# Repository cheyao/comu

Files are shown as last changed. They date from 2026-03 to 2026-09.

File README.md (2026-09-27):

# Comu

A bite-sized CH32V203 board that fits inside your USB port.

Intrested? Sign up to the [newsletter](https://cyao.dev/subscribe.html) for info! I might do a Crowd Supply campaign if there's intrest. (No spam and very infrequent emails I promise)

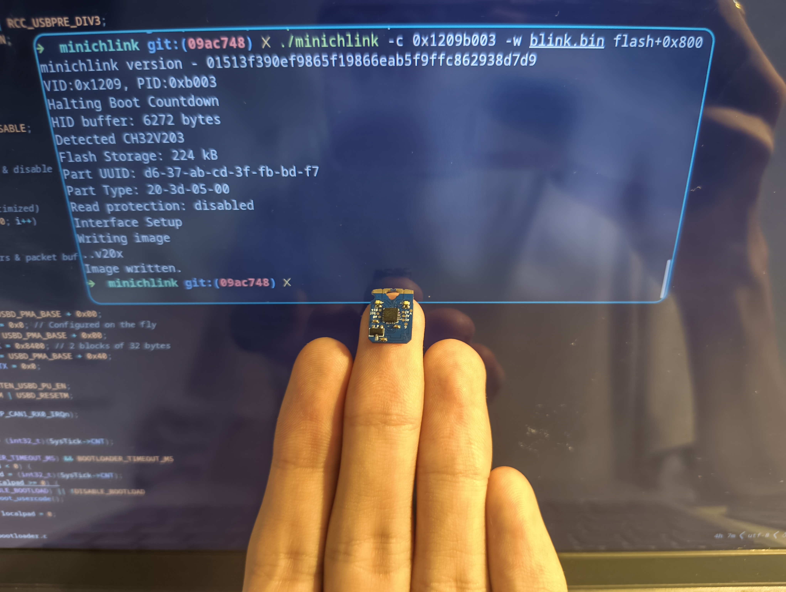
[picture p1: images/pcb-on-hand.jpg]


Comu is a tiny CH32V203 RISC-V computer that fits inside a USB port. It is user programmable, fitted with a custom bootloader, has four captive touch buttons and two LEDs. The board is supported by [ch32fun](https://github.com/cnlohr/ch32fun), allowing easy and lightweight RISC-V bare-metal development.

The CH32V203 is equipped with 248KB of Flash and 20KB of SRAM, more than enough for most embedded applications. The chip also has a wide array of peripherals, including DMA and a 12bit ADC, allowing for a wide variety of uses. The board also exposes 6 GPIO pins via testpoints, allowing it to be embedded on custom boards for further use.

It can also easily act as a **USB HID device**, allowing portable key injections to avoid repetitive typing. With it 4 captive buttons, you can make it into a sliding volume adjuster, computer sleep trigger, screen capture device and more!

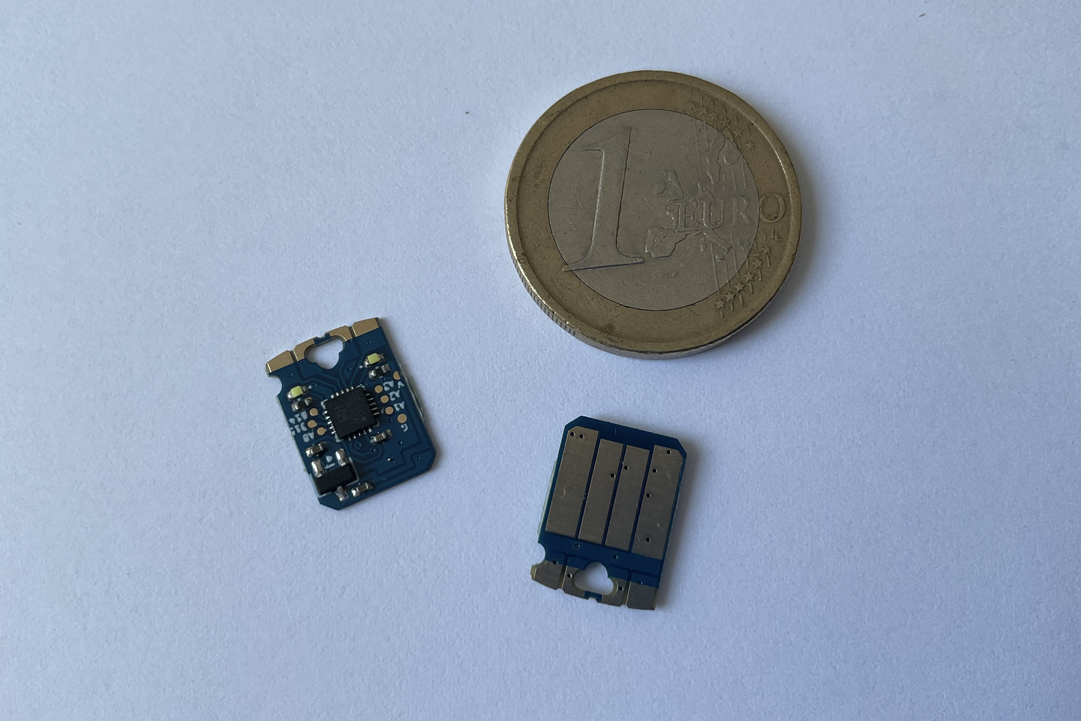
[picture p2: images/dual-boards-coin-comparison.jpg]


### No bloat, no weight

Using bare-metal programming in C/C++, the RISC-V program created for this chip contains 0 bloat. The minimal size of a blinky is only **40 bytes**, compared to 324KB on Arduino Pico or 12KB with Pico SDK. The [CH32V203 RM](https://www.wch-ic.com/downloads/CH32FV2x_V3xRM_PDF.html) contains all information needed to use the MCU, from register descriptions to memory layout.

The board is also very lightweight, weighing merely **0.4g** (0.2g without case). Measuring a mere 13x9.4mm, it occupies nearly no space.

Even in such constrained space, the board still boasts rich peripherals. You can directly access 2 white LEDs and 4 captive buttons. The captive buttons are double-sided edge-plated, ensuring accurate touch sensing. It is also easy to use thanks to the CH32V203's touchkey peripheral, directly handling all the troublesome parts of touch sensing. (Example in `examples/touch` folder).

### USB explorer

The CH32V203 is perfect for USB packet exploring. Its bare and well-documented USBD peripheral allows you to manipulate raw packets, while taking care of troublesome parts such as transaction handling. You can directly pair this with [usbmon](https://docs.kernel.org/usb/usbmon.html) on Wireshark to explore how USB transactions work.

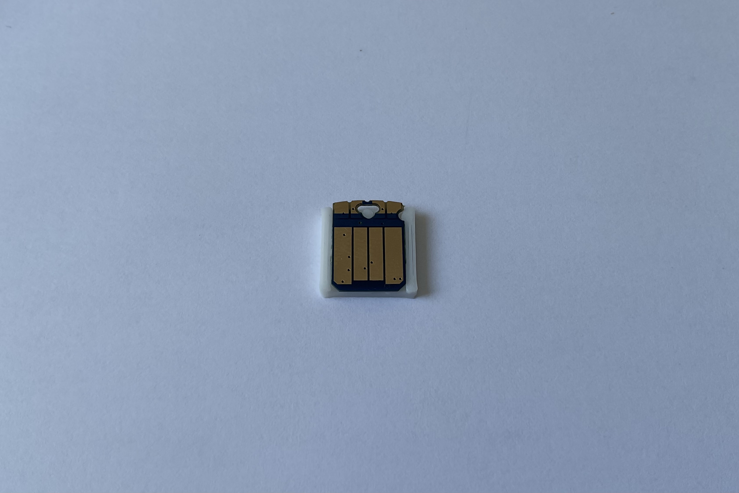
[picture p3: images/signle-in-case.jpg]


### Custom bootloader

The board comes pre-programmed with a sleek custom USB bootloader to compensate for the lack of a BOOT0 button and the large size of the official bootloader. The custom bootloader is only **2KiB** in size, freeing up the 28KiB of boot flash for user use.

The bootloader is also completely open source; check out its source code in the `bootloader` folder. The only quirk is that the programs must be linked to `0x800` and flashed to 0x800, but that is taken care by the provided Makefile in the examples folder.

### Bare metal isn't your thing?

No worries! The CH32V203 is also supported by a wide array of tools: Rust via [ch32-hal](https://github.com/ch32-rs/ch32-hal), Arduino via [arduino_core_ch32](https://github.com/openwch/arduino_core_ch32), or normal WCH-HAL via [Mounriver Studio II](https://mounriver.com/download).

USB communication can be completely handled by libraries such as [tinyusb](https://docs.tinyusb.org/en/latest/index.html) or [ch32fun's usbd lib](https://github.com/cnlohr/ch32fun/blob/master/extralibs/usbd.c). All raw peripherals can also be hidden by Mounriver's HAL.

### Tons of examples

There are tons of examples in the `examples` folder on this repo, and also compatible with the examples in [ch32fun](https://github.com/cnlohr/ch32fun).

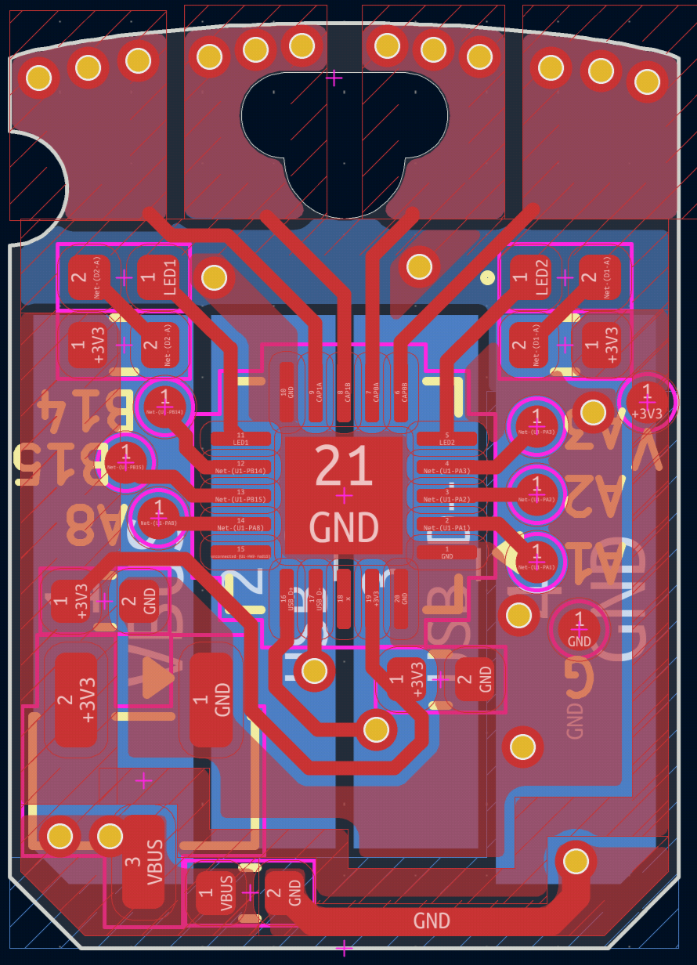
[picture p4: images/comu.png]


### Features

- [CH32V203](https://wch-ic.com/products/CH32V203.html) 32bit RISC-V MCU
    - 224KB Flash, 24KB Boot Flash, 20KB SRAM (64KB 0-wait Flash and 160KB Normal Flash)
    - 144MHz with internal oscillator
    - 12bit ADC
    - 49.3 μA/MHz @ run and 19.4 μA/MHz @ sleep
    - USB full speed peripheral
- 4x Captive touch buttons w/ castellated edges
- 2x LEDs
- 6x GPIOs broken out via testpads
- Fits in a USB-A connector

### Pins

- LED1: PB11
- LED2: PA4
- Captive touch:
    - A5 (PA5)
    - A7 (PA7)
    - A8 (PB0)
    - A9 (PB1)
- GPIOs: PB14, PB15, PA1, PA2, PA3, PA8

### Usage

Dependencies: Make, riscv64-gcc, libusb (Checkout dependency list [here](https://github.com/cnlohr/ch32fun/wiki/Installation))

Clone this respository and pull the submodules:

```
$ git clone https://github.com/cheyao/comu
$ cd comu
$ git submodule update --init --recursive
```

Go into the examples folder and build an example:

```
$ cd examples/blink
$ make
```

Now, the example should be built. When you insert your Comu into your USB port, it should stay in the bootloader for the first 5 seconds. You can then re-run `make flash` to flash the binary onto the chip!

Now you can make your applications! I recommend starting off by copying an example, as you need to flash to address `flash+0x800` to avoid overwriting the custom bootloader.

If the flashing isn't working, please read through this [wiki](https://github.com/cnlohr/ch32fun/wiki/Installation) for operating system setup, and try re-building minichnlink. (I've submitted a few new patches for the ch32v203 flashing a week ago)

### Can I get one?

### Attributions

Form factor credit goes to tomu.

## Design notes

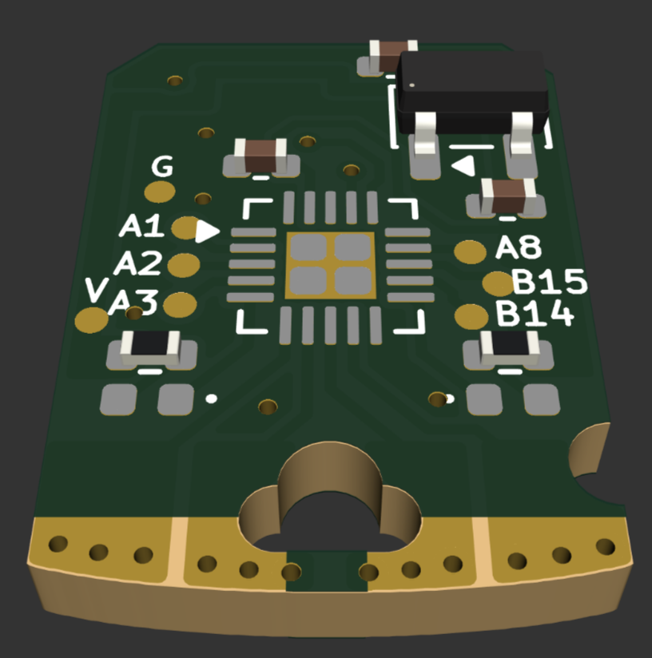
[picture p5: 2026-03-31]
images/3d.png

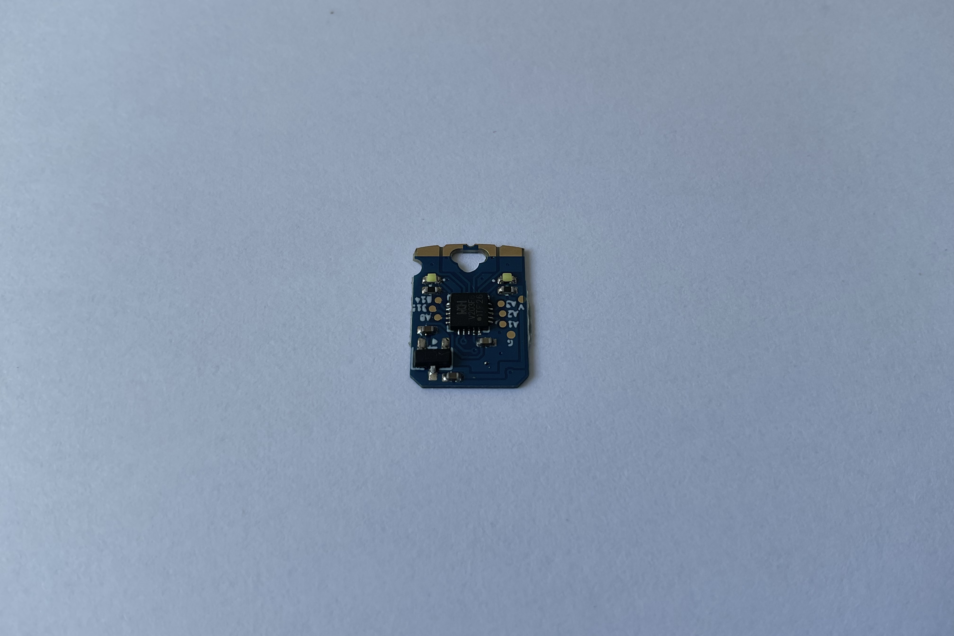
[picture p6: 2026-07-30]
images/single-top.jpg

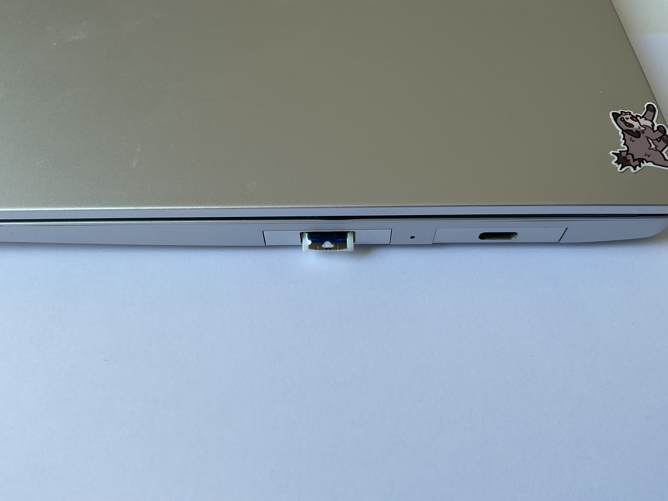
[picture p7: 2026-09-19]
images/laptop-inserted.jpg

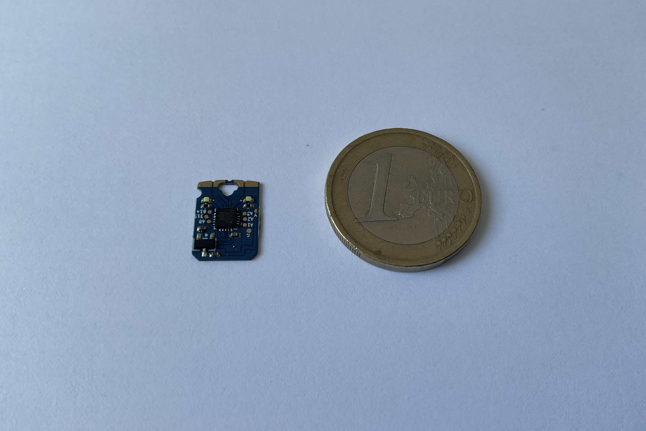
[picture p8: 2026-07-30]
images/single-coin-comparison.jpg

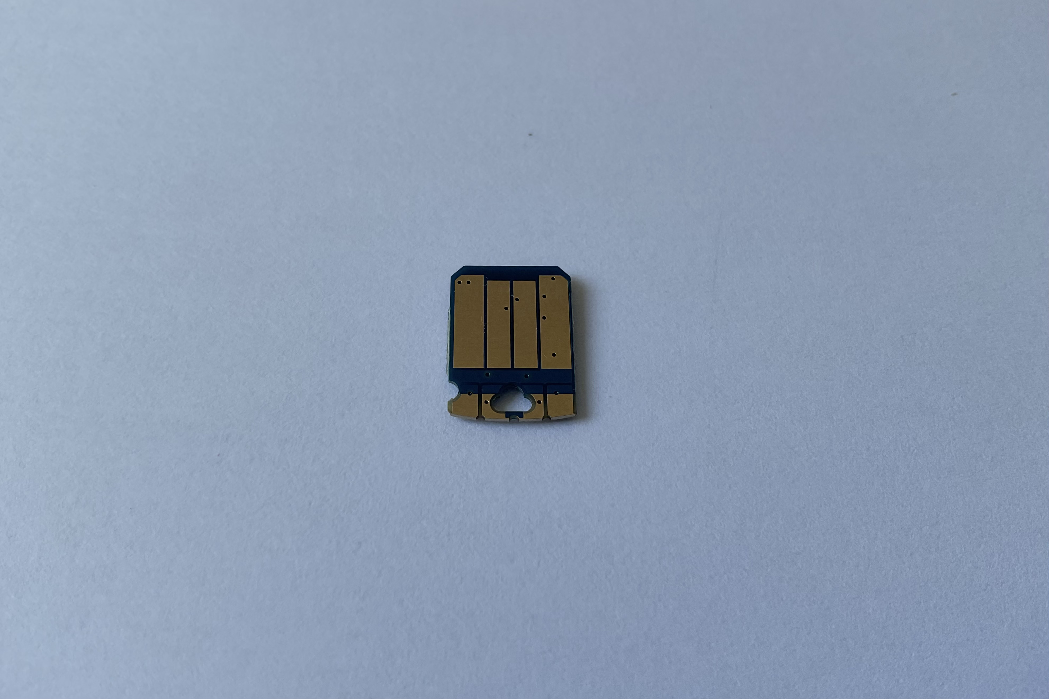
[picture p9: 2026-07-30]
images/single-bottom.jpg

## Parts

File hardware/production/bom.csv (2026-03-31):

Designator | Footprint | Quantity | Value | LCSC Part #
C1_56, C1_55, C1_54, C1_53, C1_52, C1_51, C1_50, C1_49, C1_48, C1_47, C1_46, C1_45, C1_44, C1_43, C1_42, C1_41, C1_40, C1_39, C1_38, C1_37, C1_36, C1_35, C1_34, C1_33, C1_32, C1_31, C1_30, C1_29, C1_28, C1_27, C1_26, C1_25, C1_24, C1_23, C1_22, C1_21, C1_20, C1_19, C1_18, C1_17, C1_16, C1_15, C1_14, C1_13, C1_12, C1_11, C1_10, C1_9, C1_8, C1_7, C1_6, C1_5, C1_4, C1_3, C1_2, C1, C2_56, C2_55, C2_54, C2_53, C2_52, C2_51, C2_50, C2_49, C2_48, C2_47, C2_46, C2_45, C2_44, C2_43, C2_42, C2_41, C2_40, C2_39, C2_38, C2_37, C2_36, C2_35, C2_34, C2_33, C2_32, C2_31, C2_30, C2_29, C2_28, C2_27, C2_26, C2_25, C2_24, C2_23, C2_22, C2_21, C2_20, C2_19, C2_18, C2_17, C2_16, C2_15, C2_14, C2_13, C2_12, C2_11, C2_10, C2_9, C2_8, C2_7, C2_6, C2_5, C2_4, C2_3, C2_2, C2 | 0402 | 112 | 1uF | C52923
C3_56, C3_55, C3_54, C3_53, C3_52, C3_51, C3_50, C3_49, C3_48, C3_47, C3_46, C3_45, C3_44, C3_43, C3_42, C3_41, C3_40, C3_39, C3_38, C3_37, C3_36, C3_35, C3_34, C3_33, C3_32, C3_31, C3_30, C3_29, C3_28, C3_27, C3_26, C3_25, C3_24, C3_23, C3_22, C3_21, C3_20, C3_19, C3_18, C3_17, C3_16, C3_15, C3_14, C3_13, C3_12, C3_11, C3_10, C3_9, C3_8, C3_7, C3_6, C3_5, C3_4, C3_3, C3_2, C3 | 0402 | 56 | 100nF | C1525
D1_56, D1_55, D1_54, D1_53, D1_52, D1_51, D1_50, D1_49, D1_48, D1_47, D1_46, D1_45, D1_44, D1_43, D1_42, D1_41, D1_40, D1_39, D1_38, D1_37, D1_36, D1_35, D1_34, D1_33, D1_32, D1_31, D1_30, D1_29, D1_28, D1_27, D1_26, D1_25, D1_24, D1_23, D1_22, D1_21, D1_20, D1_19, D1_18, D1_17, D1_16, D1_15, D1_14, D1_13, D1_12, D1_11, D1_10, D1_9, D1_8, D1_7, D1_6, D1_5, D1_4, D1_3, D1_2, D1, D2_56, D2_55, D2_54, D2_53, D2_52, D2_51, D2_50, D2_49, D2_48, D2_47, D2_46, D2_45, D2_44, D2_43, D2_42, D2_41, D2_40, D2_39, D2_38, D2_37, D2_36, D2_35, D2_34, D2_33, D2_32, D2_31, D2_30, D2_29, D2_28, D2_27, D2_26, D2_25, D2_24, D2_23, D2_22, D2_21, D2_20, D2_19, D2_18, D2_17, D2_16, D2_15, D2_14, D2_13, D2_12, D2_11, D2_10, D2_9, D2_8, D2_7, D2_6, D2_5, D2_4, D2_3, D2_2, D2 | 0402 | 112 | LED | C22355736
R1_56, R1_55, R1_54, R1_53, R1_52, R1_51, R1_50, R1_49, R1_48, R1_47, R1_46, R1_45, R1_44, R1_43, R1_42, R1_41, R1_40, R1_39, R1_38, R1_37, R1_36, R1_35, R1_34, R1_33, R1_32, R1_31, R1_30, R1_29, R1_28, R1_27, R1_26, R1_25, R1_24, R1_23, R1_22, R1_21, R1_20, R1_19, R1_18, R1_17, R1_16, R1_15, R1_14, R1_13, R1_12, R1_11, R1_10, R1_9, R1_8, R1_7, R1_6, R1_5, R1_4, R1_3, R1_2, R1, R2_56, R2_55, R2_54, R2_53, R2_52, R2_51, R2_50, R2_49, R2_48, R2_47, R2_46, R2_45, R2_44, R2_43, R2_42, R2_41, R2_40, R2_39, R2_38, R2_37, R2_36, R2_35, R2_34, R2_33, R2_32, R2_31, R2_30, R2_29, R2_28, R2_27, R2_26, R2_25, R2_24, R2_23, R2_22, R2_21, R2_20, R2_19, R2_18, R2_17, R2_16, R2_15, R2_14, R2_13, R2_12, R2_11, R2_10, R2_9, R2_8, R2_7, R2_6, R2_5, R2_4, R2_3, R2_2, R2 | 0402 | 112 | 1k | C11702
U1_56, U1_55, U1_54, U1_53, U1_52, U1_51, U1_50, U1_49, U1_48, U1_47, U1_46, U1_45, U1_44, U1_43, U1_42, U1_41, U1_40, U1_39, U1_38, U1_37, U1_36, U1_35, U1_34, U1_33, U1_32, U1_31, U1_30, U1_29, U1_28, U1_27, U1_26, U1_25, U1_24, U1_23, U1_22, U1_21, U1_20, U1_19, U1_18, U1_17, U1_16, U1_15, U1_14, U1_13, U1_12, U1_11, U1_10, U1_9, U1_8, U1_7, U1_6, U1_5, U1_4, U1_3, U1_2, U1 | QFN-20-1EP_3x3mm_P0.4mm_EP1.65x1.65mm | 56 | CH32V203F8U6 | C7570477
U2_56, U2_55, U2_54, U2_53, U2_52, U2_51, U2_50, U2_49, U2_48, U2_47, U2_46, U2_45, U2_44, U2_43, U2_42, U2_41, U2_40, U2_39, U2_38, U2_37, U2_36, U2_35, U2_34, U2_33, U2_32, U2_31, U2_30, U2_29, U2_28, U2_27, U2_26, U2_25, U2_24, U2_23, U2_22, U2_21, U2_20, U2_19, U2_18, U2_17, U2_16, U2_15, U2_14, U2_13, U2_12, U2_11, U2_10, U2_9, U2_8, U2_7, U2_6, U2_5, U2_4, U2_3, U2_2, U2 | SOT-23-3 | 56 | XC6206PxxxMR | C5446

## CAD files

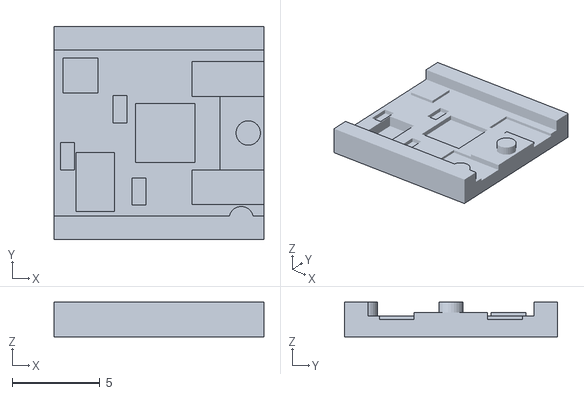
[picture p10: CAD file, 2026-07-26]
case/case-v3.stl
12.0 x 12.2 x 2.00

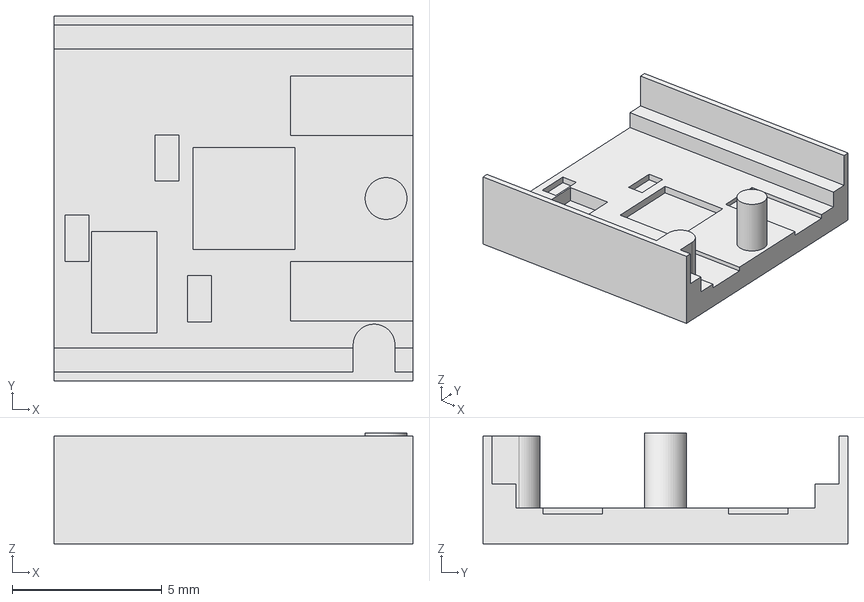
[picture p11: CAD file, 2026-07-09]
case/case-v1.step
12.0 x 12.2 x 3.70 mm

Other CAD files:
case/case.FCStd
case/case-v2.stl

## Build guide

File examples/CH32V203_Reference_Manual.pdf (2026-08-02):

# CH32F/V20x_V30x_V31x Reference Manual

V2.5
https://wch-ic.com

## Overview

CH32F20x is a general-purpose microcontroller based on the ARM○R CortexTM-M3 core, and is compatible with most ARM tools and software. It provides rich communication interfaces and control units, which are suitable for most embedded fields such as control, connection, synthesis, etc.
CH32V20x, CH32V30x and CH32V31x series are industrial-grade general-purpose microcontrollers based on 32-bit RISC-V instruction set and architecture. Different core models are matched according to the differences in product performance and resources. CH32V203 uses QingKe V4B core to support hardware interrupt stack to improve interrupt response efficiency; CH32V208 uses QingKe V4C core to further accelerate the speed of hardware division and increases memory protection; CH32V303/305/307/317 uses QingKe V4F core to further support hardware floating-point operations. This series of products are loaded with a wealth of peripheral interfaces and functional modules. Its internal organizational structure meets the low-cost and low-power embedded application scenarios.
For users' application development, this manual provides detailed use information of CH32F20x series, CH32V20x series, CH32V30x series and CH32V31x series products. It is suitable for different memory capacity, functional resources and packaged products in the series. If there are any differences, special instructions will be made in the corresponding functional chapter.
Note: (1) CH32F20x includes: CH32F203, CH32F205, CH32F207, CH32F208;
(2) CH32V20x includes:CH32V203, CH32V208;
(3) CH32V30x includes:CH32V303, CH32V305, CH32V307;
(4) CH32V31x includes:CH32V317.

Please refer to the following datasheet for the device characteristics of this series. CH32F20x_D6: CH32F203DS0
CH32F20x_D8, CH32F20x_D8C:CH32F207DS0.
CH32F20x_D8W: CH32F208DS0.
CH32V20x_D6, CH32V20x_D8: CH32V203DS0. CH32V20x_D8W:CH32V208DS0.
CH32V30x_D8, CH32V30x_D8C, CH32V31x_D8C: CH32V307DS0.

For information about the ARM○R CortexTM-M3 core, please refer to the ARM○R Cortex○R -M3 Processor Technical Reference Manual Revision r2p1, which can be downloaded from the ARM website.
For information about the RISC-V core, please refer to QingKeV4_Processor_Manual.

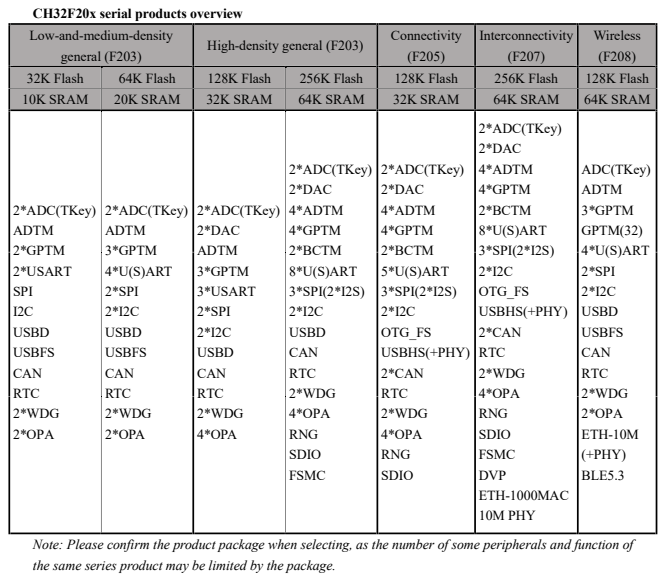
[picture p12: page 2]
Connectivity (F205); Interconnectivity (F207); Wireless (F208); 32K Flash; 64K Flash; 128K Flash; 256K Flash; 10K SRAM; 20K SRAM; 32K SRAM; 64K SRAM; 2*ADC(TKey) ADTM 2*GPTM 2*USART SPI I2C USBD USBFS CAN RTC 2*WDG 2*OPA; 2*ADC(TKey) ADTM 3*GPTM 4*U(S)ART 2*SPI 2*I2C USBD USBFS CAN RTC 2*WDG 2*OPA; 2*ADC(TKey) 2*DAC ADTM 3*GPTM 3*USART 2*SPI 2*I2C USBD CAN RTC 2*WDG 4*OPA; 2*ADC(TKey) 2*DAC 4*ADTM 4*GPTM 2*BCTM 8*U(S)ART 3*SPI(2*I2S) 2*I2C USBD CAN RTC 2*WDG 4*OPA RNG SDIO FSMC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

CH32F20x serial products overview
Low-and-medium-density
general (F203)

High-density general (F203)

Note: Please confirm the product package when selecting, as the number of some peripherals and function of
the same series product may be limited by the package.

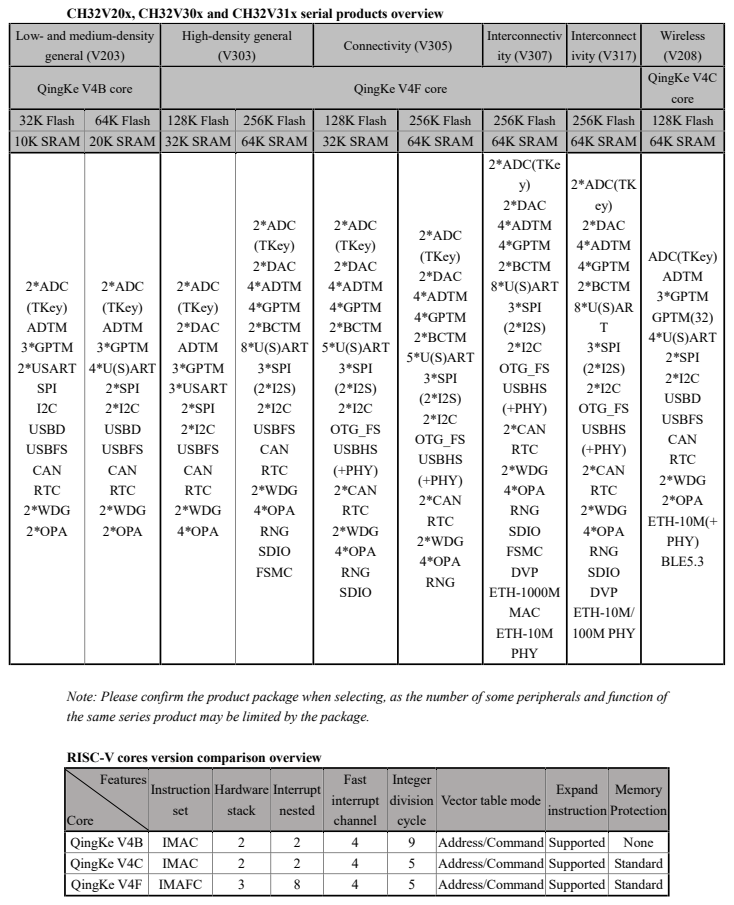
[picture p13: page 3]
Connectivity (V305); Interconnectiv ity (V307); Interconnect ivity (V317); Wireless (V208); QingKe V4B core; QingKe V4F core; QingKe V4C core; 32K Flash; 64K Flash 128K Flash 256K Flash; 128K Flash; 256K Flash; 256K Flash 256K Flash 128K Flash; 10K SRAM 20K SRAM 32K SRAM 64K SRAM 32K SRAM; 64K SRAM 64K SRAM 64K SRAM 64K SRAM; 2*ADC (TKey) ADTM 3*GPTM 2*USART SPI I2C USBD USBFS CAN RTC 2*WDG 2*OPA; 2*ADC (TKey) ADTM 3*GPTM 4*U(S)ART 2*SPI 2*I2C USBD USBFS CAN RTC 2*WDG 2*OPA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

CH32V20x, CH32V30x and CH32V31x serial products overview

Low- and medium-density
general (V203)

High-density general

Note: Please confirm the product package when selecting, as the number of some peripherals and function of
the same series product may be limited by the package.

RISC-V cores version comparison overview
Features

Vector table mode

Abbreviated description of the bit attribute in the register:
Register bit properties | Property Description
RF | Read-only property, reads a fixed value.
RO | Read-only property, changed by hardware.
RZ | Read-only property, auto bit clear 0 after read operation.
WO | Write only property (not readable, read value uncertain)
WA | Write only property, writable in safe mode.
WZ | Write only property, auto bit clear 0 after write operation
RW | Readable and writable.
RWA | Read only property, writable in safe mode.
RW1 | Readable, write 1 is valid, write 0 is invalid.
RW0 | Readable, write 0 is valid, write 1 is invalid.
RW1T | Readable, write 0 invalid, write 1 flipped.
RW1Z | Readable, write 1 to clear this bit, write 0 is invalid.
SC | Auto cleared.

Classification description of CH32 MCUs:
Classification abbreviation | Size of FLASH | Product type
D6 | 32KB or 64KB | Low-and-medium-density general
D8 | 128KB or 256KB High-density general
D8C | 128KB or 256KB Connectivity or interconnectivity
D8W | 128KB or 256KB Wireless

Note: D (Density), 6 (2^6), 8 (2^8)
Specific classification abbreviations:
CH32F20x_D6: CH32F203K8, CH32F203C6 and CH32F203C8. CH32F20x_D8: CH32F203CB, CH32F203RC, CH32F203VC and CH32F203RB.
CH32F20x_D8C: CH32F205RB and CH32F207VC.
CH32F20x_D8W: CH32F208RB and CH32F208WB.
CH32V20x_D6: CH32V203F6, CH32V203G6, CH32V203F8, CH32V203G8, CH32V203K8, CH32V203C6 and CH32V203C8.
CH32V20x_D8: CH32V203RB.
CH32V20x_D8W: CH32V208GB, CH32V208CB, CH32V208RB and CH32V208WB.
CH32V30x_D8: CH32V303CB, CH32V303RB, CH32V303RC and CH32V303VC.
CH32V30x_D8C: CH32V305FB, CH32V305RB, CH32V305GB, CH32V305CC, CH32V307RC, CH32V307WC and CH32V307VC.
CH32V31x_D8C: CH32V317SC, CH32V317WC, CH32V317VC.

CH32FV2x_V3x Reference Manual | https://wch-ic.com

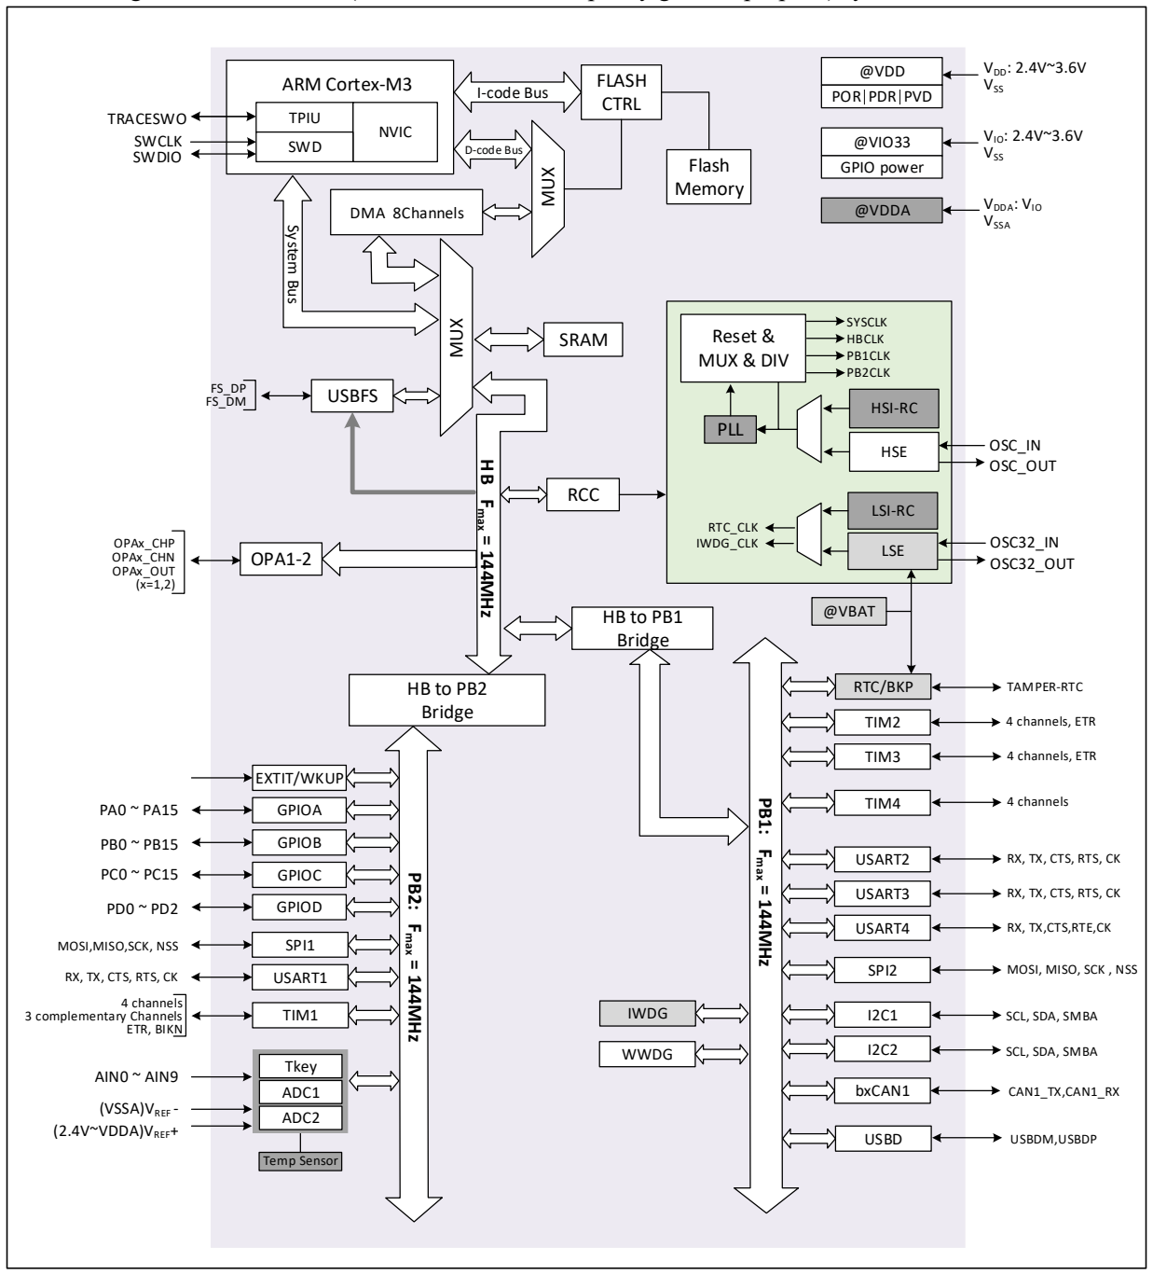
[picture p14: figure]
FLASH CTRL; Flash Memory; ARM Cortex-M3; TPIU; NVIC; SWD; SRAM; HB to PB2 Bridge; I-code Bus; D-code Bus; PB1: Fmax = 144MHz; MUX; SWCLK SWDIO; VDD: 2.4V~3.6V VSS; VDDA: VIO VSSA; TIM2; TIM3; TIM4; USART2; USART3; USART4; @VDDA; @VDD POR PDR PVD; @VIO33 GPIO power; RTC/BKP; 4 channels, ETR; 4 channels; RX, TX, CTS, RTS, CK; RX, TX,CTS,RTE,CK; VIO: 2.4V~3.6V VSS; TAMPER-RTC; System Bus; H B Fmax = 144MHz; USBFS FS_DP FS_DM; HB to PB1 Bridge; OPA1-2; OPAx_CHP OPAx_CHN OPAx_OUT (x=1,2); LSI-RC; LSE; RTC_CLK; IWDG_CLK; OSC32_IN; OSC32_OUT; @VBAT; RCC; EXTIT/WKUP; GPIOB; GPIOC; GPIOD; GPIOA; TIM1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

V2.5 | 1

## Chapter 1 Memory and Bus Architecture

## 1.1 Bus Architecture

The CH32F20x is a microcontroller designed based on the ARM○R CortexTM-M3 core. The core, arbitration unit, DMA module, and SRAM memory, etc. in the framework interact through multiple sets of buses.
The CH32V20x, CH32V30x and CH32V31x are general microcontrollers designed based on the RISC-V instruction set. The core, arbitration unit, DMA module and SRAM memory, etc. of the architecture interact through multiple sets of buses.

Figure 1-1 CH32F203 (Small-and-medium capacity general-purpose) system architecture

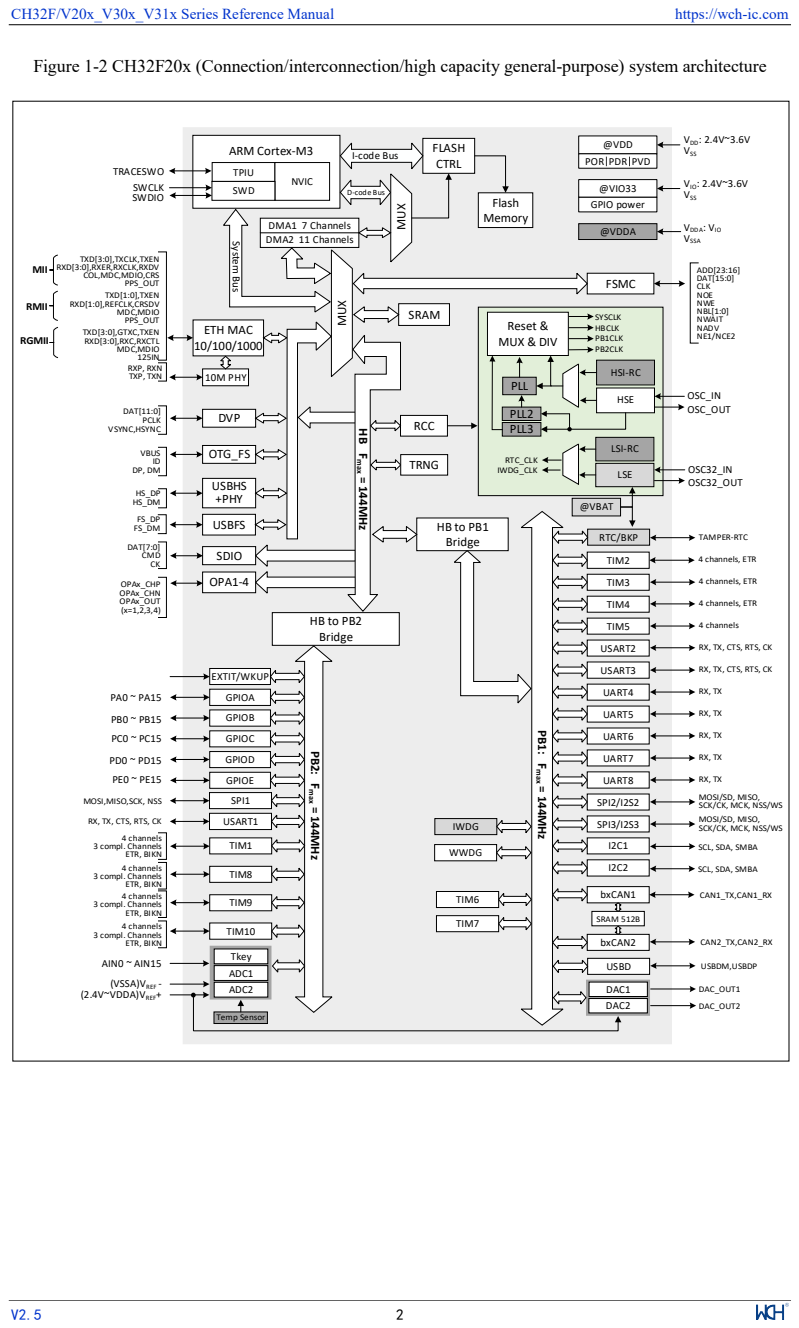
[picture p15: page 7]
CH32F/V20x_V30x_V31x Series Reference Manual; https://wch-ic.com; FLASH CTRL; Flash Memory; ARM Cortex-M3; TPIU; NVIC; SWD; SRAM; HB to PB2 Bridge; HB to PB1 Bridge; EXTIT/WKUP; GPIOB; GPIOC; GPIOD; I-code Bus; D-code Bus; PB2: Fmax = 144MHz; PB1: Fmax = 144MHz; MUX; AIN0 ~ AIN15; LSI-RC; LSE; HSE; HSI-RC; PLL; SYSCLK; Reset & MUX & DIV; HBCLK PB1CLK PB2CLK; RTC_CLK; IWDG_CLK; OSC32_IN; OSC32_OUT; OSC_IN OSC_OUT; TRACESWO SWCLK SWDIO; VDD: 2.4V~3.6V VSS; VDDA: VIO VSSA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

Figure 1-2 CH32F20x (Connection/interconnection/high capacity general-purpose) system architecture

@VDD
POR PDR PVD

TXD[3:0],TXCLK,TXEN
RXD[3:0],RXER,RXCLK,RXDV
MII

COL,MDC,MDIO,CRS
TXD[1:0],TXEN
MDC,MDIO
PPS_OUT

RXD[1:0],REFCLK,CRSDV

TXD[3:0],GTXC,TXEN
RXD[3:0],RXC,RXCTL
RXP, RXN
TXP, TXN

RX, TX, CTS, RTS, CK

MOSI/SD, MISO,
SCK/CK, MCK, NSS/WS
SCL, SDA, SMBA

MOSI,MISO,SCK, NSS

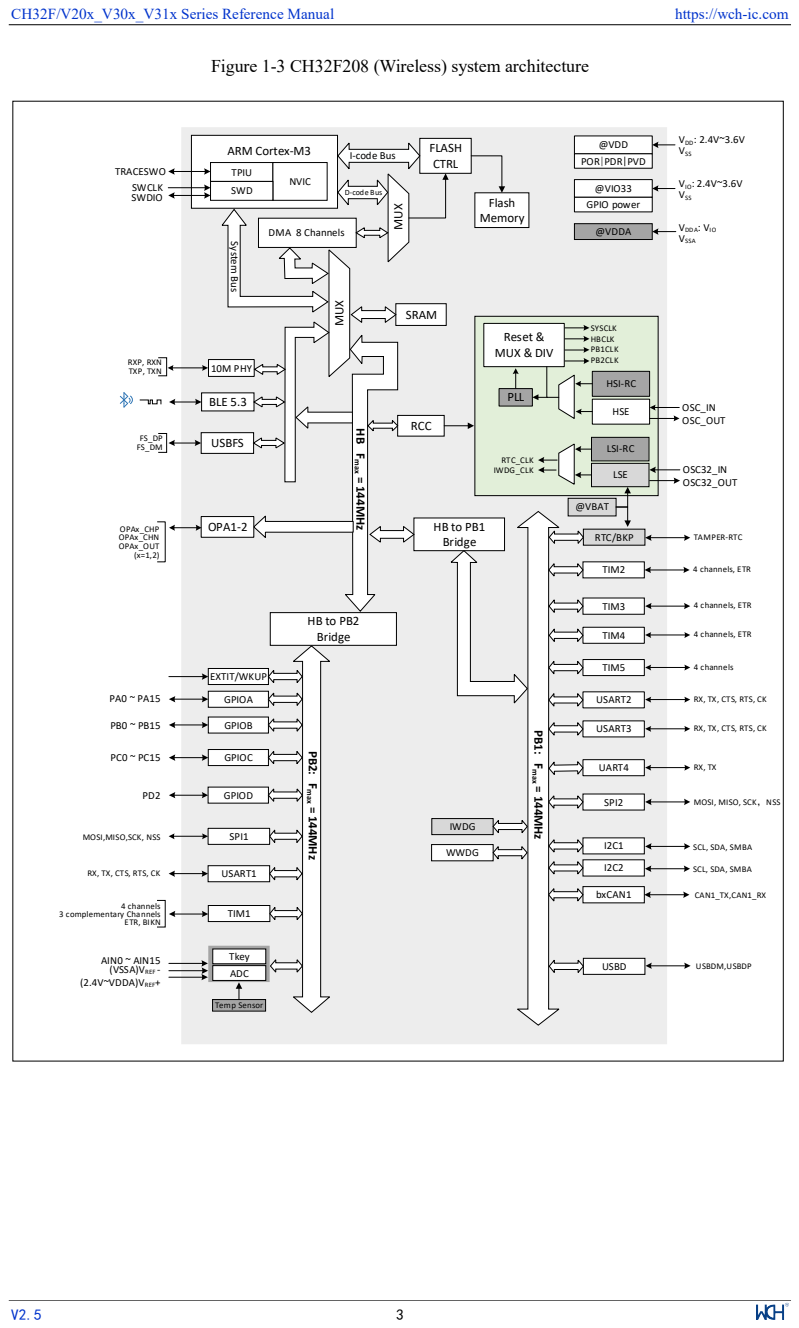
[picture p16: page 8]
FLASH CTRL; Flash Memory; ARM Cortex-M3; TPIU; NVIC; SWD; SRAM; HB to PB2 Bridge; HB to PB1 Bridge; EXTIT/WKUP; GPIOB; GPIOC; GPIOD; I-code Bus; D-code Bus; PB2: Fmax = 144MHz; PB1: Fmax = 144MHz; MUX; AIN0 ~ AIN15; LSI-RC; LSE; RTC_CLK; IWDG_CLK; OSC32_IN; OSC32_OUT; SWCLK SWDIO; VDD: 2.4V~3.6V VSS; VDDA: VIO VSSA; RCC; GPIOA; TIM1; USART1; IWDG; TIM2; TIM3; SPI2; bxCAN1; Temp Sensor; Tkey ADC; WWDG; @VDDA; RTC/BKP; @VBAT; (VSSA)VREF - (2.4V~VDDA)VREF+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

Figure 1-3 CH32F208 (Wireless) system architecture

@VDD
POR PDR PVD

MOSI, MISO, SCK，NSS

SCL, SDA, SMBA

RX, TX, CTS, RTS, CK

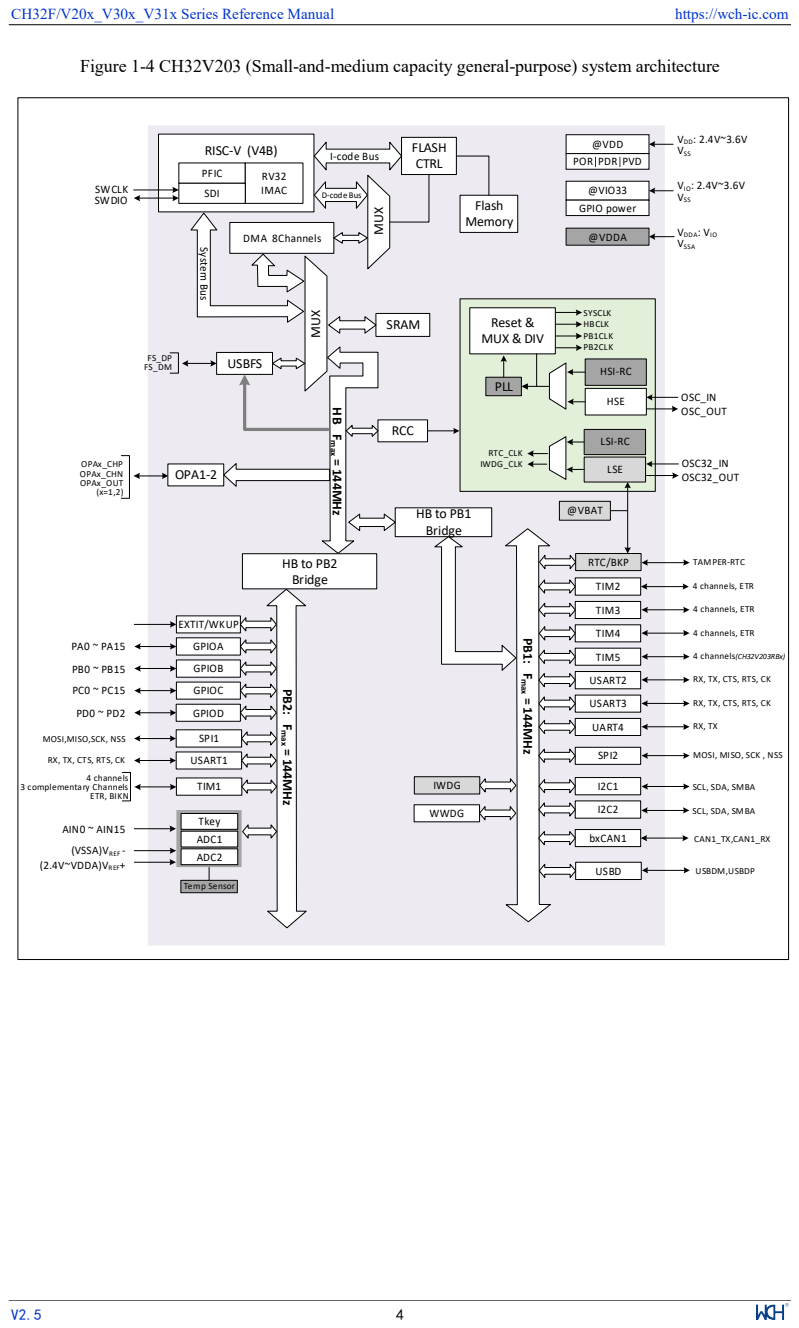
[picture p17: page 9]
FLASH CTRL; Flash Memory; RISC-V (V4B); PFIC; IMAC SDI; SRAM; HB to PB2 Bridge; I-code Bus; D-code Bus; PB1: Fmax = 144MHz; MUX; SWCLK SWDIO; VDD: 2.4V~3.6V VSS; VDDA: VIO VSSA; TIM2; TIM3; TIM4; TIM5; USART2; USART3; UART4; @VDDA; RTC/BKP; 4 channels, ETR; 4 channels(CH32V203RBx); VIO: 2.4V~3.6V VSS; TAMPER-RTC; System Bus; HB Fmax = 144MHz; USBFS FS_DP FS_DM; HB to PB1 Bridge; OPA1-2; OPAx_CHP OPAx_CHN OPAx_OUT (x=1,2); LSI-RC; LSE; RTC_CLK; IWDG_CLK; OSC32_IN; OSC32_OUT; @VBAT; RCC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

Figure 1-4 CH32V203 (Small-and-medium capacity general-purpose) system architecture

@VDD
POR PDR PVD

RX, TX, CTS, RTS, CK

MOSI,MISO,SCK, NSS

SCL, SDA, SMBA

Figure 1-5 CH32V208 (Wireless) system architecture

@VDD
POR PDR PVD

MOSI/SD, MISO,
SCK/CK, MCK, NSS/WS

SCL, SDA, SMBA

RX, TX, CTS, RTS, CK

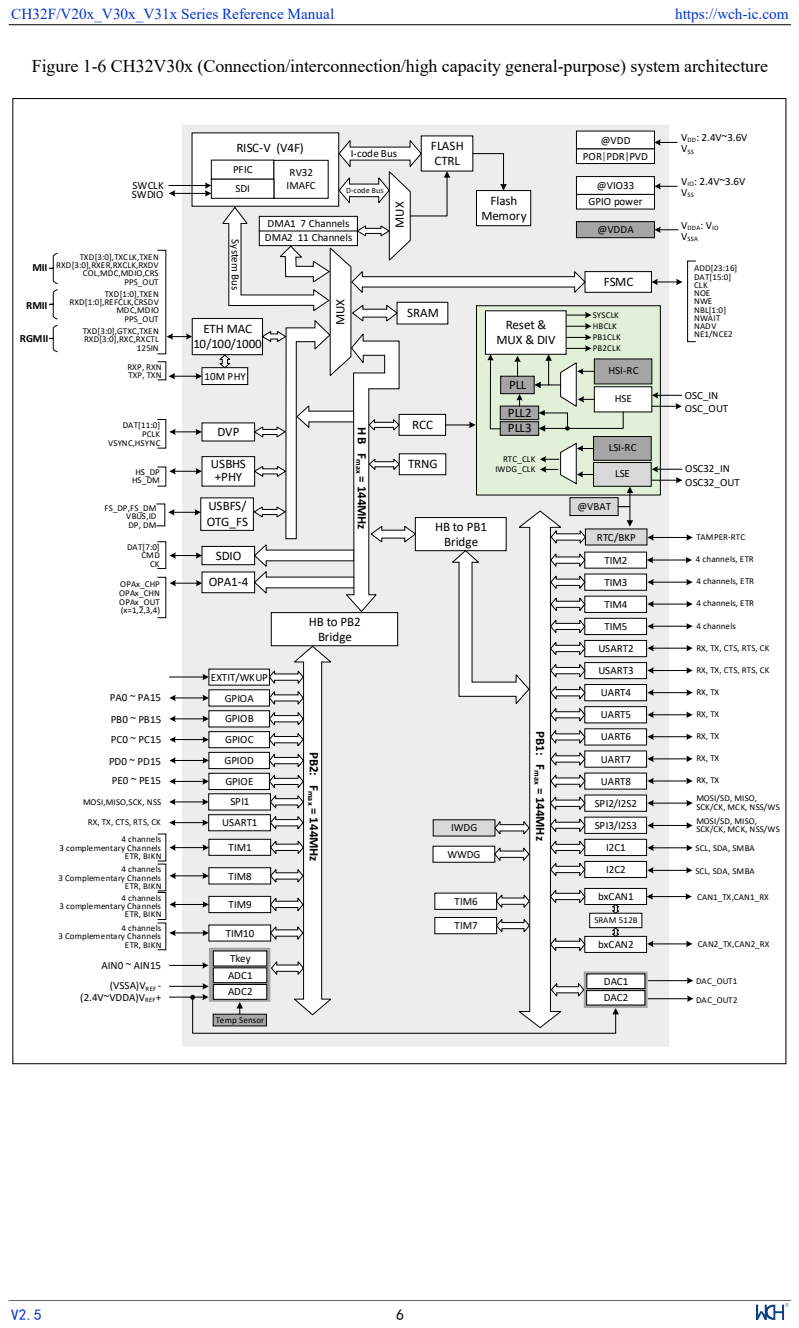
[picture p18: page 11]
FLASH CTRL; Flash Memory; RISC-V (V4F); PFIC; IMAFC SDI; SRAM; HB to PB2 Bridge; HB to PB1 Bridge; EXTIT/WKUP; GPIOB; GPIOC; GPIOD; I-code Bus; D-code Bus; PB2: Fmax = 144MHz; PB1: Fmax = 144MHz; MUX; AIN0 ~ AIN15; LSI-RC; LSE; HSE; HSI-RC; PLL; SYSCLK; Reset & MUX & DIV; HBCLK PB1CLK PB2CLK; RTC_CLK; IWDG_CLK; OSC32_IN; OSC32_OUT; OSC_IN OSC_OUT; SWCLK SWDIO; VDD: 2.4V~3.6V VSS; VDDA: VIO VSSA; DMA1 7 Channels DMA2 11 Channels; RCC; TRNG; GPIOE; GPIOA; TIM1; TIM8; TIM9; TIM10; SPI1; USART1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

Figure 1-6 CH32V30x (Connection/interconnection/high capacity general-purpose) system architecture

@VDD
POR PDR PVD

TXD[3:0],TXCLK,TXEN
RXD[3:0],RXER,RXCLK,RXDV
MII

COL,MDC,MDIO,CRS
TXD[1:0],TXEN
MDC,MDIO
PPS_OUT

RXD[1:0],REFCLK,CRSDV

TXD[3:0],GTXC,TXEN
RXD[3:0],RXC,RXCTL

RX, TX, CTS, RTS, CK

MOSI/SD, MISO,
SCK/CK, MCK, NSS/WS
SCL, SDA, SMBA

MOSI,MISO,SCK, NSS

V2.5 | 7

Figure 1-7 CH32V317 (Interconnection) system architecture

The system is equipped with: General DMA controller to reduce CPU burden and improve efficiency; clock tree hierarchical management to reduce the total operating power consumption of peripherals, while being also provided with actions such as data protection mechanism and clock security system protection mechanism to increase system stability.
- The command bus (I-Code) connects the core and the FLASH command interface, and the prefetch is completed on this bus.
- The data bus (D-Code) connects the core and the FLASH data interface for constant load and debug.

V2.5 | 8
- The system bus connects the core and the bus matrix for coordinating the access of the core, DMA, SRAM and peripherals.
- The DMA bus connects the DMA HB master control interface and the bus matrix, and the bus access objects include FLASH data, SRAM and peripherals.
- The bus matrix is used for the access coordination among the system bus, data bus, DMA bus, SRAM and HB/APB bridge.
- The HB/PB bridge provides a synchronous connection for the HB bus and 2 PB buses. Different peripherals are connected to different PB buses, and different bus clocks can be configured according to actual needs to optimize performance.

## 1.2 Memory Image

The CH32F20x, CH32V20x, CH32V30x and CH32V31x all have program memory, data memory, core register, peripheral register, etc., all of which are addressed in a 4GB linear space.
The system memory stores data in little-endian format, i.e., the low bytes are stored in the low address, and the high bytes are stored in the high address.

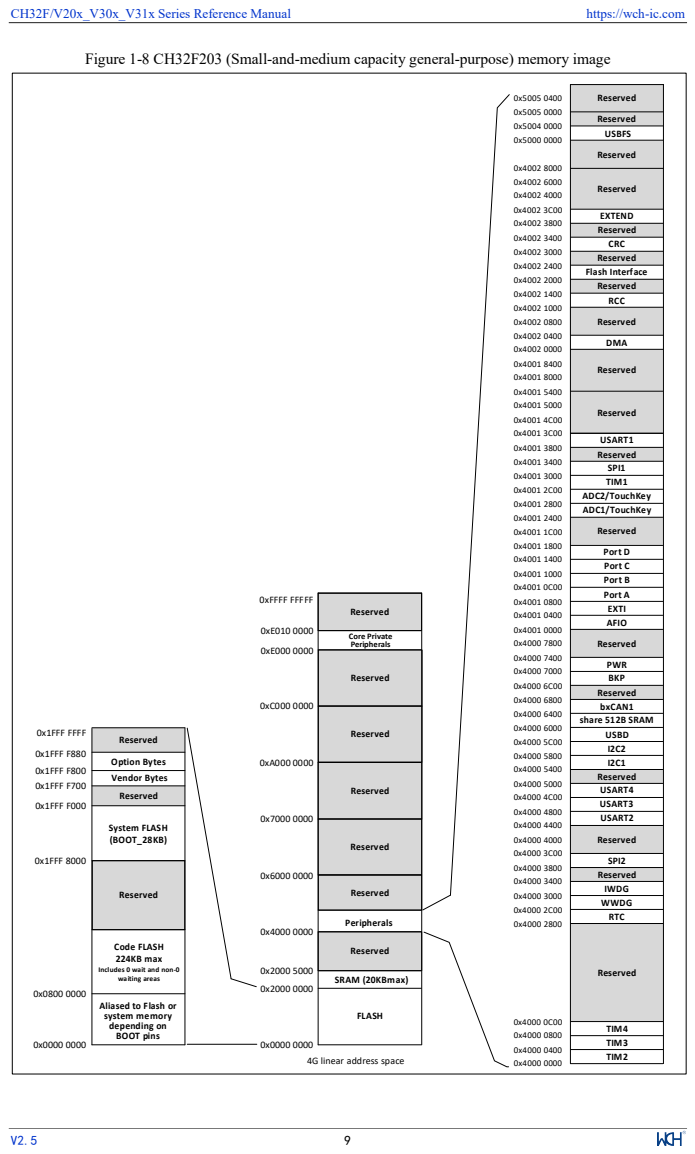
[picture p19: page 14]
Reserved; USBD; TIM3; TIM4; RTC; WWDG; IWDG; SPI2; share 512B SRAM; bxCAN1; BKP; PWR; AFIO; EXTI; Port A; Port B; Port C; Port D; ADC1/TouchKey; TIM1; SPI1; DMA; RCC; Flash Interface; CRC; EXTEND; USART2; USART3; USART4; ADC2/TouchKey; USART1; TIM2; Vendor Bytes; Option Bytes; Peripherals; SRAM (20KBmax); 0x1FFF 8000; 0xFFFF FFFFF; Core Private; FLASH; 0x1FFF F000; 0x1FFF F800; 0x1FFF FFFF; System FLASH (BOOT_28KB); 0x1FFF F880; BOOT pins; 0x1FFF F700; USBFS

Figure 1-8 CH32F203 (Small-and-medium capacity general-purpose) memory image

Code FLASH
224KB max
Includes 0 wait and non-0
waiting areas

Aliased to Flash or
system memory
depending on

4G linear address space

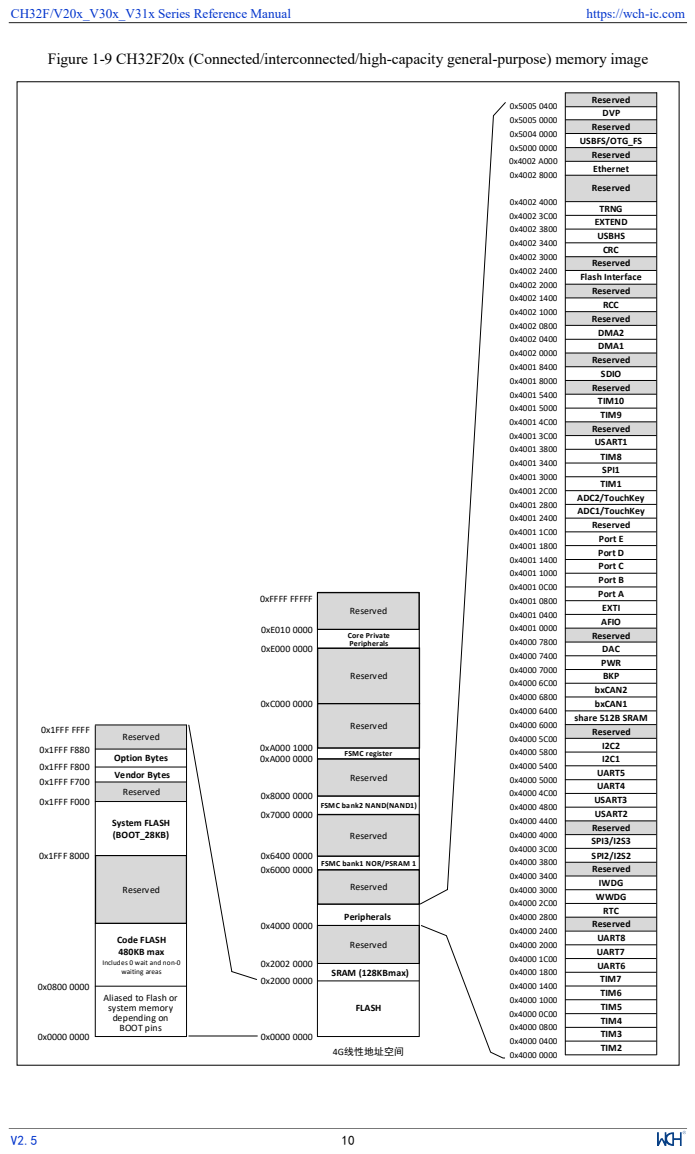
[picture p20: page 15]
Reserved; Reserved DVP Reserved; TIM3; TIM4; RTC; WWDG; IWDG; SPI2/I2S2; share 512B SRAM; bxCAN1; BKP; PWR; AFIO; EXTI; Port A; Port B; Port C; Port D; ADC1/TouchKey; TIM1; SPI1; TIM9; DMA1; RCC; Flash Interface; CRC; EXTEND; DAC; TIM5; TIM6; TIM7; UART6; UART7; UART8; SPI3/I2S3; USART2; USART3; UART4; UART5; Port E; ADC2/TouchKey; DMA2; USBHS; TIM8; USART1; TIM10; Reserved SDIO; TRNG; TIM2; Vendor Bytes; Option Bytes; 4G线性地址空间; Peripherals; SRAM (128KBmax); 0x1FFF 8000; 0xFFFF FFFFF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

Figure 1-9 CH32F20x (Connected/interconnected/high-capacity general-purpose) memory image

FSMC bank1 NOR/PSRAM 1

Code FLASH
480KB max
Includes 0 wait and non-0
waiting areas

Aliased to Flash or
system memory
depending on

Figure 1-10 CH32F208 (Wireless) memory image

Code FLASH
480KB max
Include s 0 wait and non-0
waiting areas

Aliased to Flash or
system memory
depending on

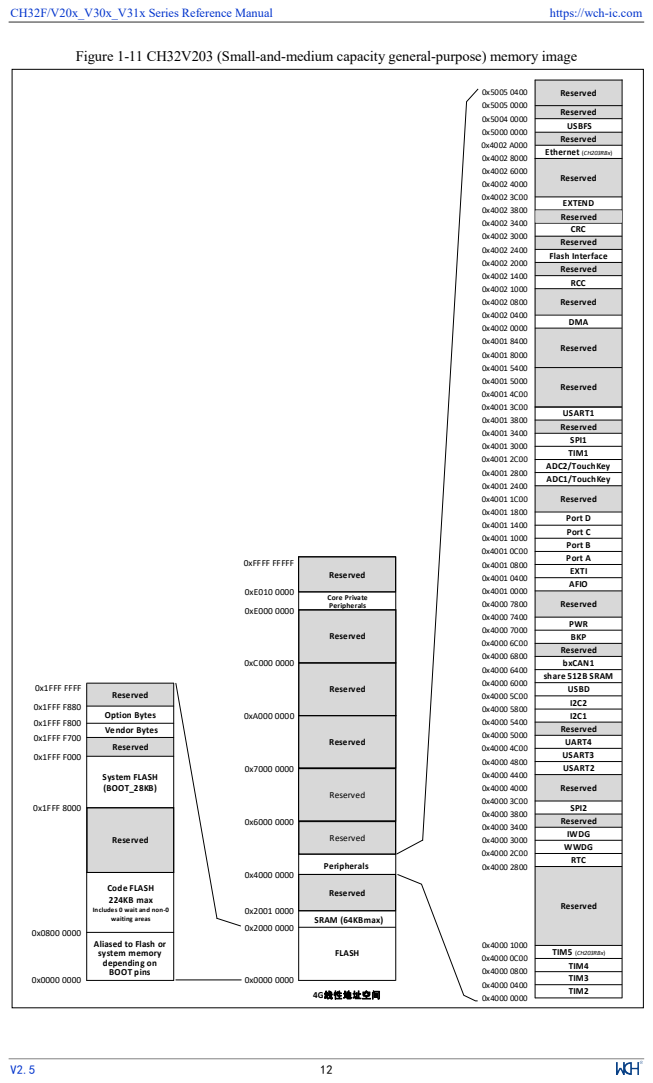
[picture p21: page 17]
Reserved; USBD; TIM3; TIM4; RTC; WWDG; IWDG; SPI2; share 512B SRAM; bxCAN1; BKP; PWR; AFIO; EXTI; Port A; Port B; Port C; Port D; ADC1/TouchKey; TIM1; SPI1; DMA; RCC; Flash Interface; CRC; EXTEND; TIM5 (CH203RBx); USART2; USART3; UART4; ADC2/TouchKey; USART1; TIM2; Vendor Bytes; Option Bytes; 4G线性地址空间; Peripherals; SRAM (64KBmax); 0x1FFF 8000; 0xFFFF FFFFF; Core Private; FLASH; 0x1FFF F000; 0x1FFF F800; 0x1FFF FFFF; System FLASH (BOOT_28KB); 0x1FFF F880; BOOT pins; 0x1FFF F700; USBFS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

Figure 1-11 CH32V203 (Small-and-medium capacity general-purpose) memory image

Code FLASH
224KB max
Include s 0 wait and non-0
waiting areas

Aliased to Flash or
system memory
depending on

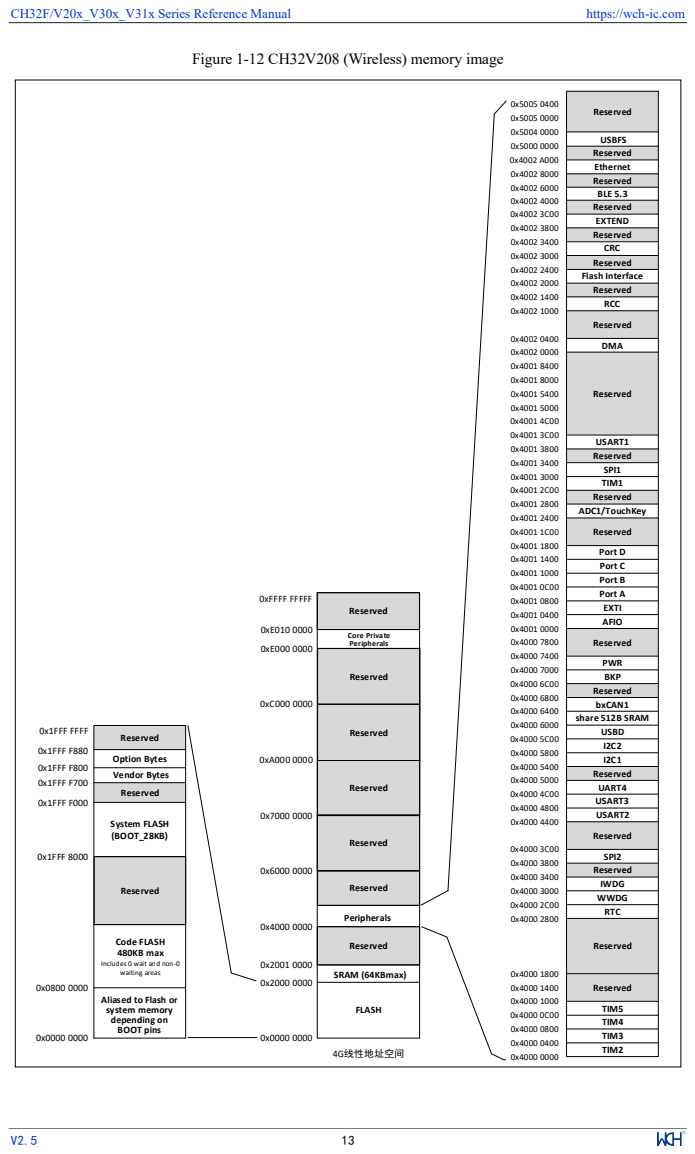
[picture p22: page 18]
Reserved; BLE 5.3; USBD; TIM3; TIM4; RTC; WWDG; IWDG; SPI2; share 512B SRAM; bxCAN1; BKP; PWR; AFIO; EXTI; Port A; Port B; Port C; Port D; ADC1/TouchKey; TIM1; SPI1; DMA; RCC; Flash Interface; CRC; EXTEND; TIM5; USART2; USART3; UART4; USART1; TIM2; Vendor Bytes; Option Bytes; 4G线性地址空间; Peripherals; SRAM (64KBmax); 0x1FFF 8000; 0xFFFF FFFFF; Core Private; FLASH; 0x1FFF F000; 0x1FFF F800; 0x1FFF FFFF; System FLASH (BOOT_28KB); 0x1FFF F880; BOOT pins; 0x1FFF F700; USBFS; Ethernet

Figure 1-12 CH32V208 (Wireless) memory image

Code FLASH
480KB max
Includes 0 wait and non-0
waiting areas

Aliased to Flash or
system memory
depending on

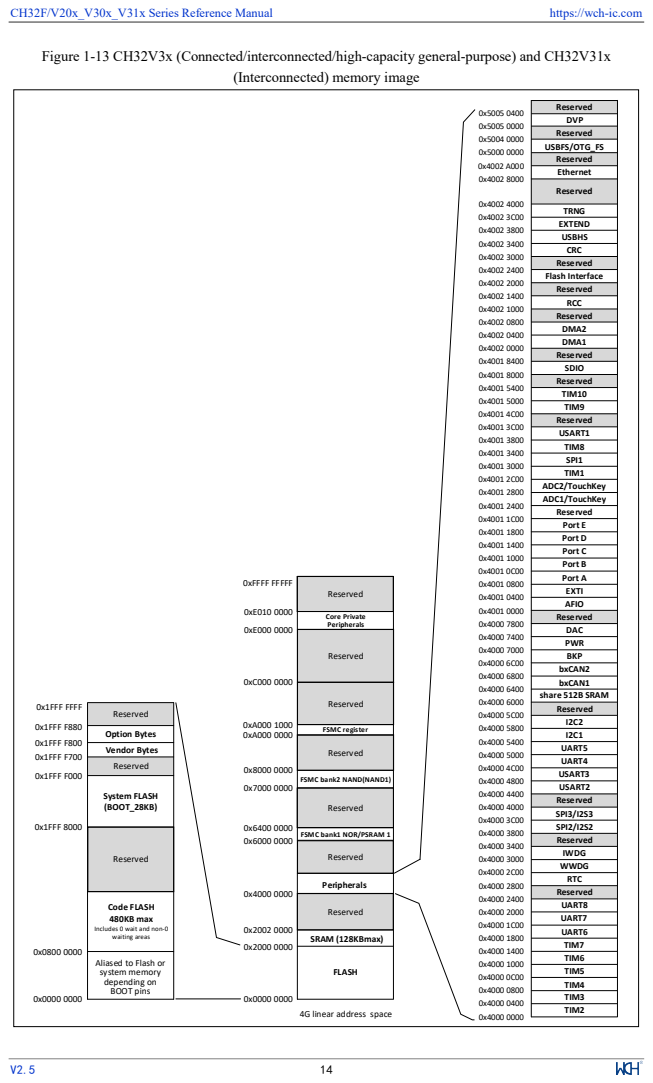
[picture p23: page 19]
Reserved; Reserved DVP Reserved; TIM3; TIM4; RTC; WWDG; IWDG; SPI2/I2S2; share 512B SRAM; bxCAN1; BKP; PWR; AFIO; EXTI; Port A; Port B; Port C; Port D; ADC1/TouchKey; TIM1; SPI1; TIM9; DMA1; RCC; Flash Interface; CRC; EXTEND; DAC; TIM5; TIM6; TIM7; UART6; UART7; UART8; SPI3/I2S3; USART2; USART3; UART4; UART5; Port E; ADC2/TouchKey; DMA2; USBHS; TIM8; USART1; TIM10; Reserved SDIO; TRNG; TIM2; Vendor Bytes; Option Bytes; Peripherals; SRAM (128KBmax); 0x1FFF 8000; 0xFFFF FFFFF; Core Private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

Figure 1-13 CH32V3x (Connected/interconnected/high-capacity general-purpose) and CH32V31x

(Interconnected) memory image

FSMC bank1 NOR/PSRAM 1
Reserved

Code FLASH
480KB max
Includes 0 wait and non-0
waiting areas

Aliased to Flash or
system memory
depending on

4G linear address space

V2.5 | 15

### 1.2.1 Bit Segment Access

Bit manipulation means the operation of reading/writing a bit independently. The CH32F20x provides bit operation read and write to the contents of peripheral register and SRAM area through the mapping processing method. Specific methods:
1) Read the 32-bit data in the mapped address area, the read value is 0 or non-zero, and the target bit value is 0 or 1;
2) Write the 32-bit data in the mapped address area, write 0 or 1, and modify the target bit value to 0 or 1.

Address mapping:
Target bit field: Base address (BEaddr) + offset address (Ofaddr) + bit number (BitN)
Mapping address: Mapaddr
Mapaddr = BEaddr +0x2000000 + (Ofaddr×32) + (BitN×4) Example 1: Operate the bit3 target bit field in the 0x20000100 address byte of the SRAM area:
Mapaddr= 0x20000000+0x2000000+(0x100*32)+(3*4)= 0x2200200C
Read the 4-byte data content of the 0x2200200C address to know whether bit3 in the 0x20000100 address byte is 0 or 1; write 0 or 1 to the 0x2200200C address, you can modify the bit3 in the 0x20000100 address byte to 0 or 1.

Example 2: Operate bit24 in the 0x40021000 address of the peripheral area:
Mapaddr = 0x40000000+0x2000000+(0x21000*32)+(24*4)= 0x42420060
Read the 4-byte data content of the 0x22420060 address to confirm whether the bit24 in the 0x40021000 peripheral address is 0 or 1; write 0 or 1 to the 0x22420060 address; you can modify the bit24 in the 0x40021000 peripheral address to 0 or 1.

Note: The CH32V20x, CH32V30x and CH32V31x do not support bit segment mapping access mode.

### 1.2.2 Memory Allocation

Built-in maximum 128 Kbytes of SRAM, start address 0x20000000, support byte, half word (2 bytes), full word (4 bytes) access.
Built-in maximum 480 Kbytes of Flash program memory, for storing user applications.
Built-in 28K bytes of system memory (Bootloader), is selected as the boot space (Manufacturer's solidified bootloading program).
Built-in 128-byte used to store the manufacturer’s configuration word, which is solidified before delivery out of the factory and cannot be modified by the user.
Built-in 128-byte space is used for user option byte storage.
Note: Memory allocation varies by model, refer to the corresponding datasheet of the chip for details.

## 1.3 Boot Configuration

The system can select 3 different boot modes through the BOOT0 and BOOT1 pins.

Table 1-1 Boot modes
BOOT0 | BOOT1 | Boot mode
0 | X | Boot from program flash memory
1 | 0 | Boot from system memory
1 | 1 | Boot from internal SRAM

The user selects the startup mode after reset by setting the status value of BOOT pins. After the system is

V2.5 | 16

reset or the power is reset, the value of the BOOT pin will be latched again.

The program flash memory, system memory and internal SRAM have different access methods in different startup modes:
- When it is started up from the program flash memory, the program flash memory address will be mapped to the 0x00000000 address area and can also be accessed in the start address area 0x08000000.
- When it is started up from the system memory, the system memory address will be mapped to the address area 0x00000000 and can also be accessed in the original address area 0x1FFF8000.
- When it is started up from the internal SRAM, it can be only accessed from 0x20000000 address area. When the CH32F20x is started up in this area, it is necessary to set the vector table offset register through the NVIC controller to remap the vector table to SRAM. For CH32V20x, CH32V30x and CH32V31x, such action is not required.

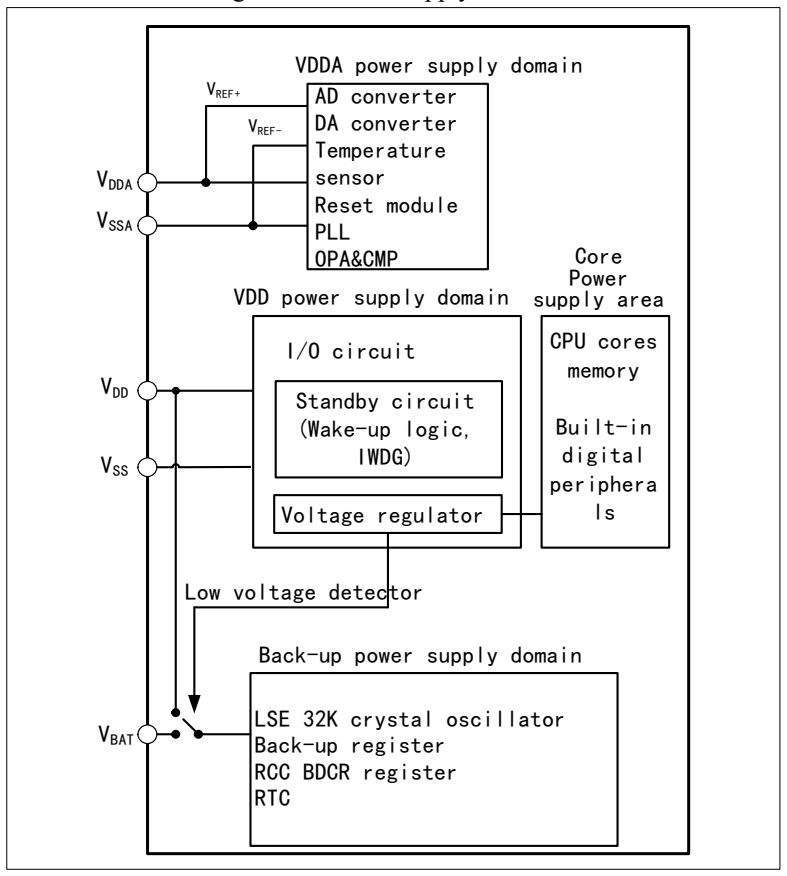
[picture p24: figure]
VDDA power supply domain AD converter DA converter Temperature sensor Reset module PLL OPA&CMP; VDD power supply domain; Core Power supply area; I/O circuit; Standby circuit (Wake-up logic, IWDG); CPU cores memory; Built-in digital periphera; Voltage regulator; Low voltage detector; Back-up power supply domain; LSE 32K crystal oscillator Back-up register RCC BDCR register RTC; VDDA; VSSA; VDD; VSS; VREF+; VREF-; VBAT

V2.5 | 17

## Chapter 2 Power Control (PWR)

This chapter applies to the whole family of CH32F20x, CH32V20x, CH32V30x and CH32V31x.

## 2.1 Overview

The CH32F20x, CH32V20x, and CH32V30x products have a system operating voltage VDD range of 2.4⁽¹⁾ to 3.6V, and the CH32V31x products have a system operating voltage VDD range of 2.4⁽¹⁾ to 3.6V, with a built-in voltage regulator to provide the operating power supply required by the core. When the main power (VDD) is off, backup power supply such as battery can supply power to the real-time clock (RTC) and backup registers through the VBAT pin. If the backup power supply is not required, it is recommended to connect VDD directly to the VBAT pin.
Note: (1) For chips with FEATURE_SIGN register VLEVEL bit 1, the system operating voltage VDD supports a minimum supply voltage of 2.4V; For chips with VLEVEL bit 0, the system operating voltage VDD supports a minimum supply voltage of 1.8V.
For CH32V31x products the following parameters are also included (refer to the CH32V307DS0 manual for specific data):
(1) VDD_ETH: Power supply for the built-in Ethernet 10/100M PHY.
(2) VDDK: Internal power LDO decoupling terminal, external decoupling capacitor is required.
The VDDA and VSSA pins are dedicated to supply power to the analog related circuits in the system, including ADC, DAC, temperature sensors, etc. As reference points of some analog circuits, VREF+ and VREF- are equal to VDDA and VSSA inside the chip.

Figure 2-1 Power supply overview

After the main power (VDD) is off, the analog switch will be turned to VBAT, and the backup area will be

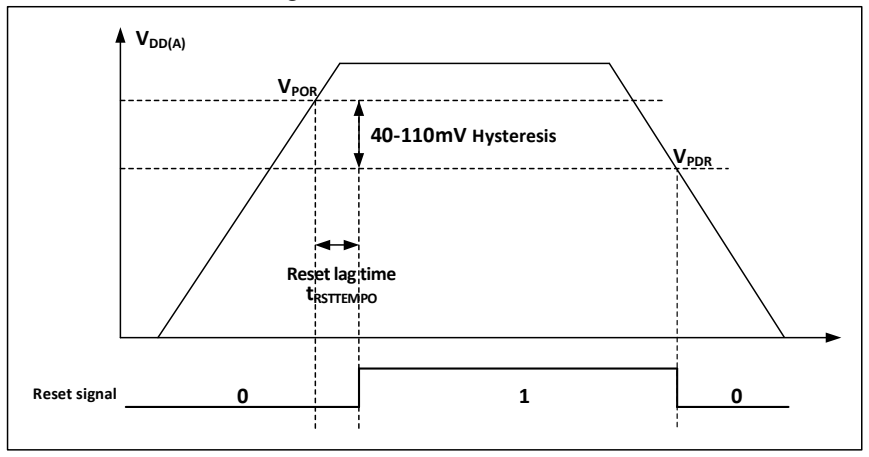
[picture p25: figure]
VDD(A); VPOR; VPDR; 40-110mV Hysteresis; Reset lag time tRSTTEMPO; Reset signal

V2.5 | 18

powered by the VBAT pin. At this time, the PC13 to PC15 IOs cannot be used as GPIOs, and only the following functions are available:
- PC13 can be used as TAMPER pin, RTC alarm or second output.
- PC14 and PC15 can be only used as LSE pins.
When the main power (VDD) is stable, the system will automatically switch the backup area powered by VDD, and the PC13 to PC15 IOs can be used as GPIOs.
When the PC13 to PC15 pins are used as GPIO output, the speed must be limited below 2MHz, the maximum load capacitance is 30pF, and it is forbidden to use it in the occasions of continuous output and draw current, such as LED drive.
Note: During the restoration of the main power supply (VDD), the internal VBAT power supply is still connected to the external backup power supply through the corresponding VBAT pin. If VDD is less than the reset delay time tRSTTEMPO, it will be stabilized and be higher than the value of VBAT by more than 0.6V, and the current may be injected into VBAT through the diode between VDD and VBAT in a very short moment. Then, the backup power supply such as the battery will be injected through the VBAT pin. If the backup power supply cannot withstand such instantaneously injected current, it is then recommended to add a positive on low-dropout diode between the backup power supply and VBAT pin.

## 2.2 Power Supply Management

### 2.2.1 Power-on Reset and Power-down Reset

The power-on reset (POR) and power-down reset (PDR) circuits are integrated inside the system. When VDD/VDDA is below the corresponding threshold, the system will be reset by the relevant circuits, without the need for an external reset circuit. Please refer to the corresponding data sheet for more details concerning the power-on threshold (VPOR) and the power-down threshold (VPDR).

Figure 2-2 POR/PDR waveform

### 2.2.2 Programmable Voltage Detector

The programmable voltage detector (PVD) is mainly used to monitor the main power of the system and compares it to the threshold selected by the PLS [2:0] bits in the power control register (PWR_CTLR). Coordinated with the external interrupt register (EXTI) setting, it can generate related interrupt to notify the system in time to perform operations before power failure such as data storage.
Configuration procedure:
1) Set the PLS [2:0] bits in the PWR_CTLR register and select the voltage threshold to be detected.
2) Optional interrupt processing. The PVD function is internally connected to the line16 of the EXTI module

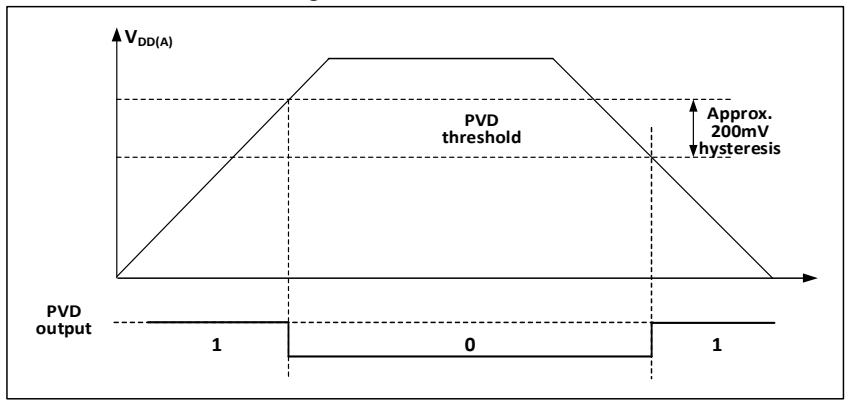
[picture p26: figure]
VDD(A); Approx. 200mV hysteresis; PVD threshold; PVD output

V2.5 | 19

to trigger the setting of rising/falling edges. Enable this interrupt (with EXTI configured). When VDD drops below the PVD threshold or rises above the PVD threshold, a PVD interrupt can be generated.
3) Set the PVDE bit in the PWR_CTLR register to enable PVD.
4) Read the PVDO bit in the PWR_CSR register to obtain the relationship between the main power supply of the current system and the threshold set by PLS [2:0] bits, and perform the corresponding soft processing. When the VDD voltage is higher than the threshold set by PLS[2:0], PVDO position 0; when the VDD voltage is lower than the threshold set by PLS[2:0], PVDO position 1.

Figure 2-3 PVD thresholds

## 2.3 Low-power Modes

After the system reset, the microcontroller is at a normal working status (Run mode). At this time, the system power can be saved by reducing the system clock frequency or disabling the peripheral clock or reducing the working peripheral clock. If the system does not need to work, the user can set the system to enter low-power mode, and let the system jump out of this status through specific events.
The microcontroller currently features 3 low-power modes, which are divided into the following modes according to the working differences of processors, peripherals and voltage regulators, etc.:
- Sleep mode: The core stops running, and all peripherals (Including the core private peripherals) are still running.
- Stop mode: Stop all clocks, and the system will continue to run after awakening.
- Standby mode: Stop all clocks, and reset the microcontroller after awakening (Power reset).

Table 2-1 List of low-power modes

Note: The SLEEPDEEP bit is the core private peripheral control bit. For CH32F20x, refer to the Cortex-M3 core manual. For CH32V20x, CH32V30x and CH32V31x, refer to the PFIC_SCTLR register.

V2.5 | 20

### 2.3.1 Low-power Configuration

- WFI and WFE
WFI: The microcontroller is woken up by an interrupt source that has an interrupt controller response. After the system wakes up, the interrupt service function is executed firstly (Except for the microcontroller reset). WFE: When a wake-up event triggers the microcontroller, it exits the low-power mode. Wake-up events include:
1) Configure an external or internal EXTI line as event mode. At this time, an interrupt controller does not need to be configured;
2) Or configure an interrupt source, which is equivalent to WFI wake-up, and the system will execute the interrupt service function first;
3) Or configure the SEVONPEND bit to enable the peripheral interrupt, but do not enable the interrupt in the interrupt controller, and the interrupt pending bit needs to be cleared after the system is wakened up.
- SLEEPONEXIT
Enable: After executing the WFI or WFE instructions, the microcontroller enters the low-power mode when it ensures that it exits all interrupt services to be processed.
Disable: After executing the WFI or WFE instructions, the microcontroller immediately enters the low-power mode.
- SEVONPEND
Enable: All interrupts or wake-up events can wake it up from the low power mode that is entered by executing WFE.
Disable: Only the interrupt or wake-up event enabled in the interrupt controller can wake it up from the low power mode that is entered by executing WFE.

### 2.3.2 Sleep Mode

In this mode, all I/O pins keep the same state as in the Run mode, and all peripheral clocks are normal, so disable useless peripheral clocks to reduce power consumption before entering sleep mode. This mode offers the lowest wake-up time.
Enter: Configure the core register control bit SLEEPDEEP=0, and power control register PDDS=0. LPDS determines the status of the internal voltage regulator. Execute WFI or WFE, and select SEVONPEND or SLEEPONEXIT.
Exit: Any interrupt or wakeup events.

### 2.3.3 Stop Mode

The stop mode is based on the core deep-sleep mode (SLEEPDEEP) combined with peripheral clock gating. The voltage regulator can be configured in a lower-power mode. In this mode, the high-frequency clocks (HSE/HSI/PLL) in the domain are stopped, SRAM and register contents are preserved, and the I/O pins keep the same state. The system can continue to run after being woken up from this mode, and HSI is the default system clock.
If Flash memory programming or an access to the PB domain is ongoing, the Stop mode entry is delayed until the memory or PB access has completed.
Modules that can work in stop mode: Independent watchdog (IWDG), real-time clock (RTC), low-frequency clock (LSI/LSE).
Enter: Configure the core register control bit SLEEPDEEP=1, and power control register PDDS=0. LPDS bit is optional. Execute WFI or WFE, and SEVONPEND and SLEEPONEXIT are optional.
Exit: Any external interrupt/event (Set in the external interrupt register).

V2.5 | 21

In stop mode, the LPDS bit can be configured. The voltage regulator works in normal mode when LPDS=0, and it is in low-power mode when LPDS=1. In low-power mode, configure RAMLV=1 in the PWR_CTRL register, to enable RAM low voltage mode and achieve the lowest power consumption.

### 2.3.4 Standby Mode

In standby mode, the voltage regulator is disabled, and all circuits except the wake-up circuit and backup domain circuit are powered down to achieve minimum power consumption. Upon exiting under specified wake-up conditions, the microcontroller is reset and undergoes a power-on reset.
Modules that can work in standby mode: Independent watchdog (IWDG), real-time clock (RTC), low-frequency clock (LSI/LSE).
Enter: Configure the core register control bit SLEEPDEEP=1, and power control register PDDS=1. Execute WFI or WFE, and SEVONPEND and SLEEPONEXIT are optional.
Exit: 1) Any events (Set in the external interrupt register), and the wake-up equivalent stop mode exits.
2) The rising edge of the WKUP pin, the rising edge of the RTC alarm event, the external reset and the IWDG reset on the NRST pin. After this wake-up, the microcontroller will perform a power reset. In standby mode: when it is supplied normally, configure R2KSTY=1 in the PWR_CTLR register, to keep the 2K-byte RAM on, and configure R30KSTY=1, to keep the 30K-byte RAM on. When it is supplied by VBAT, configure R2KVBAT=1 in the PWR_CTLR register, to keep the 2K-byte RAM on, and configure R32KVBAT=1 to keep the 30K-byte RAM on. On this basis, configure RAMLV=1 in the PWR_CTRL register, to enable RAM low-voltage mode and achieve the lowest power consumption.
Note: In debug mode, if the microprocessor enters the stop or standby mode, the debug connection is lost. R2KSTY=1: control 2-Kbyte RAM with addresses ranging from 0x20000000 to 0x20000000+2K. R30KSTY=1: control 30-Kbyte RAM with addresses ranging from 0x20000000+2K to 0x20000000+2K+30K.

### 2.3.5 RTC Auto-wakeup

RTC can be used to automatically wake up the MCU without depending on an external interrupt. By programming the time base, it can wake up from stop or standby mode at regular intervals.
An external low-power 32.768kHz crystal oscillator (LSE) can be selected as the RTC clock source, or an internal oscillator (LSI) can be selected as the RTC clock source. The accuracy and power consumption indicator of LSI are worse than those of LSE.
The RTC alarm event is able to wake up the MCU from the Shutdown mode, in order to realize this function, it is necessary to configure the external interrupt line 17 and set the RTC to generate alarm events. To wake up the MCU from Standby mode, only the RTC needs to be set to generate an alarm event.

## 2.4 Register Description

Table 2-2 PWR registers

V2.5 | 22

### 2.4.1 Power Control Register (PWR_CTLR)

Offset address: 0x00
31 | 30 | 29 | 28 | 27 | 26 | 25 | 24 | 23 22 21 | 20 | 19 | 18 | 17 | 16
Reserved | RAML
V

R30K
VBAT

R2KV
BAT

R30K
STY

R2KS
TY
15 | 14 | 13 | 12 | 11 | 10 | 9 | 8 | 7 | 6 | 5 | 4 | 3 | 2 | 1 | 0
Reserved | DBP | PLS[2:0] | PVDE CSBF CWUF PDD
| | | | | | | | | | | | | | S | LPDS
Bit | Name | Access | Description | Reset value
[31:21] Reserved | RO Reserved | 0
20 | RAMLV | RW | RAM low voltage mode enable (Lower power consumption):
0: Disable; | 1: Enable.
| | | Note: Valid when the LPDS bit of PWR_CTLR register is 1. | 0
19 | R30KVBAT | RW

30K RAM power enable in Standby mode when VBAT supplies power:
0: Power disabled; | 1: Power enabled.
Note: Applied for CH32F20x_D8, CH32F20x_D8C,
CH32V30x_D8, | CH32V30x_D8C, | CH32V31x_D8C,
CH32V20x_D8, CH32V20x_D8W and CH32F20x_D8.

0

18 | R2KVBAT | RW

When VBAT is powered, whether the 2K RAM is charged in Standby mode or not:
0: Not charged; | 1: Charged;
Note: Applicable to CH32F20x_D8, CH32F20x_D8C,
CH32V30x_D8, | CH32V30x_D8C, | CH32V31x_D8C,
CH32V20x_D8, CH32V20x_D8W, CH32F20x_D8.
When VBAT is powered, whether the 20K RAM in Standby mode is charged control bit:
0: Not charged; | 1: Charged;
Note: Suitable for CH32F20x_D6, CH32V20x_D6.

0

17 | R30KSTY | RW

30K RAM power enable in Standby mode:
0: Not charged; | 1: Charged;
Note: Applied for CH32F20x_D8, CH32F20x_D8C,
CH32V30x_D8, | CH32V30x_D8CV, | CH32V31x_D8C,
CH32V20x_D8, CH32V20x_D8W and CH32F20x_D8.

0

16 | R2KSTY | RW

Whether the 2K RAM is charged with control bits in Standby mode:
0: Not charged; | 1: Charged;
Note: Applicable to CH32F20x_D8, CH32F20x_D8C,
CH32V30x_D8, | CH32V30x_D8C, | CH32V31x_D8C,
CH32V20x_D8, CH32V20x_D8W, CH32F20x_D8. Whether the 20K RAM is charged with control bits in Standby mode:
0: Not charged; | 1: Charged;
Note: Suitable for CH32F20x_D6, CH32V20x_D6.

0

V2.5 | 23
[15:9] Reserved | RO Reserved | 0
8 | DBP | RW

Write enable for the backup area:
In the reset state, all registers in the backup area are protected against write access. This bit must be set to 1 to enable write access to these registers.
0: Disable access to registers in the backup area;
1: Enable access to registers in the backup area.

0

[7:5] | PLS[2:0] | RW

PVD level selection. For details, refer to the electrical characteristics of the manual.
Applicable to products with a VLEVEL bit of 1 (VDD voltage of 2.4V):
000: 2.37V at the rising edge/2.29V at the falling edge;
001: 2.55V at the rising edge /2.46V at the falling edge;
010: 2.63V at the rising edge /2.55V at the falling edge; 011: 2.76V at the rising edge /2.67V at the falling edge; 100: 2.87V at the rising edge /2.78V at the falling edge; 101: 3.03V at the rising edge /2.93V at the falling edge; 110: 3.18V at the rising edge /3.06V at the falling edge;
111: 3.29V at the rising edge /3.19V at the falling edge.

Applicable to products with a VLEVEL bit of 0 (VDD voltage of 1.8V):
000: 2.19V at the rising edge/2.13V at the falling edge;
001: 2.33V at the rising edge /2.25V at the falling edge;
010: 2.39V at the rising edge /2.32V at the falling edge; 011: 2.48V at the rising edge /2.42V at the falling edge; 100: 2.57V at the rising edge /2.51V at the falling edge; 101: 2.69V at the rising edge /2.61V at the falling edge; 110: 2.78V at the rising edge /2.69V at the falling edge; 111: 2.88V at the rising edge /2.79V at the falling edge.

0

4 | PVDE | RW

Power voltage detector enable bit
0: Power voltage detector disabled; 1: Power voltage detector enabled;

0

3 | CSBF | RW1

Clear standby flag bit. This bit is always read as 0. 0: No effect;
1: Clear the SBF Standby Flag bit;

0

2 | CWUF | RW1

Clear wakeup flag bit. This bit is always read as 0. 0: No effect;
1: Clear the WUF after 2 system clock cycles;

0

1 | PDDS | RW

Standby/stop mode selection bit when power-down and deepsleep.
0: Enter stop mode. The regulator status depends on the LPDS bit;
1: Enter standby mode.

0

0 | LPDS | RW

Voltage regulator working mode selection bit in stop mode. It works when PDDS=0.

0

V2.5 | 24

0: The voltage regulator works in the normal mode; 1: The voltage regulator works in low-power mode.

Note: This register BIT16~BIT20 can only be reset by backup, other BITs are reset when waking up from

### 2.4.2 Power Control/Status Register (PWR_CSR)

Offset address: 0x04
31 | 30 | 29 | 28 | 27 | 26 | 25 | 24 | 23 | 22 | 21 | 20 | 19 | 18 | 17 | 16
Reserved
15 | 14 | 13 | 12 | 11 | 10 | 9 | 8 | 7 | 6 | 5 | 4 | 3 | 2 | 1 | 0
Reserved | EWUP | Reserved | PVDO SBF WUF
Bit | Name | Access | Description

Reset
value
[31:9] Reserved | RO Reserved. | 0
8 | EWUP | RW

WKUP pin enable bit
0: WKUP pin is used for general purpose I/O, and it is not used to wake up the MCU from standby mode;
1: WKUP is forced in input pull-down configuration, used to wake up the MCU from standby mode.

0

[7:3] | Reserved | RO Reserved. | 0
2 | PVDO | RO

PVD output bit. It is valid only when PVD is enabled by the PVDE in the PWR_CTLR register.
0: VDD/VDDA is higher than the PVD threshold set by the PLS[2:0] bits;
1: VDD/VDDA is lower than the PVD threshold set by the PLS[2:0] bits;

0

1 | SBF | RO

Standby flag bit, cleared by setting the CSBF bit to 1. 0: MCU is not in standby mode;
1: MCU enters standby mode;

0

0 | WUF | RO

Wake-up flag bit, cleared by setting the CWUF bit to 1.
0: No wake-up event occurred;
1: A wake-up event or RTC alarm event is detected on the WKUP pin.

0

Note: This register remains unchanged after woken up from Standby mode.

V2.5 | 25

## Chapter 3 Reset and Clock Control (RCC)

This chapter applies to the whole family of CH32F20x, CH32V20x, CH32V30x and CH32V31x.

The controller provides different types of reset and a configurable clock tree structure according to the division of power regions and taking into account the peripheral power consumption management in the application. This chapter describes the action scope of each clock in the system.

## 3.1 Main Features

- Several types of reset
- Several clock sources, bus clock management
- Built-in external crystal oscillation monitor and clock security system
- Independent management of each peripheral clock: reset, enable, disable
- Internal clock output

## 3.2 Reset

There are 3 types of reset: Power Reset, System Reset and Backup Domain Reset.

### 3.2.1 Power Reset

When power reset occurs, all registers are reset except the Backup domain (Backup domain is powered by VBAT).

A power reset is generated when one of the following events occurs:
- Power-on/power-down reset (POR/PDR)
- Wake up from standby mode

### 3.2.2 System Reset

When a system reset occurs, all registers are reset except the reset flags and backup domain in the control/status register (RCC_RSTSCKR). Identify the source of the reset event by checking the reset status flag bit in the RCC_RSTSCKR register.

A system reset is generated when one of the following events occurs:
- Low level on NRST pin (External reset)
- Window watchdog end of count condition (WWDG reset)
- Independent watchdog end of count condition (IWDG reset)
- Software reset (SW reset)
- Low-power management reset

Window/independent watchdog reset: Triggered by the counting cycle overflow of the peripheral timer of the window/independent watchdog. For detailed description, please refer to the corresponding chapters.

Software reset: CH32F20x resets the system by setting bit2 in the core register (AIRCR) to 1. For specific operations, please refer to the Cortex-M3 Core Manual. The CH32V20x, CH32V30x and CH32V31x reset the system by setting the SYSRESET bit in the interrupt configuration register (PFIC_CFGR) to 1, or by setting the SYSRESET bit in the PFIC_SCTLR register to 1. Refer to the corresponding chapters for details.

V2.5 | 26

Low-power management reset: By resetting the nRST_STDBY bit in the user option bytes, the standby mode reset is enabled. After the process of entering the standby mode is executed at this time, a system reset will be performed instead of entering standby mode. By setting the nRST_STOP bit in User Option Bytes to 0, the stop mode reset is enabled. After the process of entering the stop mode is executed, a system reset will be executed instead of entering stop mode.

Figure 3-1 System reset structure

### 3.2.3 Backup Domain Reset

When the backup domain reset occurs, only the backup domain register will be reset, including the backup register, RCC_BDCTLR register (RTC enable and LSE oscillator). A backup domain reset is generated when one of the following events occurs:
- On the premise that both VDD and VBAT are powered off, it is caused by power-on of VDD or VBAT
- Set the BDRST bit in the RCC_BDCTLR register to 1

## 3.3 Clock

3.3.1 System Clock Structure

Figure 3-2 CH32V305/307/317 and CH32F205/207 clock tree structure

to RTC RTCCLK

ETH-PHY ⁶⁰MHz

XTI to MCO
3-25MHz
HSE OSC

to Flash prog IF

to HB bus/core/memory/DMA

FCLK core free running clock

to Core System timer /8

peripheral clock enable

MII/RMII interface

ADC prescaler

Note: This clock tree structure is applied for CH32F20x_D8C, CH32V30x_D8C and CH32V31x_D8C.

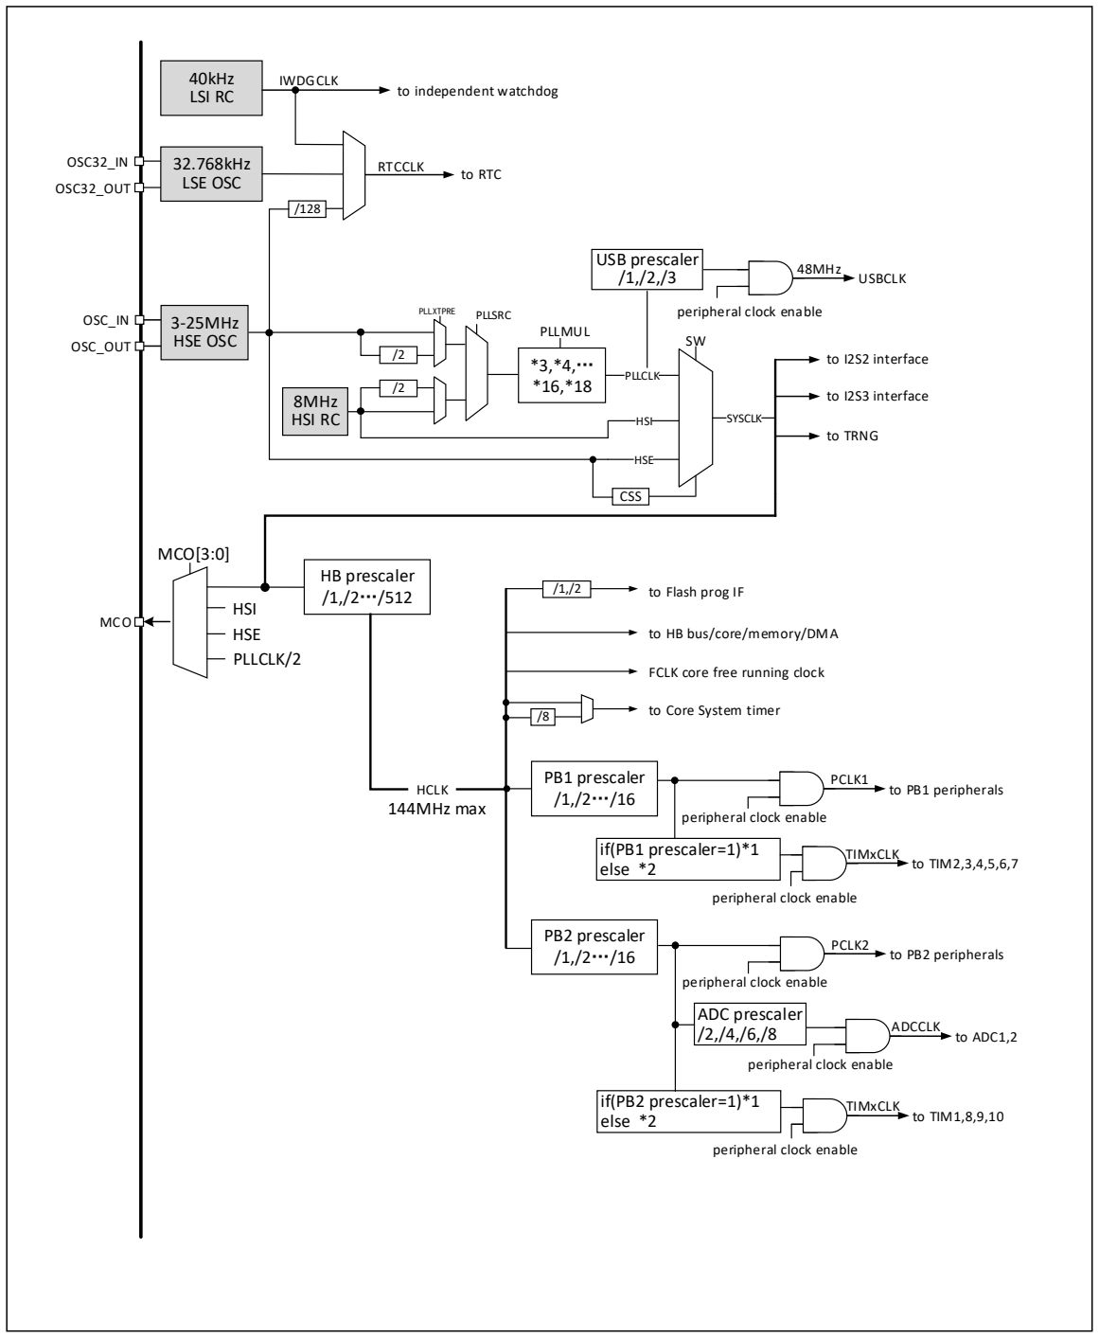
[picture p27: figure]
OSC32_IN; OSC32_OUT; 40kHz LSI RC; IWDGCLK; to independent watchdog; 32.768kHz LSE OSC; to RTC RTCCLK; OSC_IN; OSC_OUT; 3-25MHz HSE OSC; 8MHz HSI RC; PLLMUL; PLLSRC; to I2S3 interface; to I2S2 interface; to TRNG; MCO; MCO[3:0]; HSE; HSI; PLLCLK/2; HB prescaler /1,/2…/512; PB1 prescaler /1,/2…/16; PB2 prescaler /1,/2…/16; to HB bus/core/memory/DMA; FCLK core free running clock; to Core System timer /8; PCLK1 to PB1 peripherals; peripheral clock enable if(PB1 prescaler=1)*1 else *2; peripheral clock enable; TIMxCLK; to TIM2,3,4,5,6,7; PCLK2 to PB2 peripherals; if(PB2 prescaler=1)*1 else *2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

V2.5 | 28

Figure 3-3 CH32F203/V203/V303 clock tree structure

Note: This clock tree structure is applied for CH32F20x_D6, CH32F20x_D8, CH32V20x_D6 and CH32V30x_D8. When using the USB function, the CPU frequency must be 48MHz, 96MHz or 144MHz. when using the USB high speed function, the clock source of USBHSPLL can only be HSE. when the system wakes up from the stop or standby mode, the system will automatically switch to HSI as the main frequency.

V2.5 | 29

Figure 3-4 CH32V203RB clock tree structure

Note: (1) CH32V203RB (CH32V20x_D8) products have an external crystal or clock (HSE) of 32M, and there is no need for a load capacitor to have been built in when using an external crystal.
(2) The blue dotted line in Figure 3-4 above applies only to CH32V203RB chips with the penultimate digit of the lot number greater than zero.

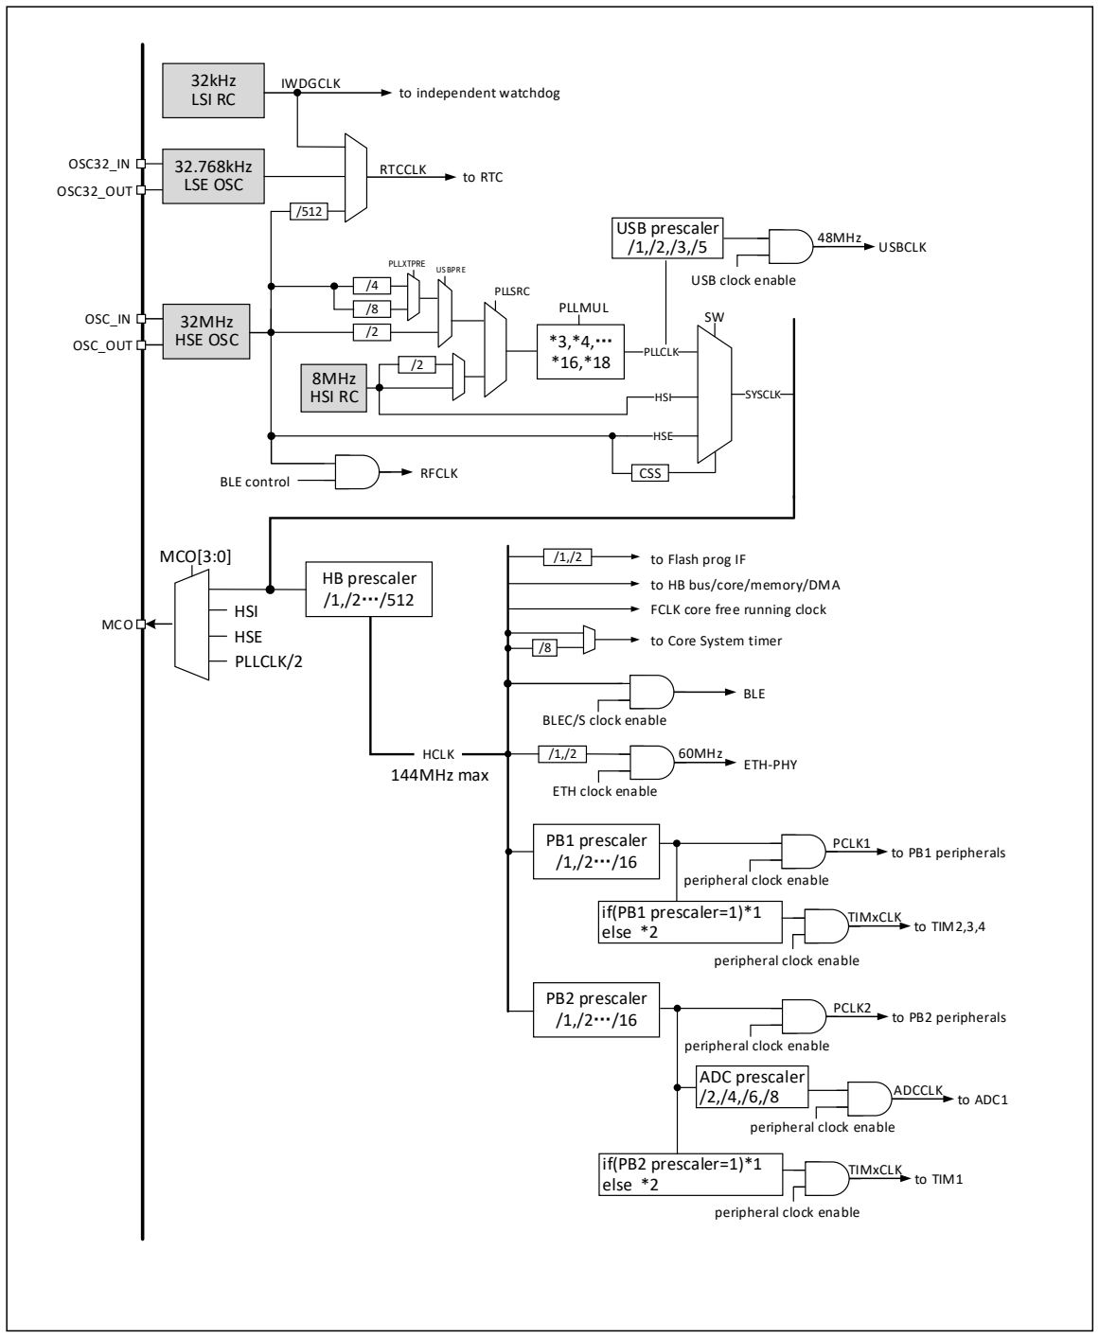
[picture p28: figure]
OSC32_IN; OSC32_OUT; 32kHz LSI RC; IWDGCLK; to independent watchdog; 32.768kHz LSE OSC; to RTC RTCCLK; OSC_IN; OSC_OUT; 32MHz HSE OSC; 8MHz HSI RC; PLLMUL; PLLSRC; MCO; MCO[3:0]; HSE; HSI; PLLCLK/2; HB prescaler /1,/2…/512; PB1 prescaler /1,/2…/16; PB2 prescaler /1,/2…/16; to HB bus/core/memory/DMA FCLK core free running clock; to Core System timer /8; PCLK1 to PB1 peripherals; peripheral clock enable if(PB1 prescaler=1)*1 else *2; peripheral clock enable; TIMxCLK; to TIM2,3,4; PCLK2 to PB2 peripherals; if(PB2 prescaler=1)*1 else *2; to TIM1; ADC prescaler; ADCCLK; to ADC1; SYSCLK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

V2.5 | 30

Figure 3-5 CH32FV208 clock tree structure

Note: This clock tree structure is applied for CH32F20x_D8W and CH32V20x_D8W. When USB and ETH are used simultaneously, set the USBPRE[1:0] bits to 11b. The external crystal or clock (HSE) is 32M. When the external crystal is enabled, no load capacitor is required as it is built in.

### 3.3.2 High-speed Clock (HSI/HSE)

HSI is a high-speed clock signal generated by an 8MHz RC oscillator in the system. The HSI RC oscillator can provide the system clock without depending on any external device. Its startup time is very short but the

V2.5 | 31

clock frequency accuracy is poor. HSI is enabled/disabled by setting the HSION bit in the RCC_CTLR register. The HSIRDY bit indicates whether the HSI RC oscillator is stable. By default, HSION and HSIRDY are set to 1 (Recommended not to disable). If the HSIRDYIE bit in the RCC_INTR register is set, a corresponding interrupt is generated.

- Factory calibration: The difference in manufacturing process may cause the RC oscillation frequency of each chip to be different, so HSI calibration is performed for each chip before the chip is delivered out of the factory. After the system is reset, the factory calibration value is loaded into the HSICAL[7:0] bits in the RCC_CTLR register.
- User adjustment: Based on different voltages or ambient temperatures, the application program can adjust the HSI frequency through the HSITRIM[4:0] bits in the RCC_CTLR register.

Note: If the HSE crystal oscillator fails, HSI clock is used as a backup clock source (clock security system).

HSE is a High-Speed External clock signal, including external crystal/ceramic resonator generation or external high-speed clock input.

- External crystal/ceramic resonator (HSE crystal): An external 3 to 25MHz oscillator provides a more accurate clock source for the system. For details, please refer to the electrical characteristics of this manual. The HSE crystal can be enabled/disabled by setting the HSEON bit in the RCC_CTLR register. The HSERDY bit indicates whether the HSE crystal oscillation is stable. The clock is not released until the HSERDY bit is set to 1 by hardware. If the HSERDYIE bit in the RCC_INTR register is set, a corresponding interrupt can be generated.

Figure 3-6 HSE crystal circuit

OSC_IN

OSC_OUT

CL1

CL2

3～25MHz Lo ad
Capacitance

Note: The load capacitor should be placed as close as possible to the oscillator pins, and the loading capacitance values must be adjusted according to the selected oscillator.

- External high-speed clock source (HSE bypass): In this mode, an external clock source is directly provided to the OSC_IN pin, and the OSC_OUT pin is suspended. It can have a frequency of up to 25MHz. The application program needs to set the HSEBYP bit when the HSEON bit is 0, to enable HSE bypass, and then set the HSEON bit.

Figure 3-7 High-speed clock source circuit

OSC_IN

fHSE_ext

External clock
source

(Suspended)

V2.5 | 32

### 3.3.3 Low-speed Clock (LSI/LSE)

LSI is a low-speed clock signal generated by the system's internal RC oscillator. It can keep running in stop and standby modes, and provide a clock reference for the RTC clock, independent watchdog, and wake-up unit. For further information, please refer to the electrical characteristics of this manual. LSI can be enabled/disabled by setting the LSION bit in the RCC_RSTSCKR register, and then it checks whether the LSI RC oscillation is stable by querying the LSIRDY bit. The clock is not released until the LSIRDY bit is set to 1 by hardware. If the LSIRDYIE bit in the RCC_INTR register is set, a corresponding interrupt can be generated.
LSE is an external low-speed clock signal, including external crystal/ceramic resonator generation or external low-speed clock input. It provides a low-power but highly accurate clock source for RTC clock or other timing functions.
- External crystal/ceramic resonator (LSE crystal): External 32.768kHz low-speed oscillator. LSE can be enabled/disabled by setting the LSEON bit in the RCC_BDCTLR register. The LSERDY bit indicates whether the LSE crystal oscillation is stable. The clock is not released until the LSERDY bit is set to 1 by hardware. If the LSERDYIE bit in the RCC_INTR register is set, a corresponding interrupt can be generated.

Figure 3-8 LSE crystal circuit

OSC32_IN

OSC32_OUT

CL1

CL2

32.768kHZ Lo ad
Capacitance
- External low-speed clock source (LSE bypass): In this mode, an external clock source is directly provided to the OSC32_IN pin, and the OSC32_OUT pin is suspended. The application program needs to set the LSEBYP bit when the LSEON bit is 0, to enable the LSE bypass, and then set the LSEON bit.

Figure 3-9 Low-speed clock source circuit

OSC32_IN

fLSE_ext

External clock
source

(Suspended) OSC32_OUT

### 3.3.4 PLL Clock

By configuring the RCC_CFGR0 register and the EXTEND_CTR register, 3 clock sources and multiplication factors can be selected for the internal PLL clock. These settings must be completed before each PLL is enabled. Once the PLL is enabled, these parameters cannot be changed. PLL can be enabled/disabled by setting the PLLON bit in the RCC_CTLR register. The PLLRDY bit indicates whether the PLL clock is stable. The clock is not released until the PLLRDY bit is set to 1 by hardware. PLL2 can be enabled/disabled by setting the PLLON2 bit in the RCC_CTLR register. The PLLRDY2 bit indicates whether the PLL2 clock is stable. The clock is not released until the PLLRDY2 bit is set to 1 by hardware.

V2.5 | 33

PLL3 can be enabled/disabled by setting the PLLON3 bit in the RCC_CTLR register. The PLLRDY3 bit indicates whether the PLL3 clock is stable. The clock is not released until the PLLRDY3 bit is set to 1 by hardware. If the PLLRDYIE bit, the PLL2RDYIE bit and the PLL3RDYIE bit in the RCC_INTR register are set, a corresponding interrupt can be generated.

PLL clock sources:
- HSI clock
- HSI clock divided by 2
- HSE clock or PLL2 clock through a configurable divider
PLL2 and PLL3 are clocked by HSE through a configurable divider (PREDIV2)

### 3.3.5 Bus/Peripheral Clock

### 3.3.5.1 System Clock (SYSCLK)

Configure the system clock source by configuring the SW[1:0] bits in the RCC_CFGR0 register. The SWS[1:0] bits indicate the current system clock source status.

- HSI as the system clock
- HSE as the system clock
- PLL clock as the system clock

After the controller reset, HSI clock is selected as the system clock source by default. A switch from one clock source to another occurs only if the target clock source is ready.

### 3.3.5.2 HB/PB1/PB2 Bus Peripheral Clock (HCLK/PCLK1/PCLK2)

By configuring the HPRE[3:0], PPRE1[2:0], and PPRE2[2:0] bits in the RCC_CFGR0 register, the clocks of the HB, PB1, and PB2 buses can be configured respectively. These bus clocks determine the access clock reference of the peripheral interfaces mounted below them. The application program can adjust different values to reduce the power consumption of some peripherals.
Different peripheral modules can be reset by bits in the RCC_AHBRSTR, RCC_APB1PRSTR, and RCC_APB2PRSTR registers to restore them to the initial state.
By setting bits in the RCC_AHBPCENR, RCC_APB1PCENR and RCC_APB2PCENR registers, the communication clock interface of different peripheral modules can be enabled or disabled separately. To use a peripheral, firstly enable the corresponding clock bit to access its register.

### 3.3.5.3 RTC Clock (RTCCLK)

By setting the RTCSEL[1:0] bits in the RCC_BDCTLR register, the RTCCLK clock source can either be HSE, LSE or LSI clocks. Before modifying this bit, ensure that the DBP bit in the power control register (PWR_CTLR) is set to 1, and this bit can be reset only when the backup domain is reset.
- LSE as the RTC clock: As LSE is at the backup domain and is powered by the VBAT supply, as long as VBAT maintains supplying power, RTC will continuously work even though VDD power supply is switched off.
- LSI as the RTC clock: If the VDD power supply is switched off, the Auto-wakeup unit (AWU)clock cannot be guaranteed.
- The HSE is divided and used as the RTC clock: if the VDD supply is cut off or the internal voltage regulator is turned off (the supply to the 1.8V domain is cut off), the RTC status is indeterminate. Refer to the description of the RCC_BDCTLR register RTCSEL[1:0] bits for the dividing factor of the HSE for the corresponding chip model.

V2.5 | 34

### 3.3.5.4 Independent Watchdog Clock

If the independent watchdog (IWDG) is started by either hardware option or software access, the LSI oscillator is forced ON and cannot be switched off. After the LSI oscillator temporization, the clock is provided to IWDG.

### 3.3.5.5 Microcontroller Clock Output (MCO)

The microcontroller clock output (MCO) capability allows the clock to output onto the MCO pin. Configure the alternate push-pull output mode in the corresponding GPIO port register. By setting the MCO[3:0] bits in the RCC_CFGR0 register, the following 8 clock signals can be selected as the MCO clock output:
- System clock (SYSCLK)
- HSI clock
- HSE clock
- PLL clock divided by 2
- PLL2 clock
- PLL3 clock
- PLL3 clock divided by 2
- XT1 external 3-25MHz oscillator (For Ethernet)

### 3.3.5.6 USB clock

USBD 48MHz clock source is a PLL clock through a configurable divider, and the PLL supports 3 types of clock configurations, including 48MHz, 96MHz and 144MHz. By configuring the USBPRE[1:0] bits in the RCC_CFGR0 register, the 48MHz clock is output to USBD.
USBFS/OTG_FS 48MHz clock source is a PLL clock or USBHSPLL clock through a configurable divider, and it can be selected by configuring the USBFSSRC bit in the RCC_CFGR2 register. If a PLL clock through a configurable divider is selected as the clock source, refer to USBD for configuration steps. If USBHSPLL clock is selected as the clock source, USBHSPLL reference clock frequency can be selected by configuring the USBHS_CKREFSEL[1:0] bits in the RCC_CFGR2 register (Reference clock frequency must be consistent with USBHSPLL input clock).
USBHD clock source is originated from USBHSPLL clock. USBHSPLL reference clock frequency can be selected by configuring the USBHS_CKREFSEL[1:0] bits in the RCC_CFGR2 register (Reference clock frequency must be consistent with USBHSPLL input clock). By setting the USBHS_PLLALIVE bit in the RCC_CFGR2 register, USB PHY internal PLL can be enabled.

### 3.3.5.7 ETH clock

For details, please refer to Section 27.1.4.5.

### 3.3.5.8 I2S and RNG clock

I2S and RNG clock source are originated from PLL3VCO or system clock (SYSCLK). By configuring the I2S2SRC/I2S3SRC/RNG_SRC bit in the RCC_CFGR2 register, I2S2/I2S3/RNG clock source can be selected respectively.

### 3.3.6 Clock Security System

The clock security system is an operation protection mechanism of the controller. It can switch to HSI clock when a failure is detected on the HSE clock, generate interrupt notification and allow the application

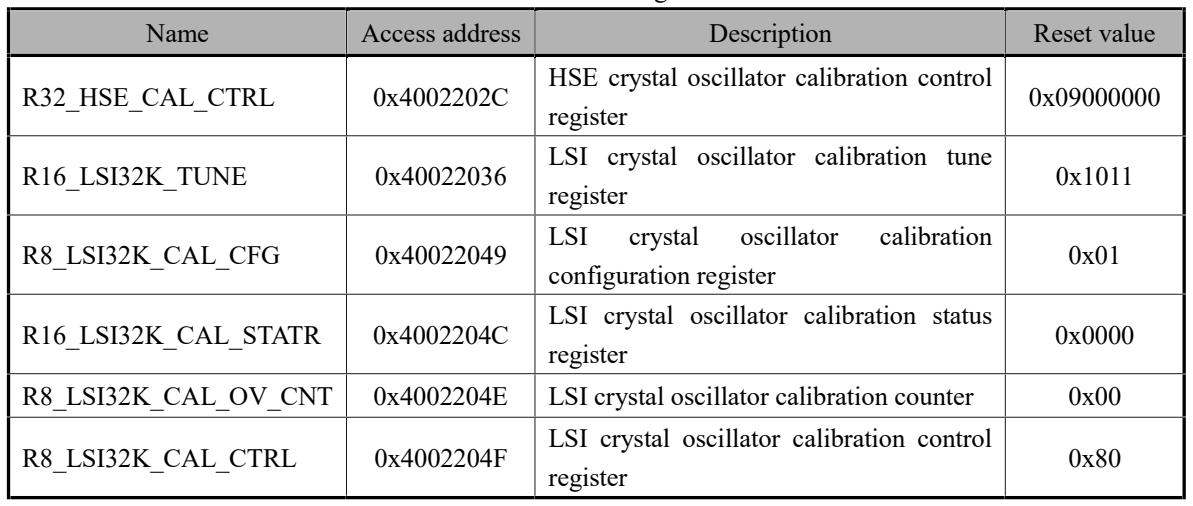
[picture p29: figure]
Name; Access address; Description; Reset value; R32_HSE_CAL_CTRL; HSE crystal oscillator calibration control register; R16_LSI32K_TUNE; LSI crystal oscillator calibration tune register; R8_LSI32K_CAL_CFG; LSI; crystal; oscillator; calibration; configuration register; R16_LSI32K_CAL_STATR; LSI crystal oscillator calibration status register; R8_LSI32K_CAL_OV_CNT; LSI crystal oscillator calibration counter; R8_LSI32K_CAL_CTRL; LSI crystal oscillator calibration control register

V2.5 | 35

software to perform rescue operations.
By setting the CSSON bit in the RCC_CTLR register to 1, the clock security system can be activated. In this case, the clock detector is enabled after the HSE oscillator startup delay (HSERDY=1), and disabled after the HSE oscillator is stopped. Once a failure is detected on the HSE clock during system operation, the HSE oscillator will be disabled, and the clock failure event will be sent to the break input of the advanced-control timers (TIM1 and TIM8). Then a clock security interrupt is generated, the CSSF bit is set to 1, and the application program enters the non-maskable interrupt (NMI). The CSSF bit can be cleared by setting the CSSC bit, and the NMI interrupt pending bit can be cancelled.
If the current HSE is selected as the system clock, or the current HSE is selected as the PLL input clock and the PLL is selected as the system clock, the clock security system will automatically switch the system clock to the HSI oscillator when the failure occurs, and disable the HSE oscillator and PLL.

## 3.4 Register Description

Table 3-1 RCC registers
Name | Access address | Description | Reset value
R32_RCC_CTLR | 0x40021000 | Clock control register | 0x0000xx83
R32_RCC_CFGR0 | 0x40021004 | Clock configuration register 0 | 0x00000000
R32_RCC_INTR | 0x40021008 | Clock interrupt register | 0x00000000
R32_RCC_APB2PRSTR | 0x4002100C | PB2 peripheral reset register | 0x00000000
R32_RCC_APB1PRSTR | 0x40021010 | PB1 peripheral reset register | 0x00000000
R32_RCC_AHBPCENR | 0x40021014 | HB peripheral clock enable register | 0x00000014
R32_RCC_APB2PCENR | 0x40021018 | PB2 peripheral clock enable register | 0x00000000
R32_RCC_APB1PCENR | 0x4002101C | PB1 peripheral clock enable register | 0x00000000
R32_RCC_BDCTLR | 0x40021020 | Backup domain control register | 0x00000000
R32_RCC_RSTSCKR | 0x40021024 | Control/status register | 0x0C000000
R32_RCC_AHBRSTR | 0x40021028 | HB peripheral reset register | 0x00000000
R32_RCC_CFGR2 | 0x4002102C | Clock configuration register 2 | 0x00000000

Table 3-2 OSC registers

Note: Applied for CH32V20x_D8W and CH32F20x_D8W.

V2.5 | 36

### 3.4.1 Clock Control Register (RCC_CTLR)

Offset address: 0x00
31 | 30 | 29 | 28 | 27 | 26 | 25 | 24 | 23 | 22 | 21 | 20 | 19 | 18 | 17 | 16
Reserved PLL3
| | RDY | PLL3 ON | PLL2 RDY | PLL2 ON | PLL RDY | PLL
ON | Reserved | CSSO
| | | | | | | | | | | | N | HSE BYP | HSE RDY | HSE ON
15 | 14 | 13 | 12 | 11 | 10 | 9 | 8 | 7 | 6 | 5 | 4 | 3 | 2 | 1 | 0
HSICAL[7:0] | HSITRIM[4:0] | Reser
| | | | | | | | | | | | | ved | HSI RDY | HSIO N
Bit | Name | Access | Description | Reset value
[31:30] Reserved | RO Reserved | 0
29 | PLL3RDY | RO

PLL3 clock ready lock flag bit (Set by hardware):
0: PLL3 unlocked;
1: PLL3 locked.
Note: Applied for CH32F20x_D8C, CH32V30x_D8C, CH32V31x_D8C.

0

28 | PLL3ON | RW

PLL3 clock enable control bit:
0: PLL3 disabled;
1: PLL3 enabled.
Note: This bit is cleared by hardware when entering stop
or | standby | low-power | mode. | Applied | for
CH32F20x_D8C, CH32V30x_D8C, CH32V31x_D8C.

0

27 | PLL2RDY | RO

PLL2 clock ready lock flag bit (Set by hardware):
0: PLL unlocked;
1: PLL locked.
Note: Applied for CH32F20x_D8C, CH32V30x_D8C, CH32V31x_D8C.

0

26 | PLL2ON | RW

PLL2 clock enable control bit:
0: PLL disabled;
1: PLL enabled.
Note: This bit is cleared by hardware when entering stop
or | standby | low-power | mode. | Applied | for
CH32F20x_D8C, CH32V30x_D8C, CH32V31x_D8C.

0

25 | PLLRDY | RO

PLL clock ready lock flag bit (Set by hardware):
0: PLL unlocked;
1: PLL locked.

0

24 | PLLON | RW

PLL clock enable control bit:
0: PLL disabled;
1: PLL enabled.
Note: This bit is cleared by hardware when entering stop or standby low-power mode.

0

[23:20] Reserved | RO Reserved | 0
19 | CSSON | RW

Clock security system enable control bit: 0: Disable clock security system;

0

V2.5 | 37

1: Enable clock security system. When the HSE is ready (HSERDY is set to 1), the HSE clock detector is enabled by hardware. When a HSE clock failure is detected, the CSSF flag and NMI interrupt is enabled. When the HSE is not ready, the HSE clock detector is disabled by hardware.
Note: This feature is not applicable to CH32V20x_D6 chips where the fifth digit from the end of the lot number is 0.
18 | HSEBYP | RW

HSE clock bypass control bit:
0: Not bypass HSE oscillator;
1: Bypass HSE oscillator (Using external clock source). Note: This bit can be written only when HSEON is 0.

0

17 | HSERDY | RO

HSE clock ready flag bit (Set by hardware):
0: HSE oscillator not ready;
1: HSE oscillator ready.
Note: After the HSEON bit is cleared, it takes 6 cycles of the HSE oscillator clock to clear this bit.

0

16 | HSEON | RW

HSE clock enable control bit:
0: Disable HSE oscillator;
1: Enable HSE oscillator.
Note: After entering the stop or standby low-power mode, this bit is cleared by hardware.

0

[15:8] HSICAL[7:0] | RO HSI clock calibration, automatically initialized at startup. | xxh
[7:3] | HSITRIM[4:0] | RW

HSI clock trimming:
The user can input a trimming value that is added to the HSICAL[7:0] bits, and adjust the frequency of the internal HSI RC oscillator according to variations in voltage and temperature.
The default value is 16, which allows you to adjust the HSI to 8MHz ±0.25%; the change in HSICAL is adjusted about 20kHz per step.

10000

2 | Reserved | RO Reserved | 0
1 | HSIRDY | RO

HSI clock (8MHz) ready flag bit (Set by hardware):
0: HIS oscillator (8MHz) not ready;
1: HIS oscillator (8MHz) ready.
Note: After the HSION bit is cleared, it takes 6 cycles of the HSI oscillator clock to clear this bit.

1

0 | HSION | RW

HSI clock (8MHz) enable control bit:
0: Disable HSI oscillator;
1: Enable HSI oscillator.
Note: When the system returns from standby and stop modes or when the external oscillator HSE selected as the system clock fails, this bit will be set by hardware to start the internal 8MHz RC oscillator.

1

ADC clock duty cycle adjustment:
0: ADC clock duty cycle is 50%;
1: ADC clock at low level for longer.
ADC clock duty cycle selection:
1: ADC clock duty cycle is 75%.
Note: This bit only applies to CH32F20x_D8,
CH32F20x_D8C, CH32V30x_D8, CH32V30x_D8C, and
CH32V31x_D8C lot numbers that do not have a zero in
the penultimate sixth digit.

Ethernet clock source prescaler control:
0: Not divided;
1: Divided by 2.
Note: Applied for CH32V20x_D8W, CH32V20x_D8 and
Microcontroller clock output (MCO) control:
00xx: No clock;
0100: System clock (SYSCLK);
0101: Internal 8MHz RC oscillator clock (HSI);
0110: External oscillator clock (HSE);
0111: PLL clock divided by 2;
1000: PLL2 clock;
1001: PLL3 clock divided by 2;
1010: XT1 external oscillator clock;
1011: PLL3 clock.
Note: This clock output may have some truncated cycles
at startup or during MCO clock source switching. The
values from 1000 to 1011 are applied for
USBFS/USBOTG clock prescaler configuration:
00: Not divided (When PLLCLK=48MHz);
01: Divided by 2 (When PLLCLK=96MHz);

V2.5 | 39

10: Divided by 3 (When PLLCLK=144MHz);
11: Divided by 5, and PLL source is HSE divided by 2 (PLLCLK=240MHz, only applied for CH32V20x_D8W/ CH32F20x_D8W and CH32V20x_D8 lot number where the penultimate digit is greater than 0).
Note: The 11b option is supported for CH32V20x_D8W,
CH32F20x_D8W, | and CH32V20x_D8 with | the
penultimate digit of the lot number greater than 0. The option is retained for the remaining models.
The USBD/USBHS module clock requires 48 MHz.This bit must be configured before the USBD and USBHS clocks are enabled (In RCC_AHBPCENR and RCC_APB1PCENR).

[21:18] PLLMUL[3:0] RW

PLL multiplication factor (These bits can be written only when PLL is disabled):
For CH32F20x_D6, CH32F20x_D8, CH32F20x_D8W, CH32V20x_D6, CH32V20x_D8, CH32V20x_D8W, CH32V30x_D8:
0000: PLL input clock x 2; 0001: PLL input clock x 3; 0010: PLL input clock x 4; 0011: PLL input clock x 5; 0100: PLL input clock x 6; 0101: PLL input clock x 7; 0110: PLL input clock x 8; 0111: PLL input clock x 9; 1000: PLL input clock x 10; 1001: PLL input clock x 11; 1010: PLL input clock x 12; 1011: PLL input clock x 13; 1100: PLL input clock x 14; 1101: PLL input clock x 15; 1110: PLL input clock x 16; 1111: PLL input clock x 18;
For | CH32F20x_D8C, | CH32V30x_D8C,
CH32V31x_D8C:
0000: PLL input clock x 18; 0001: PLL input clock x 3; 0010: PLL input clock x 4; 0011: PLL input clock x 5; 0100: PLL input clock x 6; 0101: PLL input clock x 7; 0110: PLL input clock x 8; 0111: PLL input clock x 9; 1000: PLL input clock x 10; 1001: PLL input clock x 11; 1010: PLL input clock x 12; 1011: PLL input clock x 13; 1100: PLL input clock x 14; 1101: PLL input clock x 6.5; 1110: PLL input clock x 15; 1111: PLL input clock x 16.

0

17 | PLLXTPRE | RW

HSE divider for PLL entry (It can be written only when PLL is disabled)
For the CH32F20x_D8C, CH32V30x_D8C series, this bit is reserved.
0: HSE clock not divided;
1: HSE clock divided by 2.
For | CH32F20x_D8C, | CH32V30x_D8C,
CH32V31x_D8C:
The lowest bit of the PREDIV1 dividing factor is selected by software by setting a 1 or clearing a 0. The

0

V2.5 | 40

PLLXTPRE bit is the same bit as bit [0] of the RCC_CFGR2 register, so modifying bit [0] of the RCC_CFGR2 register changes this bit at the same time. If bits [3:1] of the RCC_CFGR2 register are 000b, this bit controls PREDIV1 to divide the input clock by 2 (PLLXPRE=1) or not divide the input clock (PLLXPRE=0).
For | CH32F20x_D8W, | CH32V20x_D8W,
CH32V20x_D8.
0: HSE clock divided by 4;
1: HSE clock divided by 8.
16 | PLLSRC | RW

PLL entry clock source (It can be written only when the PLL is disabled):
For CH32F20x_D6, CH32F20x_D8, CH32V20x_D6, CH32V30x_D8:
0: HSI clock not divided or divided by 2;
1: HSE clock not divided or divided by 2.
For | CH32F20x_D8C, | CH32V30x_D8C,
CH32V31x_D8C:
0: HSI not divided or divided by 2 fed to PLL;
1: PREDIV1 output fed to PLL.
For | CH32F20x_D8W, | CH32V20x_D8W,
CH32V20x_D8:
0: HSI no divided or divided by 2 feed to PLL;
1: HSE divided by 2 or divided by 4 or divided by 8 fed to PLL.

0

[15:14] ADCPRE[1:0] RW

ADC clock source prescaler control: 00: PCLK2 divided by 2;
01: PCLK2 divided by 4;
10: PCLK2 divided by 6;
11: PCLK2 divided by 8;
Note: ADC clock shall not exceed 14MHz at most.

0

[13:11] PPRE2[2:0] | RW

PB2 clock source prescaler control:
0xx: HCLK not divided;
100: HCLK divided by 2;
101: HCLK divided by 4;
110: HCLK divided by 8;
111: HCLK divided by 16.

0

[10:8] PPRE1[2:0] | RW

PB1 clock source prescaler control: 0xx: HCLK not divided;
100: HCLK divided by 2;
101: HCLK divided by 4;
110: HCLK divided by 8;
111: HCLK divided by 16.

0

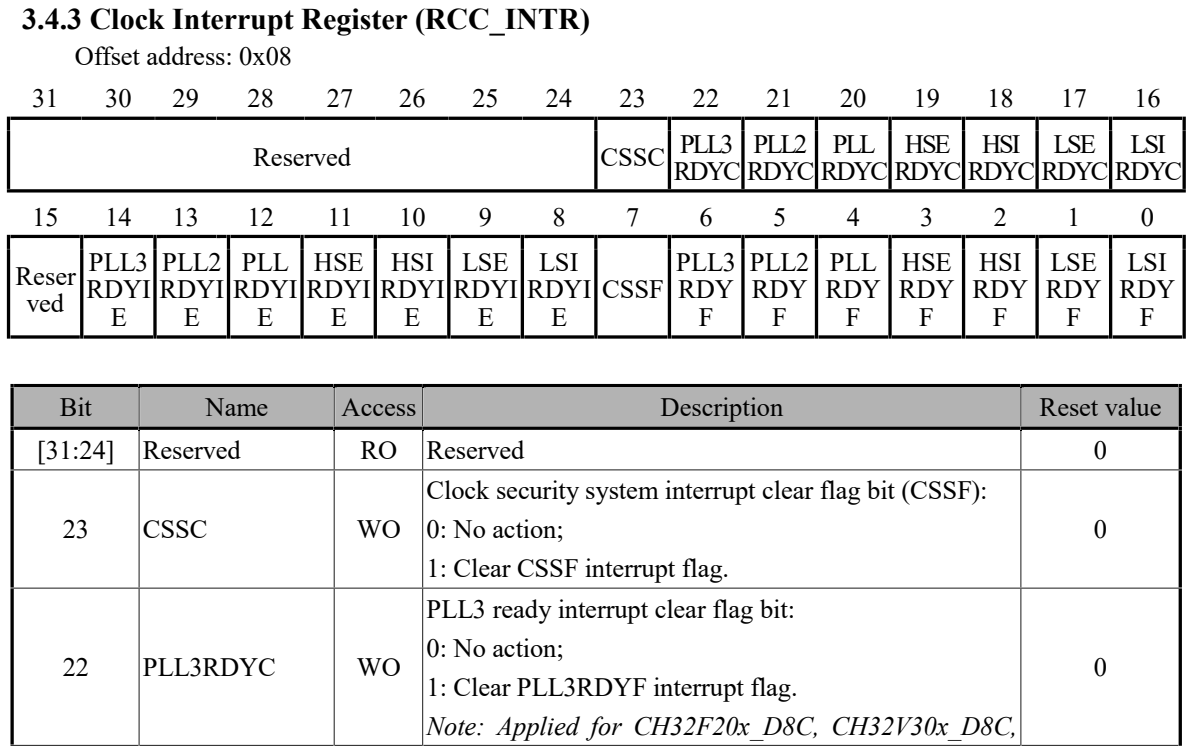
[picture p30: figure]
3.4.3 Clock Interrupt Register (RCC_INTR) Offset address: 0x08; Reserved; CSSC PLL3; RDYC; PLL2 RDYC; PLL RDYC; HSE RDYC; HSI RDYC; LSE RDYC; LSI RDYC; Reser ved; PLL3 RDYI E; PLL2 RDYI E; PLL RDYI E; HSE RDYI E; HSI RDYI E; LSE RDYI E; LSI RDYI E; CSSF; PLL3 RDY F; PLL2 RDY F; PLL RDY F; HSE RDY F; HSI RDY F; LSE RDY F; LSI RDY F; Bit; Name; Access; Description; Reset value; [31:24] Reserved; RO Reserved; CSSC; 0: No action; 1: Clear CSSF interrupt flag.; PLL3RDYC; PLL3 ready interrupt clear flag bit: 0: No action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

V2.5 | 41
[7:4] HPRE[3:0] | RW

HB clock source prescaler control: 0xxx: SYSCLK not divided;
1000: SYSCLK divided by 2; 1001: SYSCLK divided by 4; 1010: SYSCLK divided by 8; 1011: SYSCLK divided by 16; 1100: SYSCLK divided by 64; 1101: SYSCLK divided by 128; 1110: SYSCLK divided by 256; 1111: SYSCLK divided by 512.

0

[3:2] SWS[1:0] | RO

System clock (SYSCLK) switch status (set by hardware): 00: HSI oscillator used as system clock;
01: HSE oscillator used as system clock;
10: PLL oscillator used as system clock;
11: Not applicable.

0

[1:0] SW[1:0] | RW

System clock source switch:
00: HSI oscillator used as system clock; 01: HSE oscillator used as system clock;
10: PLL oscillator used as system clock;
11: Not applicable.
Note: When the system returns from standby and stop modes or when the external oscillator HSE used as the system clock fails after the clock security system is enabled (CSSON=1), HSI is forced to be selected as the system clock by hardware.

0

Clock security system interrupt clear flag bit (CSSF):

HSE oscillator ready interrupt clear flag bit:

HSI oscillator ready interrupt clear flag bit:

LSE oscillator ready interrupt clear flag bit:

LSI oscillator ready interrupt clear flag bit:

Clock security system interrupt flag bit:
0: No clock security system interrupt caused by HSE

V2.5 | 43

1: Clock security interrupt caused by HSE clock failure. Set by hardware. Write 1 to CSSC bit by software to clear.

6 | PLL3RDYF | RO

PLL3 clock ready interrupt flag:
0: No clock ready interrupt caused by PLL3 clock;
1: Clock ready interrupt caused by PLL3 clock.
Set by hardware. Write 1 to PLL3RDYC by software to clear.
Note: Applied for CH32F20x_D8C, CH32V30x_D8C, CH32V31x_D8C.

0

5 | PLL2RDYF | RO

PLL2 clock ready interrupt flag:
0: No clock ready interrupt caused by PLL2 clock;
1: Clock ready interrupt caused by PLL2 clock.
Set by hardware. Write 1 to PLL2RDYC by software to clear.
Note: Applied for CH32F20x_D8C, CH32V30x_D8C, CH32V31x_D8C.

0

4 | PLLRDYF | RO

PLL clock ready interrupt flag:
1: Clock ready interrupt caused by PLL clock;
0: No clock ready interrupt caused by PLL clock.
Set by hardware. Write 1 to PLLRDYC by software to clear.

0

3 | HSERDYF | RO

HSE clock ready interrupt flag:
0: No clock ready interrupt caused by HSE clock;
1: Clock ready interrupt caused by HSE clock.
Set by hardware. Write 1 to HSERDYC bit by software to clear.

0

2 | HSIRDYF | RO

HSI clock ready interrupt flag:
0: No clock ready interrupt caused by HSI clock;
1: Clock ready interrupt caused by HSI clock.
Set by hardware. Write 1 to HSIRDYC bit by software to clear.

0

1 | LSERDYF | RO

LSE clock ready interrupt flag:
0: No clock ready interrupt caused by LSE clock;
1: Clock ready interrupt caused by LSE clock.
Set by hardware. Write 1 to LSERDYC bit by software to clear.

0

0 | LSIRDYF | RO

LSI clock ready interrupt flag:
0: No clock ready interrupt caused by LSI clock;
1: Clock ready interrupt caused by LSI clock.
Set by hardware. Write 1 to LSIRDYC bit by software to clear.

0

### 3.4.4 PB2 Peripheral Reset Register (RCC_APB2PRSTR)

Offset address: 0x0C

IO port PE reset:
IO port PD reset:
IO port PC reset:
IO port PB reset:
IO port PA reset:

Alternate function IO reset:

3.4.5 PB1 Peripheral Reset Register (RCC_APB1PRSTR)
Offset address: 0x10

DAC module reset:
Power interface module reset:
Backup interface reset:
CAN2 module reset:
CAN1 module reset:

USBD module reset:
I2C2 interface reset:
I2C1 interface reset:
USART5 interface reset:
USART4 interface reset:
USART3 interface reset:
USART2 interface reset:

3.4.6 HB Peripheral Clock Enable Register (RCC_AHBPCENR)
Offset address: 0x14

BLES clock enable:
0: BLES clock disabled;
1: BLES clock enabled.
Note: Applied for CH32V20x_D8W and CH32F20x_D8W.
BLEC clock enable:
0: BLEC clock disabled;
1: BLEC clock enabled.
Ethernet MAC receive clock enable:
0: Ethernet MAC receive clock disabled;
1: Ethernet MAC receive clock enabled.

Note: Applied for CH32V30x_D8C, CH32V31x_D8C,
CH32F20x_D8C with 100M/Gigabit external PHY.
Ethernet MAC transmit clock enable:
0: Ethernet MAC transmit clock disabled;
1: Ethernet MAC transmit clock enabled.
Ethernet MAC clock enable:
0: Ethernet MAC clock disabled;
1: Ethernet MAC clock enabled.
DVP module clock enable bit:
0: DVP clock disabled;
1: DVP clock enabled.
USBOTG_FS module clock enable bit:
0: USBOTG_FS clock disabled;
1: USBOTG_FS clock enabled.
USBHS module clock enable bit:
0: USBHS clock disabled;
1: USBHS clock enabled.
SDIO module clock enable bit:
0: SDIO clock disabled;
1: SDIO clock enabled.
RNG module clock enable bit:
0: RNG clock disabled;
1: RNG clock enabled.
FSMCEN module clock enable bit:
0: FSMCEN clock disabled;
1: FSMCEN clock enabled.

CRC module clock enable bit:
0: CRC clock disabled;
1: CRC clock enabled.

SRAM interface clock enable bit:
0: In sleep mode, SRAM interface clock disabled;
1: In sleep mode, SRAM interface clock enabled;
DMA2 module clock enable bit:
0: DMA2 clock disabled;
1: DMA2 clock enabled.
DMA1 module clock enable bit:
0: DMA1 clock disabled;
1: DMA1 clock enabled.

3.4.7 PB2 Peripheral Clock Enable Register (RCC_APB2PCENR)
Offset address: 0x18

TIM10 interface clock enable bit:
0: TIM10 clock disabled; 1: TIM10 clock enabled.
TIM9 interface clock enable bit:
0: TIM9 clock disabled; 1: TIM9 clock enabled.

USART1 interface clock enable bit:
0: USART1 clock disabled; 1: USART1 clock enabled.
TIM8 module clock enable bit:
0: TIM8 clock disabled; 1: TIM8 clock enabled.
SPI1 interface clock enable bit:
0: SPI1 clock disabled; 1: SPI1 clock enabled.
TIM1 module clock enable bit:
0: TIM1 clock disabled; 1: TIM1 clock enabled.
ADC2 module clock enable bit:
0: ADC2 clock disabled; 1: ADC2 clock enabled.
ADC1 module clock enable bit:
0: ADC1 clock disabled; 1: ADC1 clock enabled.

IO port PE clock enable bit:
0: PE clock disabled; 1: PE clock enabled.
IO port PD clock enable bit:
0: PD clock disabled; 1: PD clock enabled.
IO port PC clock enable bit:
0: PC clock disabled; 1: PC clock enabled.
IO port PB clock enable bit:
0: PB clock disabled; 1: PB clock enabled.
IO port PA clock enable bit:
0: PA clock disabled; 1: PA clock enabled.

Alternate function IO clock enable bit:
0: Alternate function IO clock disabled;
1: Alternate function IO clock enabled;

3.4.8 PB1 Peripheral Clock Enable Register (RCC_APB1PCENR)
Offset address: 0x1C

DAC module clock enable bit:
0: DAC clock disabled; 1: DAC clock enabled.
Power interface clock enable bit:
0: Power interface clock disabled;
1: Power interface clock enabled.
Backup interface clock enable bit:
1: Backup interface clock enabled;
0: Backup interface clock disabled.
CAN2 module clock enable bit:
0: CAN2 clock disabled; 1: CAN2 clock enabled.
CAN1 module clock enable bit:
0: CAN1 clock disabled; 1: CAN1 clock enabled.

USBD module clock enable bit:
0: USBD clock disabled; 1: USBD clock enabled.
I2C2 interface clock enable bit:
0: I2C2 clock disabled; 1: I2C2 clock enabled.
I2C1 interface clock enable bit:
0: I2C1 clock disabled; 1: I2C1 clock enabled.
USART5 interface clock enable bit:
0: USART5 clock disabled; 1: USART5 clock enabled.
USART4 interface clock enable bit:
0: USART4 clock disabled; 1: USART4 clock enabled.
USART3 interface clock enable bit:
0: USART3 clock disabled; 1: USART3 clock enabled.
USART2 interface clock enable bit:
0: USART2 clock disabled; 1: USART2 clock enabled.

SPI3interface clock enable bit:
0: SPI3 clock disabled; 1: SPI3 clock enabled.
SPI2interface clock enable bit:
0: SPI2 clock disabled; 1: SPI2 clock enabled

Window watchdog clock enable bit:
0: Window watchdog clock disabled;
1: Window watchdog clock enabled;

USART8 enable bit:
0: USART8 clock disabled;
1: USART8 clock enabled.
USART7 enable bit:
0: USART7 clock disabled; 1: USART7 clock enabled.
USART6 enable bit:
0: USART6 clock disabled; 1: USART6 clock enabled.
Timer7 module clock enable bit:
0: Timer7 clock disabled; 1: Timer7 clock enabled.
Timer6 module clock enable bit:
0: Timer6 clock disabled; 1: Timer6 clock enabled.
Timer5 module clock enable bit:
0: Timer5 clock disabled; 1: Timer5 clock enabled.
Timer4 module clock enable bit:
0: Timer4 clock disabled; 1: Timer4 clock enabled.
Timer3 module clock enable bit:
0: Timer3 clock disabled; 1: Timer3 clock enabled.
Timer2 module clock enable bit:
0: Timer2 clock disabled; 1: Timer2 clock enabled.

3.4.9 Backup Domain Control Register (RCC_BDCTLR)
Offset address: 0x20

Backup domain software reset control:
0: Reset not activated;
1: Reset the entire backup domain.
RTC clock enable control:
0: RTC clock disabled;
1: RTC clock enabled.
Note: The RTC clock can be enabled only when
RTCSEL!=0. Otherwise, it is forced to 0 by hardware.

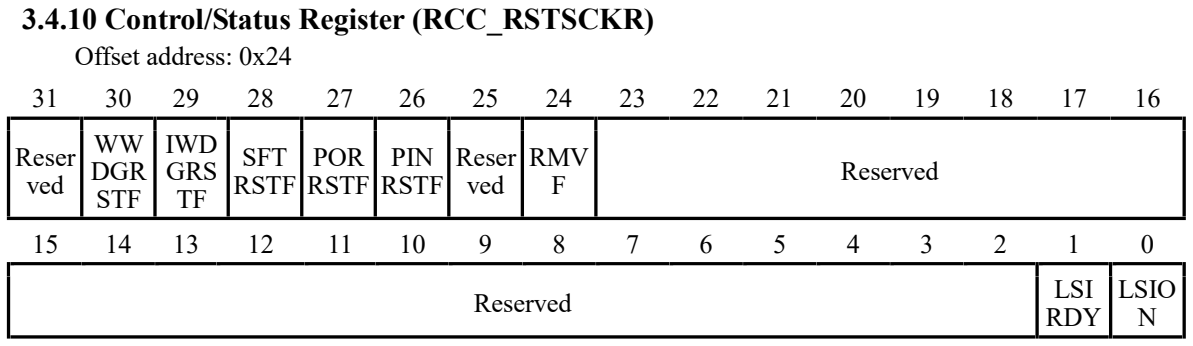
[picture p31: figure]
3.4.10 Control/Status Register (RCC_RSTSCKR) Offset address: 0x24; Reser ved; WW DGR STF; IWD GRS TF; SFT RSTF; POR RSTF; PIN RSTF; RMV; Reserved; LSI; RDY; LSIO N

V2.5 | 51
[9:8] | RTCSEL[1:0] | RW

RTC clock source selection: 00: No clock;
01: LSE oscillator clock;
10: LSI oscillator clock;
11: The HSE oscillator is divided and used as the RTC clock. Among them, CH32F20x_D6, CH32V20x_D6 series chips with the penultimate 5th digit of the lot number less than 1 are 512-division frequency, and vice versa are 128-division frequency; CH32F20x_D8W, CH32V20x_D8, CH32V20x_D8W series chips are
512-division | frequency; | CH32F20x_D8,
CH32F20x_D8C, CH32V30x_D8, CH32V30x_D8C, CH32V31x_D8C series chips are all 128 divisions. Note: Once the RTC clock source has been selected (RTCEN=1), it cannot be changed until the next backup domain is reset. The default can be restored by setting the BDRST bit.

0

[7:3] | Reserved | RO Reserved. | 0
2 | LSEBYP | RW

External low-speed (LSE) oscillator bypass control bit: 0: LSE oscillator not bypassed;
1: LSE oscillator bypassed (External clock source is used).
Note: This bit can be written only when LSEON is 0.

0

1 | LSERDY | RO

External low-speed oscillator ready flag bit (Set by hardware):
0: LSE oscillator not ready;
1: LSE oscillator ready.
Note: After the LSEON bit is cleared, it takes 6 cycles of LSE clock to clear this bit.

0

0 | LSEON | RW

External low-speed crystal oscillator enable control bit: 0: LSE oscillator disabled;
1: LSE oscillator enabled.

0

Note: The LSEON, LSEBYP, RTCSEL and RTCEN bits in the backup domain control register (RCC_BDCTLR) are in the backup domain. Therefore, these bits are in a write-protected status after reset, and these bits can only be changed after the DBP bit in the power control register (PWR_CTLR) is set to 1. These bits can only be cleared by the backup domain reset. Any internal or external reset will not affect these bits.

V2.5 | 52
Bit | Name | Access | Description | Reset value
31 | Reserved | RO Reserved. | | 0
30 | WWDGRSTF | RO

Window watchdog reset flag:
0: No window watchdog reset occurred;
1: Window watchdog reset occurred.
When the window watchdog reset occurs, set by hardware. Cleared by writing to the RMVF bit by software.

0

29 | IWDGRSTF | RO

Independent watchdog reset flag:
0: No independent watchdog reset occurred;
1: Independent watchdog reset occurred.
When independent watchdog reset occurs, set by hardware. Cleared by writing to the RMVF bit by software.

0

28 | SFTRSTF | RO

Software reset flag:
0: No software reset occurred;
1: Software reset occurred.
When software reset occurs, set by hardware. Cleared by writing to the RMVF bit by software.

0

27 | PORRSTF | RO

Power-on/power-down reset flag:
0: No power-on/power-down reset occurred;
1: Power-on/power-down reset occurred.
When the power-on/power-down reset, set by hardware. Cleared by writing to the RMVF bit by software.

1

26 | PINRSTF | RO

External manual reset (NRST pin) flag:
0: No NRST pin reset occurred;
1: NRST pin reset occurred.
When the NRST pin reset, set by hardware. Cleared by writing to the RMVF bit by software.

0

25 | Reserved | RO Reserved. | 0
24 | RMVF | RW Remove reset flag control: 0: No effect; 1: Clear reset flag; | 0
[23:2] Reserved | RO Reserved. | 0
1 | LSIRDY | RO

Internal low-speed clock (LSI) ready flag bit (Set by hardware):
0: Internal low-speed clock (40 KHz) not ready;
1: Internal low-speed clock (40 KHz) ready.
Note: After the LSION bit is cleared, it takes 3 cycles of LSI clock to clear this bit.

0

0 | LSION | RW

Internal low-speed clock (LSI) enable control bit: 0: LSI (40KHz) oscillator disabled;
1:LSI (40KHz) oscillator enabled;

0

Note: The Write Clear Reset flag can be cleared except for BIT1 which is cleared by a power-on reset.

3.4.11 HB Peripheral Reset Register (RCC_AHBRSTR)
Offset address: 0x28

Ethernet MAC reset control:
DVP reset control:
USBOTG_FS module reset control:

3.4.12 Clock Configuration Register 2 (RCC_CFGR2)
Offset address: 0x2C
USB
USBF
HSPL
SSRC

USBHS 48MHz clock source selection:
USBHS PHY internal PLL control bit:
0: USB PHY internal PLL disabled;
1: USB PHY internal PLL enabled.
USBHSPLL reference clock selection
(USBHSPLLSRC/ USBHSDIV):
00: 3MHz;
01: 4MHz;
10: 8MHz;
11: 5MHz.
USBHSPLL reference source selection:

Gigabit Ethernet 125M clock enable bit:
Gigabit Ethernet 125M clock selection:
00: PLL2 VCO;
01: PLL3 VCO;
1x: External PB1 pin input.
RNG clock source selection:
I2S3 clock source:
0: System clock (SYSCLK);
1: PLL3 VCO.
I2S2 clock source:
PREDIV1 clock source:
0: HSE;
1: PLL2.
PLL3 multiplication factor (These bits can be written
only when PLL3 is disabled).
0000: PLL3 input clock x 2.5;
0001: PLL3 input clock x 12.5;
0010: PLL3 input clock x 4;
0011: PLL3 input clock x 5;
0100: PLL3 input clock x 6;
0101: PLL3 input clock x 7;
0110: PLL3 input clock x 8;
0111: PLL3 input clock x 9;
1000: PLL3 input clock x 10;
1001: PLL3 input clock x 11;
1010: PLL3 input clock x 12;
1011: PLL3 input clock x 13;
1100: PLL3 input clock x 14;
1101: PLL3 input clock x 15;
1110: PLL3 input clock x 16;
1111: PLL3 input clock x 20.
PLL2 multiplication factor (These bits can be written
only when PLL2 is disabled).
0000: PLL2 input clock x 2.5;
0001: PLL2 input clock x 12.5;
0010: PLL2 input clock x 4;
0011: PLL2 input clock x 5;

0100: PLL2 input clock x 6;
0101: PLL2 input clock x 7;
0110: PLL2 input clock x 8;
0111: PLL2 input clock x 9;
1000: PLL2 input clock x 10;
1001: PLL2 input clock x 11;
1010: PLL2 input clock x 12;
1011: PLL2 input clock x 13;
1100: PLL2 input clock x 14;
1101: PLL2 input clock x 15;
1110: PLL2 input clock x 16;
1111: PLL2 input clock x 20.
PREDIV2 prescaler factor (These bits can be written
only when PLL2 and PLL3 both are disabled).
0000: PREDIV2 not divided;
0001: PREDIV2 input clock divided by 2;
0010: PREDIV2 input clock divided by 3;
0011: PREDIV2 input clock divided by 4;
0100: PREDIV2 input clock divided by 5;
0101: PREDIV2 input clock divided by 6;
0110: PREDIV2 input clock divided by 7;
0111: PREDIV2 input clock divided by 8 ;
1000: PREDIV2 input clock divided by 9;
1001: PREDIV2 input clock divided by 10;
1010: PREDIV2 input clock divided by 11;
1011: PREDIV2 input clock divided by 12;
1100: PREDIV2 input clock divided by 13;
1101: PREDIV2 input clock divided by 14;
1110: PREDIV2 input clock divided by 15;
1111: PREDIV2 input clock divided by 16.
PREDIV1 prescaler factor (These bits can be written
only when PLL is disabled).
0000: PREDIV1 not divided;
0001: PREDIV1 input clock divided by 2;
0010: PREDIV1 input clock divided by 3;
0011: PREDIV1 input clock divided by 4;
0100: PREDIV1 input clock divided by 5;
0101: PREDIV1 input clock divided by 6;
0110: PREDIV1 input clock divided by 7;
0111: PREDIV1 input clock divided by 8;
1000: PREDIV1 input clock divided by 9;
1001: PREDIV1 input clock divided by 10;
1010: PREDIV1 input clock divided by 11;
1011: PREDIV1 input clock divided by 12;
1100: PREDIV1 input clock divided by 13;
1101: PREDIV1 input clock divided by 14;

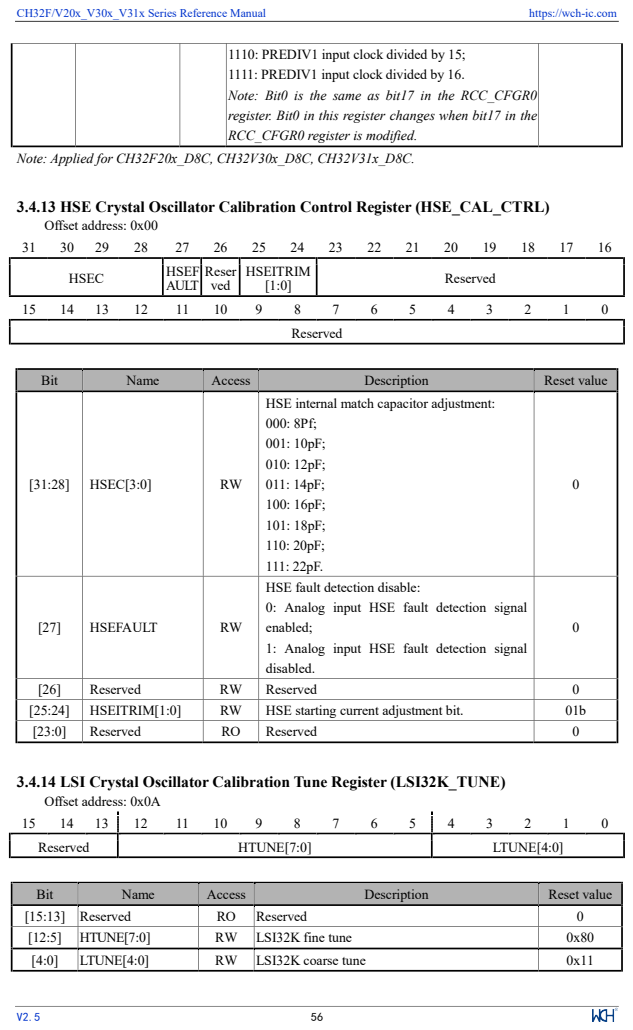
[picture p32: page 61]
HSEC; HSEF; AULT; Reser ved; HSEITRIM; Reserved; Bit; Name; Access; Description; Reset value; HSEC[3:0]; HSEFAULT; HSEITRIM[1:0]; HSE starting current adjustment bit.; HTUNE[7:0]; LTUNE[4:0]; [15:13] Reserved; [12:5] HTUNE[7:0]; LSI32K fine tune; LSI32K coarse tune

1110: PREDIV1 input clock divided by 15;
1111: PREDIV1 input clock divided by 16.
Note: Bit0 is the same as bit17 in the RCC_CFGR0
register. Bit0 in this register changes when bit17 in the
RCC_CFGR0 register is modified.

Note: Applied for CH32F20x_D8C, CH32V30x_D8C, CH32V31x_D8C.

3.4.13 HSE Crystal Oscillator Calibration Control Register (HSE_CAL_CTRL)
Offset address: 0x00

HSE internal match capacitor adjustment:
HSE fault detection disable:
0: Analog input HSE fault detection signal
enabled;
1: Analog input HSE fault detection signal
disabled.

3.4.14 LSI Crystal Oscillator Calibration Tune Register (LSI32K_TUNE)
Offset address: 0x0A

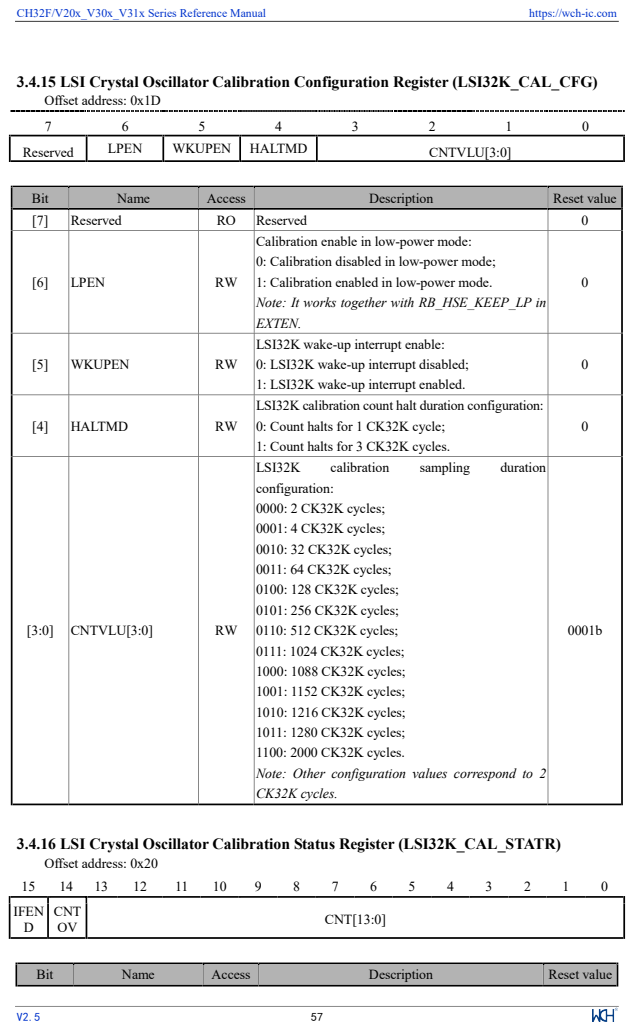
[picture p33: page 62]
Reserved; LPEN; WKUPEN; HALTMD; CNTVLU[3:0]; Bit; Name; Access; Description; Reset value; [3:0] CNTVLU[3:0]; LSI32K; calibration; sampling; duration; CNT; CNT[13:0]

3.4.15 LSI Crystal Oscillator Calibration Configuration Register (LSI32K_CAL_CFG)
Offset address: 0x1D

Calibration enable in low-power mode:
0: Calibration disabled in low-power mode;
1: Calibration enabled in low-power mode.
Note: It works together with RB_HSE_KEEP_LP in
EXTEN.
LSI32K wake-up interrupt enable:
0: LSI32K wake-up interrupt disabled;
1: LSI32K wake-up interrupt enabled.
LSI32K calibration count halt duration configuration:
0: Count halts for 1 CK32K cycle;
1: Count halts for 3 CK32K cycles.
configuration:
0000: 2 CK32K cycles;
0001: 4 CK32K cycles;
0010: 32 CK32K cycles;
0011: 64 CK32K cycles;
0100: 128 CK32K cycles;
0101: 256 CK32K cycles;
0110: 512 CK32K cycles;
0111: 1024 CK32K cycles;
1000: 1088 CK32K cycles;
1001: 1152 CK32K cycles;
1010: 1216 CK32K cycles;
1011: 1280 CK32K cycles;
1100: 2000 CK32K cycles.
Note: Other configuration values correspond to 2
CK32K cycles.

3.4.16 LSI Crystal Oscillator Calibration Status Register (LSI32K_CAL_STATR)
Offset address: 0x20
IFEN

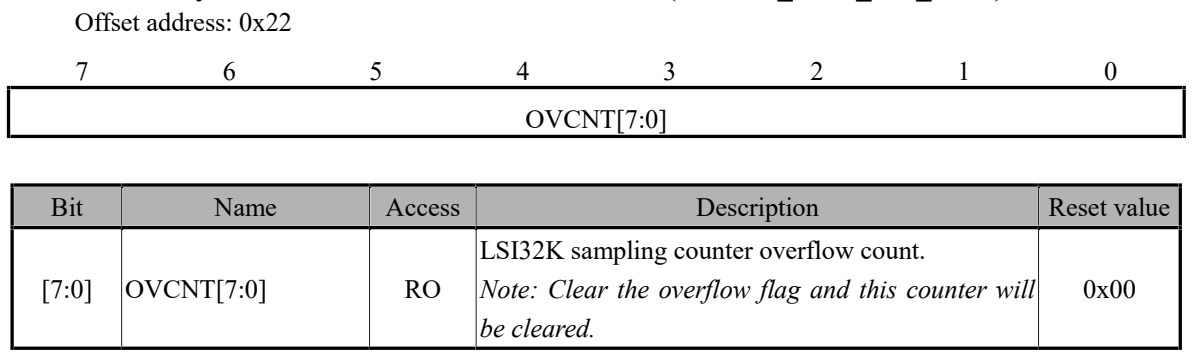
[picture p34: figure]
Offset address: 0x22; OVCNT[7:0]; Bit; Name; Access; Description; Reset value; [7:0] OVCNT[7:0]; LSI32K sampling counter overflow count.; be cleared.
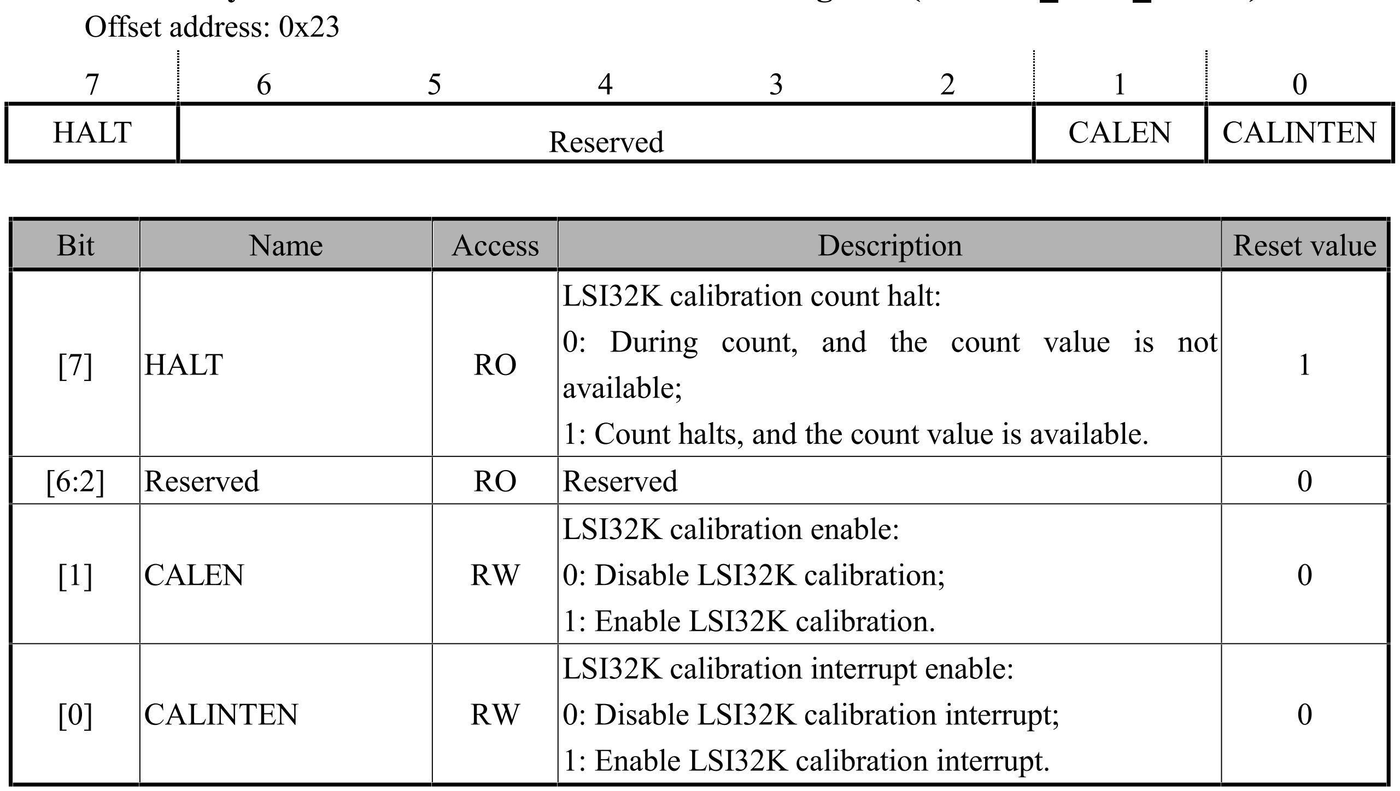
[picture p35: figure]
Offset address: 0x23; HALT; Reserved; CALEN; CALINTEN; Bit; Name; Access; Description; Reset value; LSI32K calibration count halt:; available;; [6:2] Reserved; LSI32K calibration enable: 0: Disable LSI32K calibration; 1: Enable LSI32K calibration.; LSI32K calibration interrupt enable: 0: Disable LSI32K calibration interrupt; 1: Enable LSI32K calibration interrupt.

V2.5 | 58

LSI32K calibration count end interrupt flag:

1: Sampling count ends, the flag is set.

Count for several CK32K cycles based on system

Note: The specific number of CK32K cycles can be

### 3.4.17 LSI Crystal Oscillator Calibration Counter (LSI32K_CAL_OV_CNT)

Note: Clear the overflow flag and this counter will

### 3.4.18 LSI Crystal Oscillator Calibration Control Register (LSI32K_CAL_CTRL)

0: During count, and the count value is not

1: Count halts, and the count value is available.

Note: Applied for CH32F20x_D8C and CH32V30x_D8C.

V2.5 | 59

## Chapter 4 Backup Register (BKP)

This chapter applies to the whole family of CH32F20x, CH32V20x, CH32V30x and CH32V31x.

Backup Register (BKP) provides up to 42 16-bit backup data registers, which can be used to store up to 84 bytes of user data. After the main power supply (VDD) switched off, these data can still be maintained by the power supply of VBAT without being affected by the standby status, system reset or power reset. In addition, the BKP unit also provides tamper detection management, RTC clock calibration and pulse output functions.

## 4.1 Main Features

- Tamper detection (TAMPER) function
- RTC clock calibration function
- Output RTC clock divided by 64, alarm pulse or second pulse on PC13 pin

## 4.2 Backup Data Register

After the microcontroller reset, the access to the backup register and RTC will be disabled, and the access to the backup register needs to be enabled by the following operations:
1) Set the PWREN bit and BKPEN bit in the RCC_APB1PCENR register to enable the power supply and the operating clock of the backup interface;
2) Set the DBP bit in the power control register (PWR_CTLR) to enable access to the backup register and RTC register.

### 4.2.1 Backup Data Register

The backup data register can be used as a general data buffer. Because of its feature of saving data by VBAT power when VDD is powered off, it can be used to store some important or sensitive data. But these data will be completely cleared after the tamper event occurs.

### 4.2.2 Tamper Detection

When an external signal (Rising or falling edge) is provided, a tamper event is generated, and the important information retained in the current system is cleared automatically by hardware. Tamper detection increases the security of system information.
A tamper event is generated when a transition edge is detected on the tamper detection pin (Depending on the TPAL bit). If the tamper detection interrupt is enabled, a tamper detection interrupt is also generated at the same time. As long as a tamper event occurs, all backup data registers are cleared. In addition, the hardware detection adopts the memory mode. Even if the tamper detection function is not enabled (TPE=0), the system still samples and checks whether there is a transition edge, and if the TPAL bit selection is met, the tamper event is locked in advance, and the TPE bit is set to 1 to trigger a tamper event.
For example: When TPAL=0, if it is not enabled (TPE=0) but the TAMPER pin is already high, an additional tamper event is generated (The system locks the rising edge in advance) once TPE=1. When TPAL=1, if it is not enabled (TPE=0) but the TAMPER pin is already low, an additional tamper event is generated (The system locks the falling edge in advance) once TPE=1.
Therefore, in order to avoid unnecessary tamper events from causing the backup registers to be cleared, it is recommended to set the CTE bit in the BKP_TPCSR register to 1 at the beginning of the hardware detection of the tamper pin, to firstly clear the tamper events that may have been remembered by hardware, and ensure

V2.5 | 60

that the current tamper detection pin is invalid.
Note: When the VDD power supply is disconnected, the tamper detection function is still valid. In order to avoid unnecessary backup registers of resetting data, the TAMPER pin shall be connected to the correct level correctly.

### 4.2.3 RTC Calibration

For this function, the tamper detection pin must be selected as a common IO port. Clear the TPE bit in the BKP_TPCTLR register.
- Pulse output
Configure the ASOE bit in the BKP_OCTLR register, enable RTC pulse output, set the ASOS bit, and select either the second pulse output or the alarm pulse output.
- RTC calibration
After the CCO bit in the BKP_OCTLR register is configured, the internal RTC clock divided by 64 is output to the tamper detection pin (TAMPER). Through the actual test, adjust the clock and calibrate the RTC by configuring the CAL[6:0] bits by software.

### 4.2.4 BKP Interface Reset

The BKP domain can be independently powered-on by VBAT when the VDD power is switched off. The application code controls the reset of BKP domain register, the BKP_DATAR1-10, ASOS bit and ASOE bit in the backup data register are reset by setting the BDRST bit in the RCC_BDCTLR register by software, which is not affected by the RCC peripheral interface control BKPRST bit.
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

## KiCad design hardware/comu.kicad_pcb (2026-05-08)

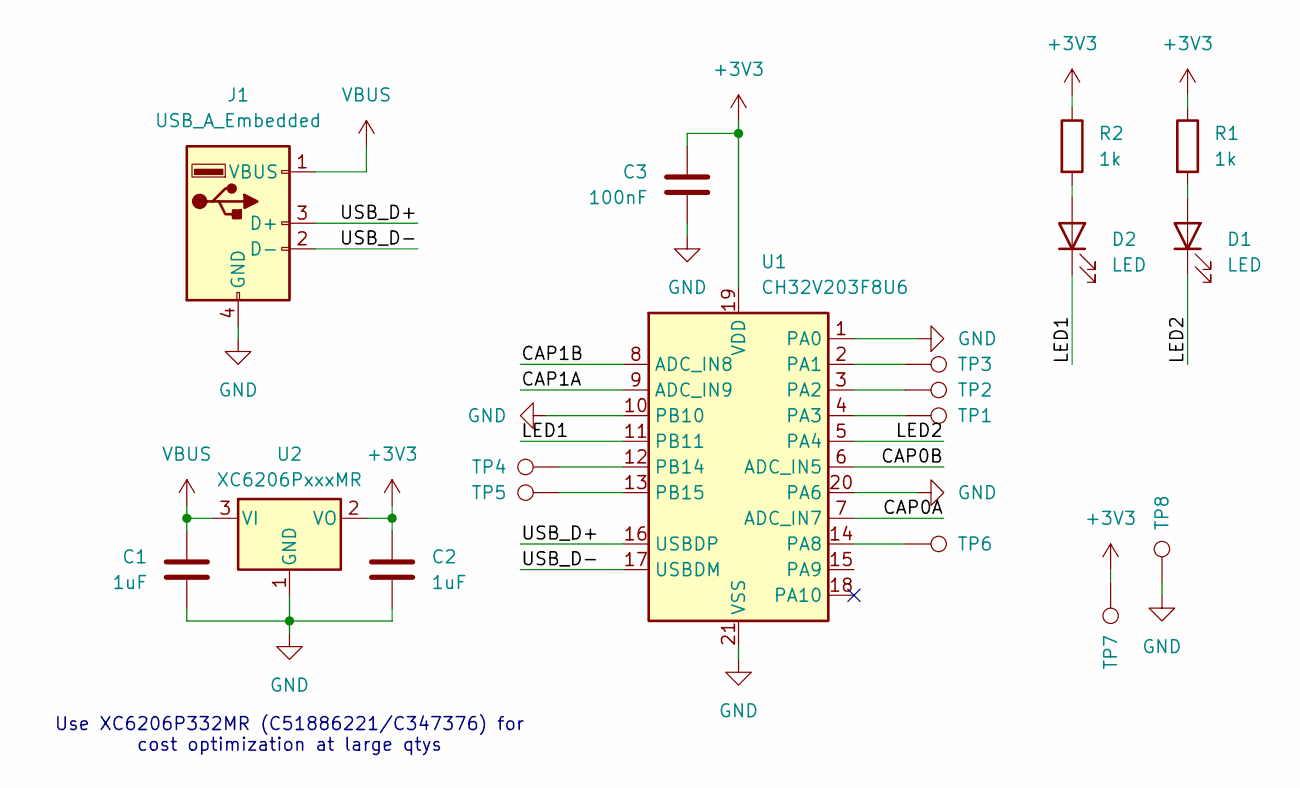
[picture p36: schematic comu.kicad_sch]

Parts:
C1, C2: 1uF; C_0402_1005Metric; LCSC Part # C52923
C3: 100nF; C_0402_1005Metric; LCSC Part # C1525
D1, D2: LED; LED_0402_1005Metric; LCSC Part # C22355736
J1: USB_A_Embedded; USB_A_Connector_PCB
R1, R2: 1k; R_0402_1005Metric; LCSC Part # C11702
TP1, TP2, TP3, TP4, TP5, TP6, TP7, TP8: TestPoint; TestPoint_Pad_D0.6mm
U1: CH32V203F8U6; QFN-20-1EP_3x3mm_P0.4mm_EP1.65x1.65mm; LCSC Part # C7570477
U2: XC6206PxxxMR; SOT-23-3; LCSC Part # C51886221

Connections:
+3V3: C2.1, C3.1, R1.1, R2.1, TP7.1 (1_1), U1.19 (VDD), U2.2 (VO)
/CAP0A: U1.7 (ADC_IN7)
/CAP0B: U1.6 (ADC_IN5)
/CAP1A: U1.9 (ADC_IN9)
/CAP1B: U1.8 (ADC_IN8)
/LED1: D2.1 (K), U1.11 (PB11)
/LED2: D1.1 (K), U1.5 (PA4)
/USB_D+: J1.3 (D+), U1.16 (USBDP)
/USB_D-: J1.2 (D-), U1.17 (USBDM)
GND: C1.2, C2.2, C3.2, J1.4 (GND), TP8.1 (1_1), U1.1 (PA0), U1.10 (PB10), U1.20 (PA6), U1.21 (VSS), U2.1 (GND)
unnamed: D1.2 (A), R1.2
unnamed: D2.2 (A), R2.2
unnamed: TP3.1 (1_1), U1.2 (PA1)
unnamed: TP2.1 (1_1), U1.3 (PA2)
unnamed: TP1.1 (1_1), U1.4 (PA3)
unnamed: TP6.1 (1_1), U1.14 (PA8)
unnamed: TP4.1 (1_1), U1.12 (PB14)
unnamed: TP5.1 (1_1), U1.13 (PB15)
VBUS: C1.1, J1.1 (VBUS), U2.3 (VI)

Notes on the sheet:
Use XC6206P332MR (C51886221/C347376) for cost optimization at large qtys

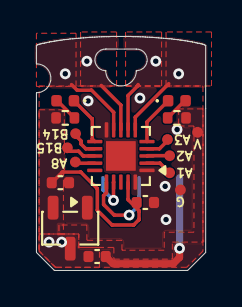
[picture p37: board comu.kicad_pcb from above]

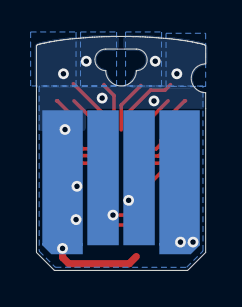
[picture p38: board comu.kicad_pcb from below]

Board: 2 copper layers, 9.4 x 13.0 mm, 19 parts (2 on the bottom side), 15 nets.

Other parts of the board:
XX1: Button solder mask removal; soldermask-removal

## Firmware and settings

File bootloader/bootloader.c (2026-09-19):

#include "bootloader.h"
#include "ch32fun.h"
#include "usb_config.h"

#include <stdio.h>

#define DISABLE_BOOTLOAD 0
#define BOOTLOADER_LED_POLARITY 1
#define BOOTLOADER_TIMEOUT_MS 5000 // If this is zero, we never run the code directly

#define DATA_SIZE 6144
#define SCRATCHPAD_SIZE (DATA_SIZE + 128)
#define BOOT_ADDRESS 0x800

// #define LED_L PA4
#define LED_L PA15
#define LED_R PB11

// TODO: Touch buttons
#define TOUCH_R1 PA9
#define TOUCH_R0 PA8
#define TOUCH_L0 PA7
#define TOUCH_L1 PA5

#define BOOTLOADER_TIMEOUT_BASE (4294967295 - Ticks_from_Ms(BOOTLOADER_TIMEOUT_MS))

#define ENDPOINTS 2

__attribute__((section(".scratchpad"))) uint8_t scratchpad[SCRATCHPAD_SIZE];
__attribute__((section(".runwordpad"))) volatile int32_t runwordpad;
__attribute__((section(".boot_address"))) volatile uint32_t boot_usercode_address;

#define min(a, b) ((a < b) ? a : b)

#ifdef USB_DEBUG
#include <string.h>
#define USB_DEBUG_PRINTF(...) printf(__VA_ARGS__)
#else
#define USB_DEBUG_PRINTF(...)
#endif

static inline void SetEPR_Status(const int ep, const uint16_t mask, const uint16_t value) {
	const uint16_t reg = USBD->EPR[ep];
	const uint16_t current_stat = reg & mask;
	// Which bits we need to toggle
	const uint16_t toggle = current_stat ^ value;

	// Conserve EA, TYPE and KIND (Non-toggle)
	uint16_t write_val = (reg & (USBD_EPR_EA | USBD_EPR_EP_TYPE_MASK | USBD_EPR_EP_KIND));
	write_val |= toggle;
	// Write 1 has no effect for CTR_RX and CTR_TX (0 clears)
	write_val |= (USBD_EPR_CTR_RX | USBD_EPR_CTR_TX);

	USBD->EPR[ep] = write_val;
}

void boot_usercode() {
	// Suspend USB interrupts etc.
	NVIC_DisableIRQ(USB_LP_CAN1_RX0_IRQn);
	USBD->CNTR = USBD_FRES;

	// Give USB time to fully reset
	Delay_Us(100);

	typedef void (*setype)(void);
	setype usercode = (setype)(BOOT_ADDRESS);
	usercode();
}

int main() {
	// Setup PLL
	SystemInit();
	runwordpad = 0;
	boot_usercode_address = (uint32_t)boot_usercode;
	SysTick->CNT = BOOTLOADER_TIMEOUT_BASE;
	funGpioInitAll();

	// Clear screen
	USB_DEBUG_PRINTF("\033[2JStarting bootloader\n");

	// Initialize ports
	GPIOA->CFGHR &= ~((0xf << (4 * 3)) | (0xf << (4 * 4)));
	GPIOA->CFGHR |= (GPIO_Speed_2MHz | GPIO_CNF_OUT_PP) << (4 * 3) | (GPIO_Speed_2MHz | GPIO_CNF_OUT_PP) << (4 * 4);

	// Set to pull-down to avoid mis-detection
	GPIOA->BSHR = (1 << (16 + 11)) | (1 << (16 + 12));

	// 42MHz clock
	RCC->CFGR0 = (RCC->CFGR0 & ~RCC_USBPRE) | RCC_USBPRE_DIV3;
	RCC->APB2PCENR |= RCC_AFIOEN | RCC_IOPAEN;
	RCC->AHBPCENR = RCC_AHBPeriph_SRAM;
	RCC->APB1PCENR |= RCC_USBEN;

#if defined(CH32V203F8)
	// Sometimes USB shares pins w/ SWD
	Delay_Ms(200);
	AFIO->PCFR1 |= AFIO_PCFR1_SWJ_CFG_DISABLE;
#endif

	USBD->CNTR = USBD_FRES; // Suspend & disable all interrupts
	USBD->CNTR = 0;

	// Delay a tad (Slightly more optimized)
	for (volatile int i = 0; i < 1000; i++)
		;

	// Initialize required registers & packet buffer description table
	USBD->BTABLE = 0;

	// 64 bytes for each buffer
	// EP0 has to be RTX
	USBD_BDT->EP[0].ADDn_TX = USBD_PMA_BASE + 0x00;
	USBD_BDT->EP[0].COUNTn_TX = 0x0; // Configured on the fly
	USBD_BDT->EP[0].ADDn_RX = USBD_PMA_BASE + 0x00;
	USBD_BDT->EP[0].COUNTn_RX = 0x8400; // 2 blocks of 32 bytes
	USBD_BDT->EP[1].ADDn_TX = USBD_PMA_BASE + 0x40;
	USBD_BDT->EP[1].COUNTn_TX = 0x0;

	EXTEN->EXTEN_CTR |= EXTEN_USBD_PU_EN;
	USBD->CNTR = USBD_CTRM | USBD_RESETM;
	USBD->ISTR = 0;
	NVIC_EnableIRQ(USB_LP_CAN1_RX0_IRQn);

	// Process loop
	int32_t localpad = (int32_t)(SysTick->CNT);
	while (1) {
#if defined(BOOTLOADER_TIMEOUT_MS) && BOOTLOADER_TIMEOUT_MS
		if (localpad < 0) {
			localpad = (int32_t)(SysTick->CNT);
			if (localpad >= 0) {
#if !defined(DISABLE_BOOTLOAD) || !DISABLE_BOOTLOAD
				boot_usercode();
#else
				localpad = 0;
#endif
			}
		}
#endif

		if (localpad > 0) {
			if (--localpad == 0) {
				typedef void (*setype)(uint32_t*, volatile int32_t*);
				setype scratchexec = (setype)(scratchpad + 4);
				scratchexec((uint32_t*)&scratchpad[0], &runwordpad);
			}
		}

		volatile uint32_t commandpad = runwordpad;
		if (commandpad) {
			localpad = commandpad - 1;
			runwordpad = 0;
		}
	}
}

void USB_LP_CAN1_RX0_IRQHandler(void) __attribute__((interrupt));
void USB_LP_CAN1_RX0_IRQHandler(void) {
	static const uint8_t zeros[] = {0, 0}; // Small macro to help reduce size

	// tx_buf and tx_pending gets executed
	// Using this to avoid code duplication
	// Saves some space
	static const uint8_t* tx_buf = NULL;
	static uint16_t tx_pending = 0;
	static uint8_t* rx_buf = NULL;
	static uint16_t rx_pending = 0;
	static uint8_t new_addr = 0;

	const uint32_t istr = USBD->ISTR;

	// Correct transfer
	if (istr & USBD_CTR) {
		const int ep = istr & USBD_EP_ID;
		const int epr = USBD->EPR[ep];

#ifdef USB_DEBUG
		if (epr & USBD_CTR_RX && epr & USBD_CTR_TX) {
			USB_DEBUG_PRINTF("UB! Both RX & TX!\n");
		}
#endif

		if (epr & USBD_CTR_RX) {
			// Endpoint 0 - control EP
			if (ep == 0) {
				// Setup packet
				if (epr & USBD_SETUP) {
					// Memory in USBD is stored in ranks of 16 bits (even though they can store
					// 32 bits)
					// What a weird design
					const uint8_t request_type = USBD_EP[0][0] & 0xFF;
					const uint8_t request = USBD_EP[0][0] >> 8;
					const uint16_t value = USBD_EP[0][1];
					const uint16_t length = USBD_EP[0][3];
					const uint8_t type = value >> 8;

					// Request 0b00100001 0x0A = SET IDLE, can be ignored
					if ((request_type & USBD_REQ_TYP_MASK) == USBD_REQ_TYP_STANDARD) {
						// Standard setup
						switch (request) {
							case USB_GET_STATUS:
								// Non remote wakeup and non self powered -> 0
								tx_buf = zeros;
								tx_pending = 2;
								break;
							case USB_SET_ADDRESS:
								new_addr = value & 0xFF;
								tx_pending = 0xFFFF;
								break;
							case USB_GET_DESCRIPTOR:
								// 64 bytes TX
								if (type == USBD_DEVICE_DESCRIPTOR) {
									tx_buf = device_descriptor;
									tx_pending = sizeof(device_descriptor);
								} else if (type == USBD_CONFIG_DESCRIPTOR) {
									tx_buf = config_descriptor;
									tx_pending = sizeof(config_descriptor);
								} else if (type == USBD_HID_DESCRIPTOR) {
									tx_buf = special_hid_desc;
									tx_pending = sizeof(special_hid_desc);
								} else if (type == USBD_STRING_DESCRIPTOR) {
									tx_buf = usb_string_descriptors[value & 0xFF];
									tx_pending = tx_buf[0];

									if ((value & 0xFF) >=
									    sizeof(usb_string_descriptors) / sizeof(usb_string_descriptors[0])) {
										USB_DEBUG_PRINTF("ERROR! STR NOTFOUND\n");
									}
								}

								tx_pending = min(tx_pending, length);

								break;
							case USB_SET_CONFIG:
								tx_pending = 0xFFFF;
								break;
							case USB_GET_INTERFACE:
								tx_buf = zeros;
								tx_pending = 1;
								break;
							default:
								tx_pending = 0xFFFF;
								USB_DEBUG_PRINTF("EP0 SETUP UNHANDLED: %d\n", request);
								break;
						}
					} else {
						// Non-standard reqs
						switch (request) {
							case HID_SET_REPORT:
								rx_pending = min(length, SCRATCHPAD_SIZE);
								rx_buf = scratchpad;
								runwordpad = 1;

								if (tx_pending != 0) {
									USB_DEBUG_PRINTF("Still TX when RX!\n");
								}
								break;
							case HID_GET_REPORT:
								tx_pending = min(length, SCRATCHPAD_SIZE);
								tx_buf = scratchpad;
								break;
							case HID_SET_IDLE:
								// Ignroe idle requests
								tx_pending = 0xFFFF;
								break;
							default:
								tx_pending = 0xFFFF;
								USB_DEBUG_PRINTF("EP0 HID UNHANDLED: %d\n", request);
								break;
						}
					}
				} else {
					// OUT RX packet
					const uint16_t len = USBD_BDT->EP[0].COUNTn_RX & 0x3FF;

					if (len != 0) {
						if (rx_pending > 0) {
							// We got a data packet!
							// Copy data over to scratchpad
							for (int i = 0; i < len; ++i) {
								rx_buf[i] = (USBD_EP[0][i / 2] >> ((i & 1) << 3)) & 0xFF;
							}

							// ACK packet (1 for each data packet)
							rx_buf += len;
							rx_pending -= len;

							if (rx_pending == 0) {
								// Finished transaction, do something
								uint32_t* last4 = (uint32_t*)(rx_buf - 4);
								// The code shall be run
								if (*last4 == 0x1234abcd) {
									*last4 = 0;
									runwordpad = 100;
									rx_buf = NULL;
								}
							}
						}

						tx_pending = 0xFFFF;
					}

					// Ignore, we can continue to recieve
					// (Probably an 0 byte control packet)
					SetEPR_Status(0, USBD_EPR_STAT_RX_MASK, USBD_EPR_STAT_RX_VALID);
				}
			} else {
				USB_DEBUG_PRINTF("EPn OUT\n");
			}
		}

		// length < sizeof -> Return start
		// length = sizeof -> Return all
		// length > sizeof -> Return partial then 0

		// 1st load for RX and auto-reload for TX
		// We need to send something:
		// - Set tx_buf and tx_pending to non-null and set TX to VALID
		// - This piece of code shall handle loading to buffer
		// - TX part shall start next transaction if we need to
		// TX detects if the operation should be continued by checking
		// if the tx_buf is null
		if (ep == 0) {
			if (tx_pending == 0) {
				tx_buf = NULL;
				// Enable recieving data
				SetEPR_Status(0, USBD_EPR_STAT_RX_MASK, USBD_EPR_STAT_RX_VALID);
			} else {
				// 0xFFFF is special variable to say 0 byte tx
				if (tx_pending == 0xFFFF) {
					tx_pending = 0;
				}

				const uint16_t tx_len = min(tx_pending, 64);
				for (int i = 0; i < tx_len; i += 2) {
					USBD_EP[0][i / 2] = *((const uint16_t*)(tx_buf + i));
				}
				USBD_BDT->EP[0].COUNTn_TX = tx_len;
				tx_buf += tx_len;
				tx_pending -= tx_len;
				SetEPR_Status(0, USBD_EPR_STAT_TX_MASK, USBD_EPR_STAT_TX_VALID);
			}
		}

		// Moved here because this flag is needed for above
		if (epr & USBD_CTR_RX) {
			// Clear RX (Toggle, 1 conserves bit)
			USBD->EPR[ep] = (USBD->EPR[ep] & (USBD_EA | USBD_EPKIND | USBD_EPTYPE)) | USBD_CTR_TX;
		}

		if (epr & USBD_CTR_TX) {
			if (ep == 0 && new_addr != 0) {
				USBD->DADDR = 0x80 | new_addr;
				new_addr = 0;
			}

			// Clear TX (Toggle)
			USBD->EPR[ep] = (USBD->EPR[ep] & (USBD_EA | USBD_EPKIND | USBD_EPTYPE)) | USBD_CTR_RX;
		}
	} else if (istr & USBD_RESET) {
		USB_DEBUG_PRINTF("\033[93mUSB RESET\033[0m\n");
		USBD->BTABLE = 0;

		for (int i = 0; i < ENDPOINTS; ++i) {
			USBD->EPR[i] = i;
		}

		SetEPR_Status(0, USBD_EPR_EP_TYPE_MASK, USBD_EPR_EP_TYPE_CTRL);
		SetEPR_Status(0, USBD_EPR_STAT_RX_MASK, USBD_EPR_STAT_RX_VALID);
		SetEPR_Status(0, USBD_EPR_STAT_TX_MASK, USBD_EPR_STAT_TX_NAK);

		// We already cleared all write-once bits so EP_KIND is 0

		// Enable USB function
		USBD->DADDR = USBD_EF;
	}

#ifdef USB_DEBUG
	if (istr & USBD_ERR) {
		USB_DEBUG_PRINTF("ERROR! USB error\n");
	}
#endif

	USBD->ISTR = ~(USBD_ESOF | USBD_SOF | USBD_WKUP | USBD_SUSP | USBD_ERR | USBD_PMAOVR | USBD_CTR | USBD_RESET);
}

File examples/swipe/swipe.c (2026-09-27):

#include "ch32fun.h"
#include "usbd.h"
#include <stdio.h>

// USB input goes here
void HandleUSBInput(int numbytes, uint8_t* data) {}

// 4096 = max
// <1024 = pressed
// -> 2560 = threshold
#define THRESHOLD 2560

// Buttons (left to right):
// A9 (PB1)
// A8 (PB0)
// A7 (PA7)
// A5 (PA5)
#define BUTTONS 4
#define BUT_L1 9
#define BUT_L2 8
#define BUT_R2 7
#define BUT_R1 5

#define TAP_MAX 500 * DELAY_MS_TIME

// Our clock runs at 8*18=144MHz
// PB1 CLK is 72MHz, PB2 is 144MHz
uint16_t sample_touch(const uint8_t key) {
	// Select converted channel
	ADC1->RSQR3 = key;

	TKey1->IDATAR1 = 0x10; // CHGOFFSET
	TKey1->RDATAR = 0x8;   // ACT_DCG -> Activates
	while (!(ADC1->STATR & ADC_FLAG_EOC))
		;

	return TKey1->RDATAR;
}

uint8_t touch_bitmap(void) {
	return ((sample_touch(BUT_L1) < THRESHOLD) << 3) | ((sample_touch(BUT_L2) < THRESHOLD) << 2) | ((sample_touch(BUT_R1) < THRESHOLD) << 1) |
	       ((sample_touch(BUT_R2) < THRESHOLD) << 0);
}

int main() {
	SystemInit();

	USBDSetup();

	RCC->APB2PCENR |= (RCC_APB2Periph_AFIO | RCC_APB2Periph_GPIOA | RCC_APB2Periph_GPIOC | RCC_APB2Periph_GPIOD | RCC_APB2Periph_ADC1);
	RCC->CFGR0 |= (0b11 << 14); // Max 14MHz. PCLK2 is 144Mhz by default so /8

	// PA4 is left led, PB11 is right
	GPIOA->CFGLR &= ~(0xf << (4 * 4));
	GPIOA->CFGLR |= (GPIO_Speed_10MHz | GPIO_CNF_OUT_PP) << (4 * 4);
	GPIOB->CFGHR &= ~(0xf << (4 * 3));
	GPIOB->CFGHR |= (GPIO_Speed_10MHz | GPIO_CNF_OUT_PP) << (4 * 3);

	// Tkeys
	GPIOB->CFGLR &= ~((0xf << (4 * 1)) | (0xf << (4 * 0)));
	GPIOB->CFGLR |= ((GPIO_Speed_In | GPIO_CNF_IN_ANALOG) << (4 * 1)) | ((GPIO_Speed_In | GPIO_CNF_IN_ANALOG) << (4 * 0));
	GPIOA->CFGLR &= ~((0xf << (4 * 5)) | (0xf << (4 * 7)));
	GPIOA->CFGLR |= ((GPIO_Speed_In | GPIO_CNF_IN_ANALOG) << (4 * 5)) | ((GPIO_Speed_In | GPIO_CNF_IN_ANALOG) << (4 * 7));

	// Reset ADC
	RCC->APB2PRSTR |= RCC_APB2Periph_ADC1;
	RCC->APB2PRSTR &= ~RCC_APB2Periph_ADC1;

	// Configure sampling times for channels
	TKey1->SAMPTR2 = (ADC_SampleTime_7Cycles5 << (3 * BUT_L1)) | (ADC_SampleTime_7Cycles5 << (3 * BUT_L2)) | (ADC_SampleTime_7Cycles5 << (3 * BUT_R2)) |
			 (ADC_SampleTime_7Cycles5 << (3 * BUT_R1));

	// Always one channel at a time
	ADC1->RSQR1 = (0 << 20);
	ADC1->RSQR2 = 0;

	ADC1->CTLR2 |= ADC_ADON;

	// The calibration isn't 100% needed
	// But we include it just in case

	// Reset calibration
	ADC1->CTLR2 |= ADC_RSTCAL;
	while (ADC1->CTLR2 & ADC_RSTCAL)
		;

	// Calibrate
	ADC1->CTLR2 |= ADC_CAL;
	while (ADC1->CTLR2 & ADC_CAL)
		;

	TKey1->CTLR1 |= ADC_BUFEN | (1 << 24); // Enable TKey

	enum { BACKGROUND, PRESS, TAP, SLIDE } state = BACKGROUND;
	uint32_t time = 0;
	uint8_t start_bm = 0;
	uint8_t bm = 0;
	while (1) {
		// Poll USB input
		poll_input();

		switch (state) {
			case BACKGROUND:
				bm = start_bm = touch_bitmap();
				if (start_bm && !(bm & 0b0011 && bm & 0b1100)) {
					time = SysTick->CNT;
					state = PRESS;
					printf("Tapped!");
				}
				break;
			case PRESS:
				uint8_t update = touch_bitmap();
				bm |= update;
				// No touch left
				if (!update) {
					uint32_t dt = (((uint32_t)SysTick->CNT) - time);
					if (dt < TAP_MAX) {
						state = TAP;
					} else {
						state = BACKGROUND;
					}
				}
				break;
			case TAP:
				if (bm & 0b0011 && bm & 0b1100) {
					// Both side tapped, blink leds to say hi
					for (int i = 0; i < 6; ++i) {
						GPIOA->OUTDR ^= (1 << 4);
						GPIOB->OUTDR ^= (1 << 11);
						Delay_Ms(300);
					}
				} else if (bm & 0b1100) {
					// Left tap
					for (int i = 0; i < 4; ++i) {
						GPIOB->OUTDR ^= (1 << 11);
						Delay_Ms(300);
					}
				} else if (bm & 0b0011) {
					// Right tap
					for (int i = 0; i < 4; ++i) {
						GPIOA->OUTDR ^= (1 << 4);
						Delay_Ms(300);
					}
				}
				state = BACKGROUND;
				break;
			case SLIDE:
				state = BACKGROUND;
				break;
		}

		Delay_Ms(10);
	}
}

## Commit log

2026-05-08 Change USB pad type to edge-connector
    [comu.kicad_pcb]
2026-07-14 Endpoint 0 setup and reset
    [bootloader.c]
2026-07-18 Correct minichlink detection & F8 package support
    [bootloader.c]
2026-07-26 New case
    [case-v2.stl, case-v3.stl, case.FCStd]
2026-07-26 New examples: touch, printf, usb tty
2026-07-26 More examples
    [bom.csv]
2026-10-19 Add pdf of schematic and field annotation
